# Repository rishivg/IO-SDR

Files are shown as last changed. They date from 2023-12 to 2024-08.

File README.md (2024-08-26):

# IO-SDR_Rev_1.1
 
IO-SDR is an open-source software-defined FPGA radio hardware platform that serves as a successor to the Pluto SDR Learning Module. Support includes and is not limited to:

- dual multichannel transmission and reception
- Gigabit Ethernet connection
- Embedded Linux SoC development
- GNU Radio blocks

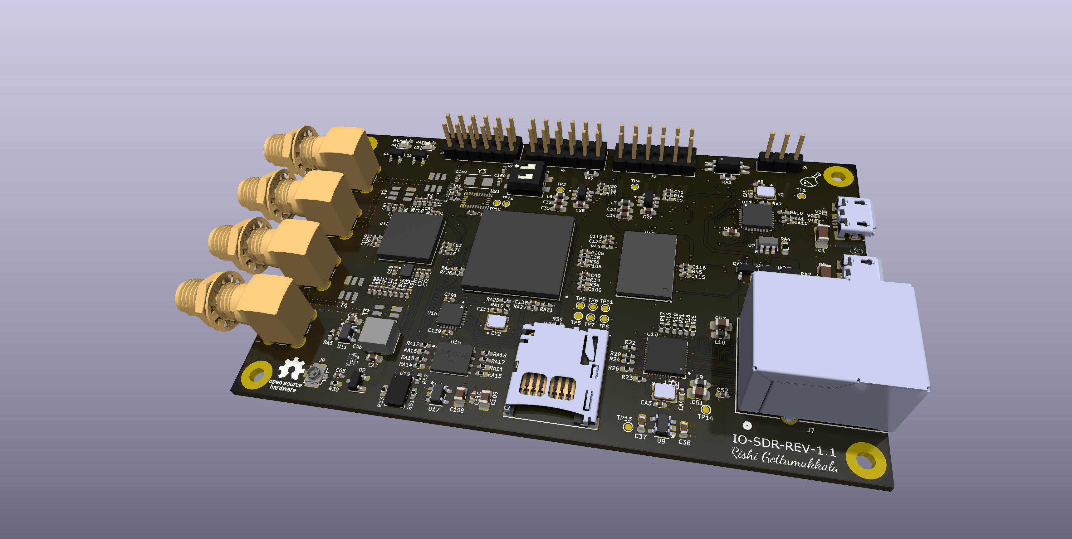
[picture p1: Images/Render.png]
Render


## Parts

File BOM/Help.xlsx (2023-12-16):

Designator | Value | Footprint | JLC PCB Part No | LCSC Part No | Description | Digikey Supplier Part No. | Supplier | Mfr. Part No. | Unit Price (USD) | Quantity | Total Price (USD) | Remarks
C1 | 22uF | Capacitor_SMD:C_1206_3216Metric_Pad1.33x1.80mm_HandSolder | C268012 |  |  |  |  |  |  | 1
C2 | 22uF | Capacitor_SMD:C_1206_3216Metric_Pad1.33x1.80mm_HandSolder | C268012 |  |  |  |  |  |  | 1
C3 | 100uF | Capacitor_SMD:C_0805_2012Metric_Pad1.18x1.45mm_HandSolder |  | C2880375 |  |  |  |  |  | 1
C4 | 22uF | Capacitor_SMD:C_0805_2012Metric_Pad1.18x1.45mm_HandSolder | C4153835 |  |  |  |  |  |  | 1
C5 | 10uF | Capacitor_SMD:C_0805_2012Metric_Pad1.18x1.45mm_HandSolder | C3015161 |  |  |  |  |  |  | 1
C6, C11, C12, C13, C15, C16, C18, C19, C25, C28, C29, C32, C33, C34, C35, CA2 | 10uF | Capacitor_SMD:C_0603_1608Metric_Pad1.08x0.95mm_HandSolder | C3039688 |  |  |  |  |  |  | 16
C7, C8 | 10uF | Capacitor_SMD:C_1206_3216Metric_Pad1.33x1.80mm_HandSolder | C136195 |  |  |  |  |  |  | 2
C9 | 1uF | Capacitor_SMD:C_0805_2012Metric_Pad1.18x1.45mm_HandSolder | C87154 |  |  |  |  |  |  | 1
C10, C14, C30, C31 | 100pF | Capacitor_SMD:C_0402_1005Metric_Pad0.74x0.62mm_HandSolder | C597051 |  |  |  |  |  |  | 4
C17, C20, CA1 | 0.1uF | Capacitor_SMD:C_0402_1005Metric_Pad0.74x0.62mm_HandSolder | C141382 |  |  |  |  |  |  | 3
C21, C23, C26, C27 | 47uF | Capacitor_SMD:C_1206_3216Metric_Pad1.33x1.80mm_HandSolder | C385907 |  |  |  |  |  |  | 4
C22, C24 | 10nF | Capacitor_SMD:C_0402_1005Metric_Pad0.74x0.62mm_HandSolder | C318577 |  |  |  |  |  |  | 2
C36 | 10uF | Capacitor_SMD:C_0603_1608Metric | C3039688 |  |  |  |  |  |  | 1
C37, C50, CA10 | 4.7uF | Capacitor_SMD:C_0603_1608Metric_Pad1.08x0.95mm_HandSolder | C99229 |  |  |  |  |  |  | 3
C38, C40, C41, C42, C43, C44, C45, C46, C47, C48, C49, C92, C93, C97, C98, C101, C102, C103, C104, C107, C138, CA8, CA11 | 0.1uF | Capacitor_SMD:C_0402_1005Metric_Pad0.74x0.62mm_HandSolder | C83056 |  |  |  |  |  |  | 23
C39, C80, C81, C90, C91, C99, C100, C105, C106, C110, C115, C116, C139, C140, C141 | 100nF | Capacitor_SMD:C_0402_1005Metric_Pad0.74x0.62mm_HandSolder | C83056 |  |  |  |  |  |  | 15
C51, C108, C109 | 10uF | Capacitor_SMD:C_0805_2012Metric_Pad1.18x1.45mm_HandSolder | C3015161 |  |  |  |  |  |  | 3
C52, C54, C55, C60, C61, C64, C66, C69, C71, C74, C75, C117, C121, C122, C123, C124, C125, C126, C127, C128, C129, C130, C131, C132, C133, C134, C136, C137 | 10nF | Capacitor_SMD:C_0402_1005Metric_Pad0.74x0.62mm_HandSolder | C318577 |  |  |  |  |  |  | 28
C53 | 0.1uF | Capacitor_SMD:C_0805_2012Metric_Pad1.18x1.45mm_HandSolder | C519980 |  |  |  |  |  |  | 1
C56, C57, C58, C62, C63, C68, C70, C111, C112, C114, C118 | 1uF | Capacitor_SMD:C_0402_1005Metric_Pad0.74x0.62mm_HandSolder | C325464 |  |  |  |  |  |  | 11
C59, CA7, CA9 | 10uF | Capacitor_SMD:C_0603_1608Metric_Pad1.08x0.95mm_HandSolder | C3039688 |  |  |  |  |  |  | 3
C65, C67, C72, C73, C82, C83, C84, C85, C86, C87, C88, C89, CA5, CA6 | 18pF | Capacitor_SMD:C_0402_1005Metric_Pad0.74x0.62mm_HandSolder | C1512022 |  |  |  |  |  |  | 14
C76, C77, C78, C79 | 1nF | Capacitor_SMD:C_0402_1005Metric_Pad0.74x0.62mm_HandSolder | C597052 |  |  |  |  |  |  | 4
C94, C95, C96, C113, C135 | 10uF | Capacitor_SMD:C_0402_1005Metric_Pad0.74x0.62mm_HandSolder | C466623 |  |  |  |  |  |  | 5 |  | Voltage Rating 10V
C119, C120 | 100pF | Capacitor_SMD:C_0402_1005Metric_Pad0.74x0.62mm_HandSolder | C597051 |  |  |  |  |  |  | 2
CA3, CA4 | 12pF | Capacitor_SMD:C_0402_1005Metric_Pad0.74x0.62mm_HandSolder |  |  | CAP CER 12PF 16V C0G/NP0 0402 | 478-KGM05ACG1C120JHTR-ND | Digikey | 478-KGM05ACG1C120JHTR-ND | 0.27 | 2
CY1 | ASDMB-33.333MHZ-LC-T | Libraries:XTAL_ASDMB-33.333MHZ-LC-T |  |  |  |  |  |  |  | 1 |  | Zero stock on Digikey
CY2 | 33.333MHz | Libraries:XTAL_ABM8AIG-25.000MHZ-12-2Z-T3 |  |  |  |  |  |  |  | 1 |  | Zero stock on Digikey
D1 | SUPK24 | Diode_SMD:D_SOD-123 |  |  |  |  |  |  |  | 1 |  | Mfr Not available
D2 | SUP5522F | Package_TO_SOT_SMD:SOT-23-3 |  |  |  |  |  |  |  | 1 |  | Mfr Not available
D3, D4 | LED6 | LED_SMD:LED_0603_1608Metric_Pad1.05x0.95mm_HandSolder | C72043 |  |  |  |  |  |  | 2
H1, H2, H3, H4 | MountingHole_Pad | MountingHole:MountingHole_2.5mm_Pad |  |  |  |  |  |  |  | 4
J1, J2 | 10118193-0001LF | Libraries:AMPHENOL_10118193-0001LF | C132562 |  |  |  |  |  |  | 2
J3 | Conn_01x03_Shielded | Connector_PinHeader_2.54mm:PinHeader_1x03_P2.54mm_Vertical | C5116482 |  |  |  |  |  |  | 1
J4, J5, J6 | CON12-254 | Connector_PinHeader_2.54mm:PinHeader_2x06_P2.54mm_Vertical | C5224012 |  |  |  |  |  |  | 3
J7 | HR911130A1 | Libraries:HR911130A_HAN |  |  |  |  |  |  |  | 1 |  | Mfr Not available
J8 | 73412-0110 | Connector_Coaxial:U.FL_Molex_MCRF_73412-0110_Vertical |  |  | CONN UMC RCPT STR 50 OHM SMD | 734120110 | Digikey | WM5587TR-ND | 0.79 | 1
J9, J10, J11, J12 | RF2-49B-T-00-50-G-HDW | Libraries:ADAMTECH_RF2-49B-T-00-50-G-HDW |  |  | RF SMA CONNECTOR | RF2-49B-T-00-50-G-HDW | Digikey | 2057-RF2-49B-T-00-50-G-HDW-ND | 3.76 | 4
J13 | 502570-0893 | Libraries:MOLEX_502570-0893 |  |  | CONN MICRO SD CARD PUSH-PUSH R/A | 5025700893 | Digikey | WM19093TR-ND | 4.42 | 1
L1, L4, L7, L8, L9 | 2.2uH | Inductor_SMD:L_0603_1608Metric_Pad1.05x0.95mm_HandSolder | C95966 |  |  |  |  |  |  | 5
L2 | R0603 | Inductor_SMD:L_0603_1608Metric_Pad1.05x0.95mm_HandSolder |  |  |  |  |  |  |  | 1 | 0 | Inductance not given
L3, L5 | R0805 | Inductor_SMD:L_0805_2012Metric_Pad1.05x1.20mm_HandSolder |  |  |  |  |  |  |  | 2
L6 | R0402 | Inductor_SMD:L_0402_1005Metric_Pad0.77x0.64mm_HandSolder |  |  |  |  |  |  |  | 1
L10 | BLM18PG181SN1 | Inductor_SMD:L_0603_1608Metric_Pad1.05x0.95mm_HandSolder | C82850 |  |  |  |  |  |  | 1
L11, L13 | 330nH | Inductor_SMD:L_0402_1005Metric_Pad0.77x0.64mm_HandSolder | C524943 |  |  |  |  |  |  | 2
L12, L14 | 330nF | Inductor_SMD:L_0402_1005Metric_Pad0.77x0.64mm_HandSolder | C524943 |  |  |  |  |  |  | 2
Q1, Q2 | S8050 | Package_TO_SOT_SMD:SOT-23 | C909746 |  |  |  |  |  |  | 2
Q3, Q4 | HR8020GS9 | Libraries:SOT23 MOSFET FOOT PRINT |  |  |  |  |  |  |  | 2 |  | Value not Given
QA1, QA3 | HR8031GS6 | Libraries:HR8031GS6 |  |  |  |  |  |  |  | 2
QA2 | HR8031GS6 | Libraries:HR8031GS6 |  |  |  |  |  |  |  | 1
R1, RA19, RA20 | 33R | Resistor_SMD:R_0402_1005Metric_Pad0.72x0.64mm_HandSolder | C100638 |  |  |  |  |  |  | 3
R2, R3, R7, R15, R22, RA6 | 10K | Resistor_SMD:R_0402_1005Metric_Pad0.72x0.64mm_HandSolder | C881063 |  |  |  |  |  |  | 6
R4, R8, R10 | 7.5K | Resistor_SMD:R_0402_1005Metric_Pad0.72x0.64mm_HandSolder | C294643 |  |  |  |  |  |  | 3
R5 | 2K | Resistor_SMD:R_0402_1005Metric_Pad0.72x0.64mm_HandSolder | C304583 |  |  |  |  |  |  | 1
R6, RA11, RA13, RA15, RA16, RA17, RA21, RA22, RA23, RA25, RA27 | 20K | Resistor_SMD:R_0402_1005Metric_Pad0.72x0.64mm_HandSolder | C328310 |  |  |  |  |  |  | 11
R9, R11 | 12K | Resistor_SMD:R_0402_1005Metric_Pad0.72x0.64mm_HandSolder | C317927 |  |  |  |  |  |  | 2
R12 | 3.3K | Resistor_SMD:R_0402_1005Metric_Pad0.72x0.64mm_HandSolder | C310224 |  |  |  |  |  |  | 1
R13, R39, R40, R41, R42, R43, R46, RA28, RA29 | 4.7K | Resistor_SMD:R_0402_1005Metric_Pad0.72x0.64mm_HandSolder | C103059 |  |  |  |  |  |  | 9
R14 | 15K | Resistor_SMD:R_0402_1005Metric_Pad0.72x0.64mm_HandSolder | C144795 |  |  |  |  |  |  | 1
R16, R17, R18, R19, R20, R24, R25, R26 | 4K7 | Resistor_SMD:R_0402_1005Metric_Pad0.72x0.64mm_HandSolder | C140158 |  |  |  |  |  |  | 8
R21 | 1K5 | Resistor_SMD:R_0402_1005Metric_Pad0.72x0.64mm_HandSolder | C102811 |  |  |  |  |  |  | 1
R23 | 2.49K%1 | Resistor_SMD:R_0402_1005Metric_Pad0.72x0.64mm_HandSolder | C409686 |  |  |  |  |  |  | 1
R27, R28 | 510R R0402 5% | Resistor_SMD:R_0402_1005Metric_Pad0.72x0.64mm_HandSolder | C881122 |  |  |  |  |  |  | 2
R29 | 50K | Potentiometer_SMD:Potentiometer_Bourns_3214W_Vertical |  |  |  |  |  |  |  | 1 |  | Mfr not given
R30 | ESD | Resistor_SMD:R_0402_1005Metric_Pad0.72x0.64mm_HandSolder |  |  |  |  |  |  |  | 1 |  | Value not given
R31, R32 | 1R | Resistor_SMD:R_0402_1005Metric_Pad0.72x0.64mm_HandSolder | C227331 |  |  |  |  |  |  | 2
R33, R34, R35, R36, R44, R45, RA1, RA2 | 2.4K | Resistor_SMD:R_0402_1005Metric_Pad0.72x0.64mm_HandSolder | C409053 |  |  |  |  |  |  | 8
R37, R38, R48 | 80.5R | Resistor_SMD:R_0402_1005Metric_Pad0.72x0.64mm_HandSolder | C170360 |  |  |  |  |  |  | 3
R47 | 240R | Resistor_SMD:R_0402_1005Metric_Pad0.72x0.64mm_HandSolder | C407743 |  |  |  |  |  |  | 1
RA3 | 4.7K | Resistor_SMD:R_0603_1608Metric_Pad0.98x0.95mm_HandSolder | C116697 |  |  |  |  |  |  | 1
RA4 | 5.1K | Resistor_SMD:R_0603_1608Metric_Pad0.98x0.95mm_HandSolder | C103696 |  |  |  |  |  |  | 1
RA5 | 0R | Resistor_SMD:R_0603_1608Metric_Pad0.98x0.95mm_HandSolder | C510292 |  |  |  |  |  |  | 1
RA7 | 1M | Resistor_SMD:R_0402_1005Metric_Pad0.72x0.64mm_HandSolder | C279988 |  |  |  |  |  |  | 1
RA8 | 14.3K | Resistor_SMD:R_0402_1005Metric_Pad0.72x0.64mm_HandSolder | C162939 |  |  |  |  |  |  | 1
RA9 | 20K | Resistor_SMD:R_0402_1005Metric_Pad0.72x0.64mm_HandSolder | C328310 |  |  |  |  |  |  | 1
RA10 | 8.06K | Resistor_SMD:R_0402_1005Metric_Pad0.72x0.64mm_HandSolder | C162792 |  |  |  |  |  |  | 1
RA12, RA14, RA18 | 1K | Resistor_SMD:R_0402_1005Metric_Pad0.72x0.64mm_HandSolder | C138287 |  |  |  |  |  |  | 3
RA24, RA26 | 100K | Resistor_SMD:R_0402_1005Metric_Pad0.72x0.64mm_HandSolder | C176119 |  |  |  |  |  |  | 2
SW1 | SW_DIP_x02 | Button_Switch_SMD:SW_DIP_SPSTx02_Slide_6.7x6.64mm_W6.73mm_P2.54mm_LowProfile_JPin |  |  |  |  |  |  |  | 1 |  | Mfr not given
T1, T2, T3, T4 | B0310J50100AHF | USB3320C-EZK-TR:B0310J50100AHF |  |  | BALUN 300MHZ-1GHZ 50/100 0805 | 1173-1050-2-ND | Digikey | B0310J50100AHF | 1.36 | 4
TP1, TP2, TP3, TP4, TP5, TP6, TP7, TP8, TP9, TP10, TP11, TP12, TP13, TP14 | TestPoint | TestPoint:TestPoint_Pad_D1.0mm |  |  |  |  |  |  |  | 14
U1 | TCMT1107 | Package_SO:SOP-4_4.4x2.6mm_P1.27mm | C81148 |  |  |  |  |  |  | 1
U2 | SY6280AAC | Libraries:SY6280AAC | C207620 |  |  |  |  |  |  | 1
U3 | TCS4615 | Libraries:TCS4615 |  |  |  |  |  |  |  | 1 |  | Not Available on Digikey
U4 | TCS4615 | Libraries:TCS4615 |  |  |  |  |  |  |  | 1 |  | Not Available on Digikey
U5 | TPS7A8101DRBT | Libraries:TPS7A8101DRBT | C139650 |  |  |  |  |  |  | 1
U6 | TPS7A8101DRBT | Libraries:TPS7A8101DRBT | C139650 |  |  |  |  |  |  | 1
U7 | TCS4615 | Libraries:TCS4615 |  |  |  |  |  |  |  | 1 |  | Not Available on Digikey
U8 | TCS4615 | Libraries:TCS4615 |  |  |  |  |  |  |  | 1 |  | Not Available on Digikey
U9, U11, U17 | RT9193-33B | Libraries:RT9193-33B |  |  |  |  |  |  |  | 3 |  | Not Available on Digikey
U10 | RTL8211E-VB-CG | Libraries:RTL8211E-VB-CG | C90735 |  |  |  |  |  |  | 1
U12 | AD9361BBCZ | Libraries:AD9361BBCZ | C515884 |  |  |  |  |  |  | 1
U13 | USB3320C-EZK-TR | Libraries:USB3320C-EZK-TR | C132156 |  |  |  |  |  |  | 1
U14 | XC7Z010-1CLG400I | Libraries:XC7Z010-1CLG400I | C2840994 |  |  |  |  |  |  | 1
U15 | MX25U1635EZNI-10G | Libraries:MX25U1635EZNI-10G |  |  | IC FLASH 16MBIT SPI/QUAD 8WSON | 1092-1076-ND | Digikey | MX25U1635EZNI-10G | 1.08 | 1
U16 | TXS02612RTWR | Libraries:TXS02612RTWR | C140276 |  |  |  |  |  |  | 1
U18 | H5TQ4G63AFR | Libraries:H5TQ4G63AFR |  |  |  |  |  |  |  | 1
V1, V2, V3 | HR02X5V | Libraries:HR02X5V |  |  |  |  |  |  |  | 3
Y1 | 25MHz | Libraries:XTAL_TSX-3225_25.0000MF10P-C0 |  |  | CRYSTAL 25.0000MHZ 18PF SMD | TSX-322525.0000MF10P-C-ND | Digikey | TSX-3225 25.0000MF10P-C | 0.84 | 1
Y2 | 25MHz | Libraries:XTAL_TSX-3225_25.0000MF10P-C0 |  |  | CRYSTAL 25.0000MHZ 18PF SMD | TSX-322525.0000MF10P-C-ND | Digikey | TSX-3225 25.0000MF10P-C | 0.84 | 1

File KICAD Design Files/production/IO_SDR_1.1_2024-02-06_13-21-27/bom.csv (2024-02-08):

Designator | Footprint | Quantity | Value | LCSC Part #
C1, C2 | 1206 | 2 | 22uF
C10, C119, C120, C14, C30, C31 | 0402 | 6 | 100pF
C100, C105, C106, C110, C115, C116, C139, C140, C141, C146, C147, C39, C80, C81, C90, C91, C99 | 0402 | 17 | 100nF
C101, C102, C103, C104, C107, C138, C17, C20, C38, C40, C41, C42, C43, C44, C45, C46, C47, C48, C49, C92, C93, C97, C98, CA1, CA11, CA8 | 0402 | 26 | 0.1uF
C108, C109, C5, C51 | 0805 | 4 | 10uF
C11, C12, C13, C15, C16, C18, C19, C25, C28, C29, C32, C33, C34, C35, C36, C59, C6, CA2, CA7, CA9 | 0603 | 20 | 10uF
C111, C112, C114, C118, C148, C56, C57, C58, C62, C63, C68, C70 | 0402 | 12 | 1uF
C113, C135, C94, C95, C96 | 0402 | 5 | 10uF
C117, C121, C122, C123, C124, C125, C126, C127, C128, C129, C130, C131, C132, C133, C134, C136, C137, C22, C24, C52, C54, C55, C60, C61, C64, C66, C69, C71, C74, C75 | 0402 | 30 | 10nF
C149, C150 | 0402 | 2 | 22pf
C21, C23, C26, C27 | 1206 | 4 | 47uF
C3 | 0805 | 1 | 100uF
C37, C50, CA10 | 0603 | 3 | 4.7uF
C4 | 0805 | 1 | 22uF
C53 | 0805 | 1 | 0.1uF
C65, C67, C72, C73, C82, C83, C84, C85, C86, C87, C88, C89, CA5, CA6 | 0402 | 14 | 18pF
C7, C8 | 1206 | 2 | 10uF
C76, C77, C78, C79 | 0402 | 4 | 1nF
C9 | 0805 | 1 | 1uF
CA3, CA4 | 0402 | 2 | 12pF
CY1 | ASDMB-33.333MHZ-XY-T | 1 | ASDMB-33.333MHZ-XY-T
CY2 | ABM8AIG-33.000MHZ-12-D2Z-T | 1 | ABM8AIG-33.000MHZ-12-D2Z-T
D1 | D_SOD-123 | 1 | DSK24
D2 | SOT-23-3 | 1 | WSB5522F-3/TR
D3, D4 | 0603 | 2 | LED6
J13 | 5025700893 | 1 | 5025700893
L1, L4, L7, L8, L9 | 0603 | 5 | 2.2uH
L10 | 0603 | 1 | BLM18PG181SN1 | AD93
L11, L13 | 0402 | 2 | 330nH
L12, L14 | 0402 | 2 | 330nF
L2 | BLM18AG601SN1D | 1 | BLM18AG601SN1D
L3, L5 | 7427920415 | 2 | 7427920415
L6 | BLM15AG601SN1D | 1 | BLM15AG601SN1D
Q1, Q2 | SOT-23 | 2 | S8050
Q3, Q4 | SOT23 MOSFET FOOT PRINT | 2 | ~
QA1, QA2, QA3 | HR8031GS6 | 3 | HR8031GS6
R1, RA19, RA20 | 0402 | 3 | 33R
R10, R4, R8 | 0402 | 3 | 7.5K
R11, R9 | 0402 | 2 | 12K
R12 | 0402 | 1 | 3.3K
R13, R39, R40, R41, R42, R43, R46, R51, R52, R53, RA28, RA29 | 0402 | 12 | 4.7K
R14 | 0402 | 1 | 15K
R15, R2, R22, R3, R56, R7, RA6 | 0402 | 7 | 10K
R16, R17, R18, R19, R20, R24, R25, R26 | 0402 | 8 | 4K7
R21 | 0402 | 1 | 1K5
R23 | 0402 | 1 | 2.49K%1
R27, R28 | 0402 | 2 | 510R
R29 | Potentiometer_Bourns_3214W_Vertical | 1 | 50K
R30 | 0402 | 1 | ESD
R31, R32 | 0402 | 2 | 1R
R33, R34, R35, R36, R44, R45, RA1, RA2 | 0402 | 8 | 2.4K
R37, R38, R48 | 0402 | 3 | 80.6R
R47 | 0402 | 1 | 240R
R5 | 0402 | 1 | 2K
R6, RA11, RA13, RA15, RA16, RA17, RA21, RA22, RA23, RA25, RA27, RA9 | 0402 | 12 | 20K
RA10 | 0402 | 1 | 8.06K
RA12, RA14, RA18 | 0402 | 3 | 1K
RA24, RA26 | 0402 | 2 | 100K
RA3 | 0603 | 1 | 4.7K
RA4 | 0603 | 1 | 5.1K
RA5 | 0603 | 1 | 0R
RA7 | 0402 | 1 | 1M
RA8 | 0402 | 1 | 14.3K
T1, T2, T3, T4 | XFMR_TCM1-63AX+ | 4 | TCM1-63AX+
U1 | SOP-4_4.4x2.6mm_P1.27mm | 1 | TCMT1107
U10 | RTL8211E-VB-CG | 1 | RTL8211E-VB-CG
U11, U17, U9 | RT9193-33GB | 3 | RT9193-33GB
U12 | AD9363BBCZ | 1 | AD9363BBCZ
U13 | USB3320C-EZK-TR | 1 | USB3320C-EZK-TR
U14 | XC7Z010-1CLG400I | 1 | XC7Z010-1CLG400I
U15 | MX25U1635EZNI-10G | 1 | MX25U1635EZNI-10G
U16 | TXS02612RTWR | 1 | TXS02612RTWR
U18 | H5TQ4G63EFR-RDC | 1 | H5TQ4G63EFR-RDC
U19 | LGA-8_3x5mm_P1.25mm | 1 | MS5611-01BA03
U2 | SY6280AAC | 1 | SY6280AAC
U21 | IC_BNO080 | 1 | BNO085
U3, U7, U8 | TCS4615 | 3 | TCS4615
U4 | TCS4615 | 1 | TCS4615
U5, U6 | TPS7A8101DRBT | 2 | TPS7A8101DRBT
V1, V2, V3 | HR02X5V | 3 | HR02X5V
Y1 | TSX-3225 25.0000MF10P-C0 | 1 | 25MHz | TSX-3225 25.0000MF10P-C0
Y2 | TSX-3225 25.0000MF10P-C0 | 1 | 25MHz
Y3 | Crystal_SMD_Qantek_QC5CB-2Pin_5x3.2mm | 1 | 32.768kHz

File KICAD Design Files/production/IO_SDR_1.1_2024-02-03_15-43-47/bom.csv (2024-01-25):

Designator | Footprint | Quantity | Value | LCSC Part #
C1, C2 | 1206 | 2 | 22uF
C10, C119, C120, C14, C30, C31 | 0402 | 6 | 100pF
C100, C105, C106, C110, C115, C116, C139, C140, C141, C146, C147, C39, C80, C81, C90, C91, C99 | 0402 | 17 | 100nF
C101, C102, C103, C104, C107, C138, C17, C20, C38, C40, C41, C42, C43, C44, C45, C46, C47, C48, C49, C92, C93, C97, C98, CA1, CA11, CA8 | 0402 | 26 | 0.1uF
C108, C109, C5, C51 | 0805 | 4 | 10uF
C11, C12, C13, C15, C16, C18, C19, C25, C28, C29, C32, C33, C34, C35, C36, C59, C6, CA2, CA7, CA9 | 0603 | 20 | 10uF
C111, C112, C114, C118, C148, C56, C57, C58, C62, C63, C68, C70 | 0402 | 12 | 1uF
C113, C135, C94, C95, C96 | 0402 | 5 | 10uF
C117, C121, C122, C123, C124, C125, C126, C127, C128, C129, C130, C131, C132, C133, C134, C136, C137, C22, C24, C52, C54, C55, C60, C61, C64, C66, C69, C71, C74, C75 | 0402 | 30 | 10nF
C149, C150 | 0402 | 2 | 22pf
C21, C23, C26, C27 | 1206 | 4 | 47uF
C3 | 0805 | 1 | 100uF
C37, C50, CA10 | 0603 | 3 | 4.7uF
C4 | 0805 | 1 | 22uF
C53 | 0805 | 1 | 0.1uF
C65, C67, C72, C73, C82, C83, C84, C85, C86, C87, C88, C89, CA5, CA6 | 0402 | 14 | 18pF
C7, C8 | 1206 | 2 | 10uF
C76, C77, C78, C79 | 0402 | 4 | 1nF
C9 | 0805 | 1 | 1uF
CA3, CA4 | 0402 | 2 | 12pF
CY1 | XTAL_ASDMB-33.333MHZ-LC-T | 1 | ASDMB-33.333MHZ-LC-T
CY2 | XTAL_ABM8AIG-25.000MHZ-12-2Z-T3 | 1 | 33.333MHz
D1 | D_SOD-123 | 1 | SUPK24
D2 | SOT-23-3 | 1 | SUP5522F
D3, D4 | 0603 | 2 | LED6
H1, H2, H3, H4 | MountingHole_2.5mm_Pad | 4 | MountingHole_Pad
J1, J2 | AMPHENOL_10118193-0001LF | 2 | 10118193-0001LF
J10, J11, J12, J9 | ADAMTECH_RF2-49B-T-00-50-G-HDW | 4 | RF2-49B-T-00-50-G-HDW
J13 | MOLEX_502570-0893 | 1 | 502570-0893
J3 | PinHeader_1x03_P2.54mm_Vertical | 1 | Conn_01x03_Shielded
J4, J5, J6 | PinHeader_2x06_P2.54mm_Vertical | 3 | CON12-254
J7 | HR911130A_HAN | 1 | HR911130A1
J8 | U.FL_Molex_MCRF_73412-0110_Vertical | 1 | 73412-0110
L1, L4, L7, L8, L9 | 0603 | 5 | 2.2uH
L10 | 0603 | 1 | BLM18PG181SN1
L11, L13 | 0402 | 2 | 330nH
L12, L14 | 0402 | 2 | 330nF
L2 | 0603 | 1 | R0603
L3, L5 | 0805 | 2 | R0805
L6 | 0402 | 1 | R0402
Q1, Q2 | SOT-23 | 2 | S8050
Q3, Q4 | SOT23 MOSFET FOOT PRINT | 2 | ~
QA1, QA2, QA3 | HR8031GS6 | 3 | HR8031GS6
R1, RA19, RA20 | 0402 | 3 | 33R
R10, R4, R8 | 0402 | 3 | 7.5K
R11, R9 | 0402 | 2 | 12K
R12 | 0402 | 1 | 3.3K
R13, R39, R40, R41, R42, R43, R46, R51, R52, R53, RA28, RA29 | 0402 | 12 | 4.7K
R14 | 0402 | 1 | 15K
R15, R2, R22, R3, R56, R7, RA6 | 0402 | 7 | 10K
R16, R17, R18, R19, R20, R24, R25, R26 | 0402 | 8 | 4K7
R21 | 0402 | 1 | 1K5
R23 | 0402 | 1 | 2.49K%1
R27, R28 | 0402 | 2 | 510R R0402 5%
R29 | Potentiometer_Bourns_3214W_Vertical | 1 | 50K
R30 | 0402 | 1 | ESD
R31, R32 | 0402 | 2 | 1R
R33, R34, R35, R36, R44, R45, RA1, RA2 | 0402 | 8 | 2.4K
R37, R38, R48 | 0402 | 3 | 80.5R
R47 | 0402 | 1 | 240R
R5 | 0402 | 1 | 2K
R6, RA11, RA13, RA15, RA16, RA17, RA21, RA22, RA23, RA25, RA27, RA9 | 0402 | 12 | 20K
RA10 | 0402 | 1 | 8.06K
RA12, RA14, RA18 | 0402 | 3 | 1K
RA24, RA26 | 0402 | 2 | 100K
RA3 | 0603 | 1 | 4.7K
RA4 | 0603 | 1 | 5.1K
RA5 | 0603 | 1 | 0R
RA7 | 0402 | 1 | 1M
RA8 | 0402 | 1 | 14.3K
SW1 | SW_DIP_SPSTx02_Slide_6.7x6.64mm_W6.73mm_P2.54mm_LowProfile_JPin | 1 | SW_DIP_x02
T1, T2, T3, T4 | XFMR_TCM1-63AX_ | 4 | TCM1-63AX_
TP1, TP10, TP11, TP12, TP13, TP14, TP2, TP3, TP4, TP5, TP6, TP7, TP8, TP9 | TestPoint_Pad_D1.0mm | 14 | TestPoint
U1 | SOP-4_4.4x2.6mm_P1.27mm | 1 | TCMT1107
U10 | RTL8211E-VB-CG | 1 | RTL8211E-VB-CG
U11, U17, U9 | RT9193-33B | 3 | RT9193-33B
U12 | AD9361BBCZ | 1 | AD9361BBCZ
U13 | USB3320C-EZK-TR | 1 | USB3320C-EZK-TR
U14 | XC7Z010-1CLG400I | 1 | XC7Z010-1CLG400I
U15 | MX25U1635EZNI-10G | 1 | MX25U1635EZNI-10G
U16 | TXS02612RTWR | 1 | TXS02612RTWR
U18 | H5TQ4G63AFR | 1 | H5TQ4G63AFR
U19 | LGA-8_3x5mm_P1.25mm | 1 | MS5611-01BA
U2 | SY6280AAC | 1 | SY6280AAC
U21 | IC_BNO080 | 1 | BNO085
U3, U7, U8 | TCS4615 | 3 | TCS4615
U4 | TCS4615 | 1 | TCS4615
U5, U6 | TPS7A8101DRBT | 2 | TPS7A8101DRBT
V1, V2, V3 | HR02X5V | 3 | HR02X5V
Y1 | XTAL_TSX-3225_25.0000MF10P-C0 | 1 | 25MHz | TSX-3225_25.0000MF10P-C0
Y2 | XTAL_TSX-3225_25.0000MF10P-C0 | 1 | 25MHz
Y3 | Crystal_SMD_Qantek_QC5CB-2Pin_5x3.2mm | 1 | 32.768kHz

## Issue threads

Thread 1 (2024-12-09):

IO-SDR board license

goran-mahovlic, 2024-12-09:
HI @rishivg, thank you for sharing this board it looks super nice!
I was searching for ETH PHY for my extension boards so I found your SDR board.
Just checked design and it looks fantastic!

If possible I would like to reuse your ETH PHY on experimental Extension boards for Olimex https://github.com/intergalaktik/Extension_Boards_for_Olimex_GateMate

But before I reuse part of your design I just wanted to ask you if this is OK with you, and if it is what is your board license.

by the way there is now PCB2BLENDER plugin for KiCad - try to use it as blender render looks really amazing!

https://github.com/30350n/pcb2blender

Thanks again!
Goran

rishivg, 2024-12-11:
Hi, my board license is currently set to GPL-3.0. Yes, It is totally ok if you use the ETH PHY, and thanks for the blender recommendation!

goran-mahovlic, 2024-12-11:
> Hi, my board license is currently set to GPL-3.0. Yes, It is totally ok if you use the ETH PHY, and thanks for the blender recommendation!

Thank you!

I have already created repository ethIO - I just added schematic links of your repository so that users can trace development.

https://github.com/intergalaktik/Extension_Boards_for_Olimex_GateMate/blob/main/ethIO/ethIO.pdf

I do not know if GPL-3.0 is valid for HW projects - but I will ask NLnet what would complement that license, until lthen I have change license to GPLv3

I use CERN-OHL-S v2 or CERN-OHL-P v2 on all boards...

I think CERN-OHL-P would be almost like GPLv3 for SW

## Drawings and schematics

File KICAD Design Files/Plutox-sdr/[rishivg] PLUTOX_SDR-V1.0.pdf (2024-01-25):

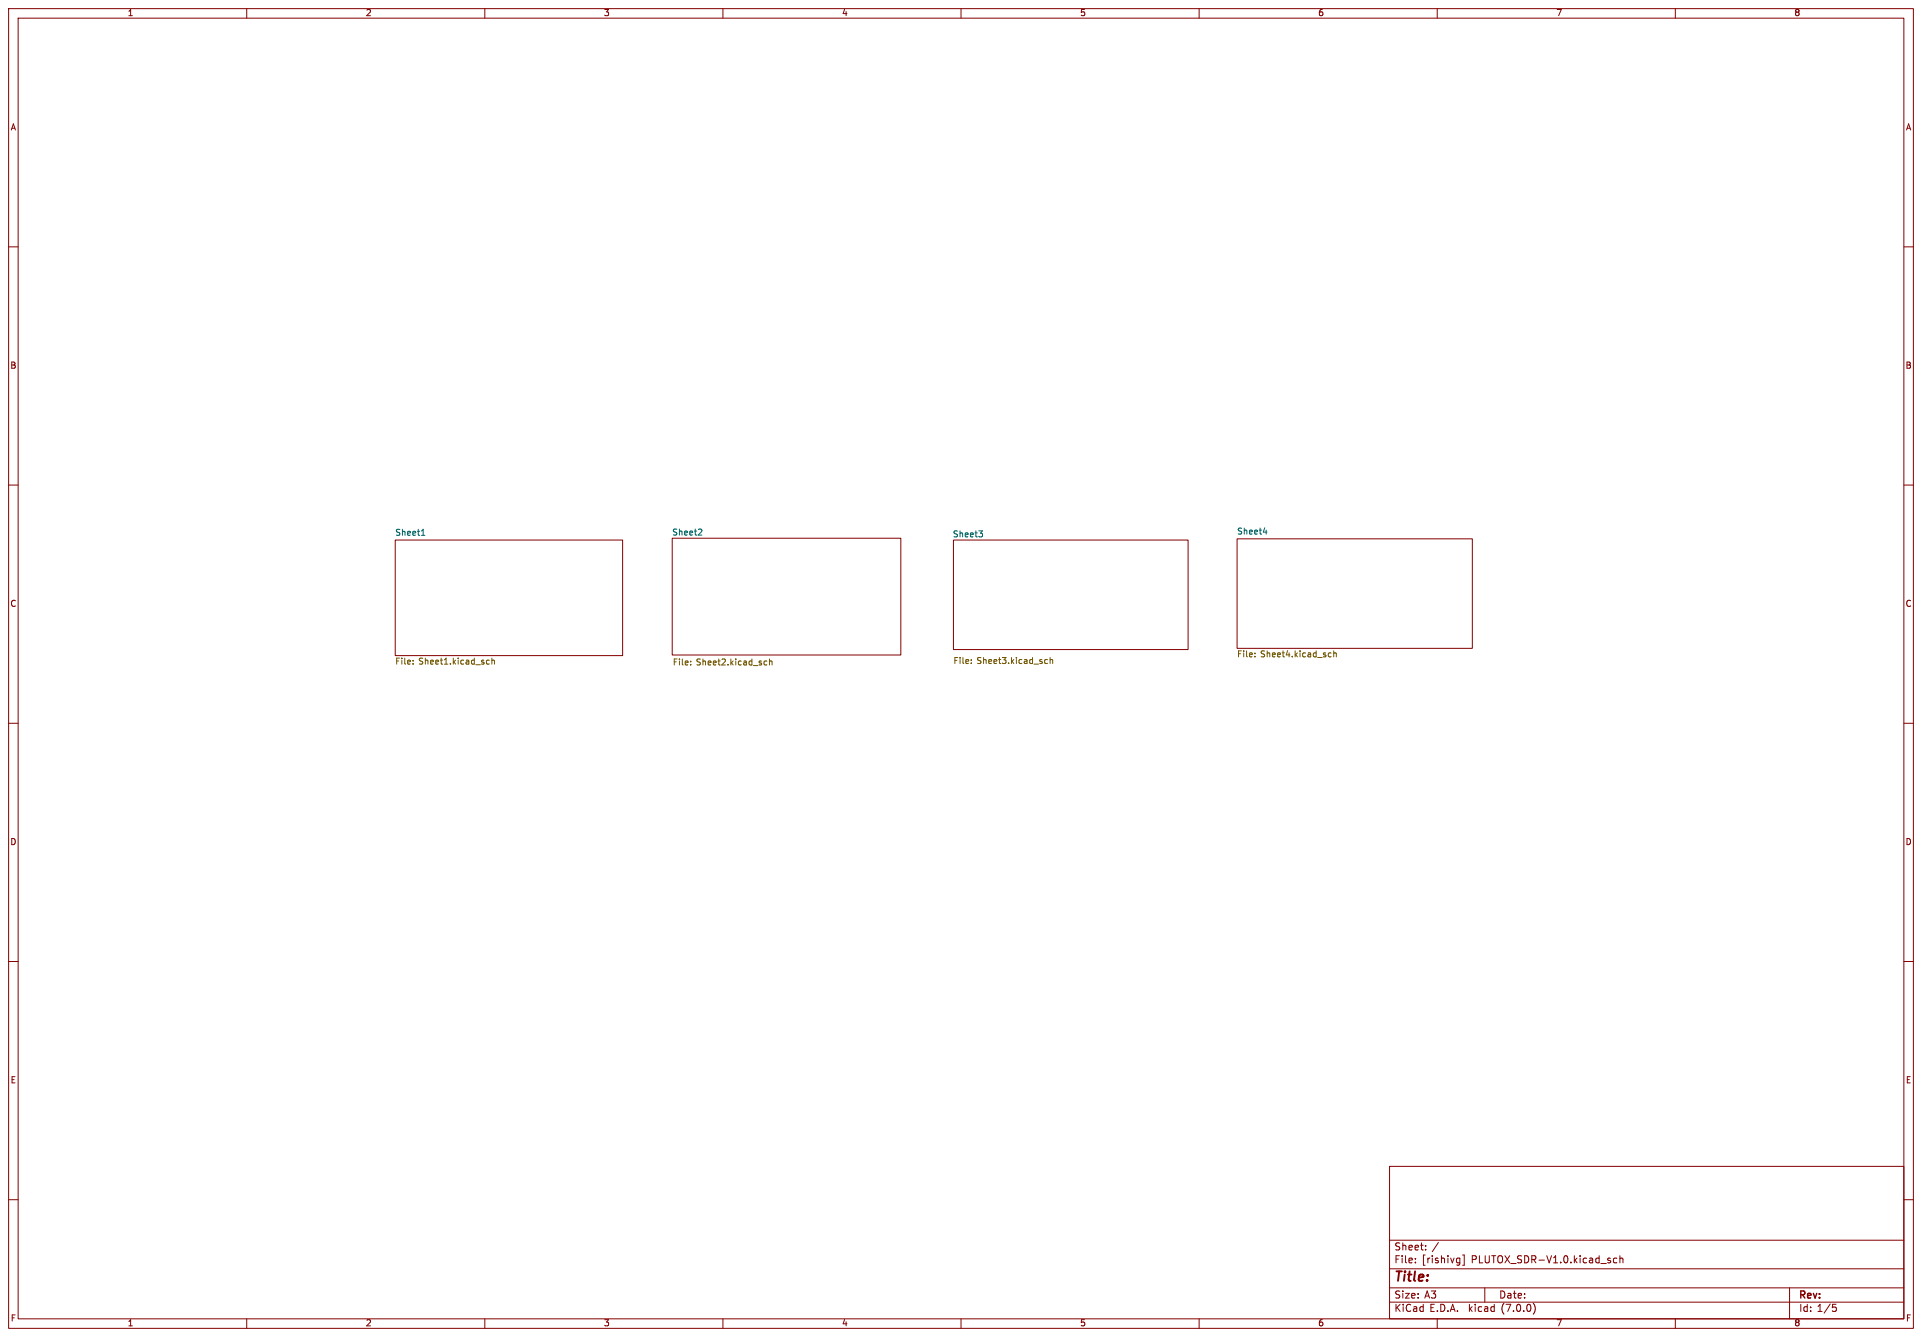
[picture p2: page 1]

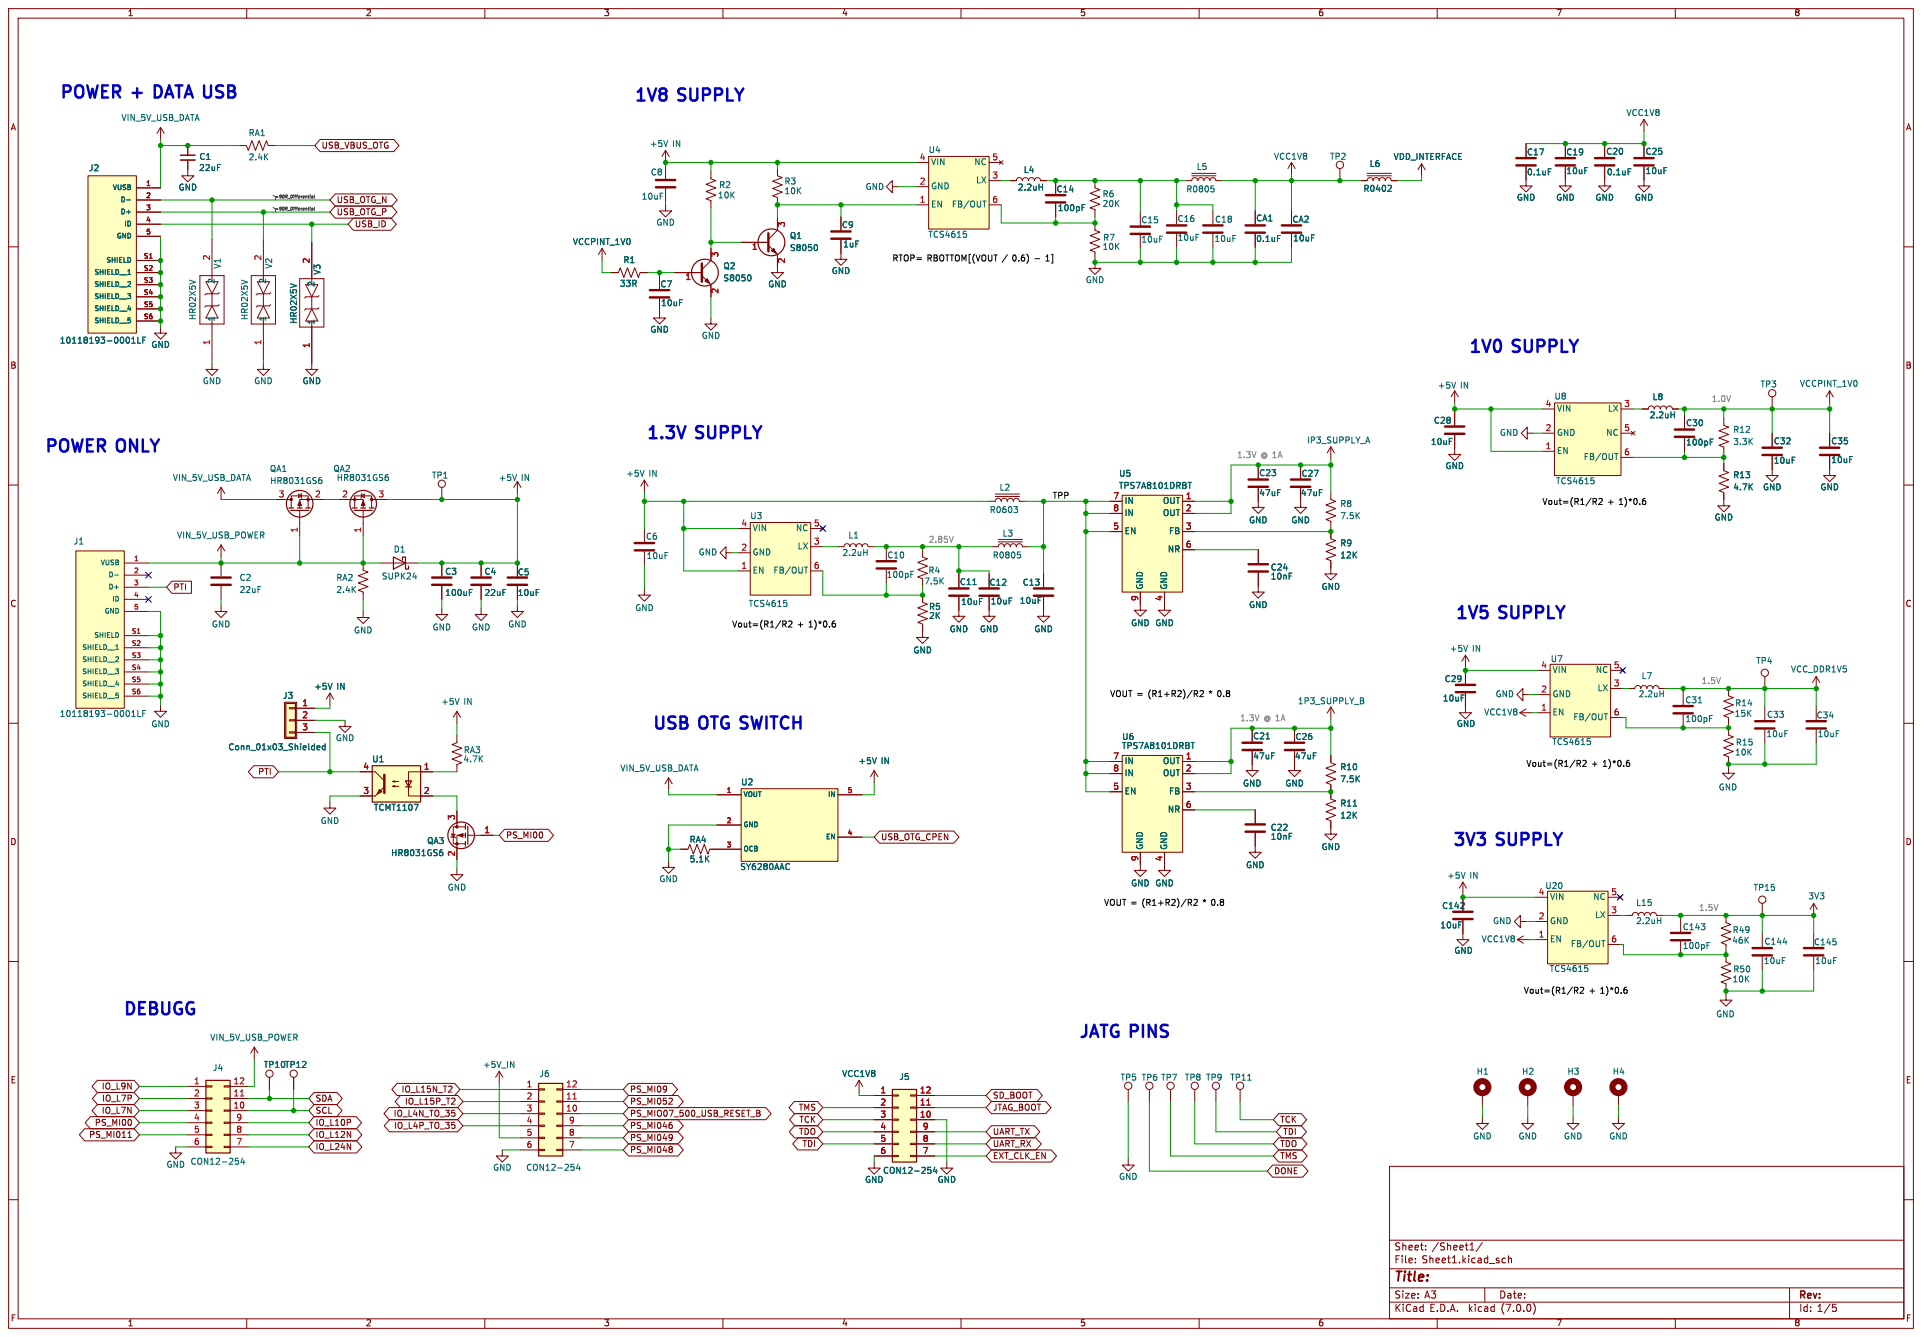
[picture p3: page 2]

47uF U6 TPS7A8101DRBT OUT 1 OUT 2 FB 3 GND

47uF OUT 1 OUT 2 FB 3 GND

Id: 1/5 Title: File: Sheet1.kicad_sch Sheet: /Sheet1/

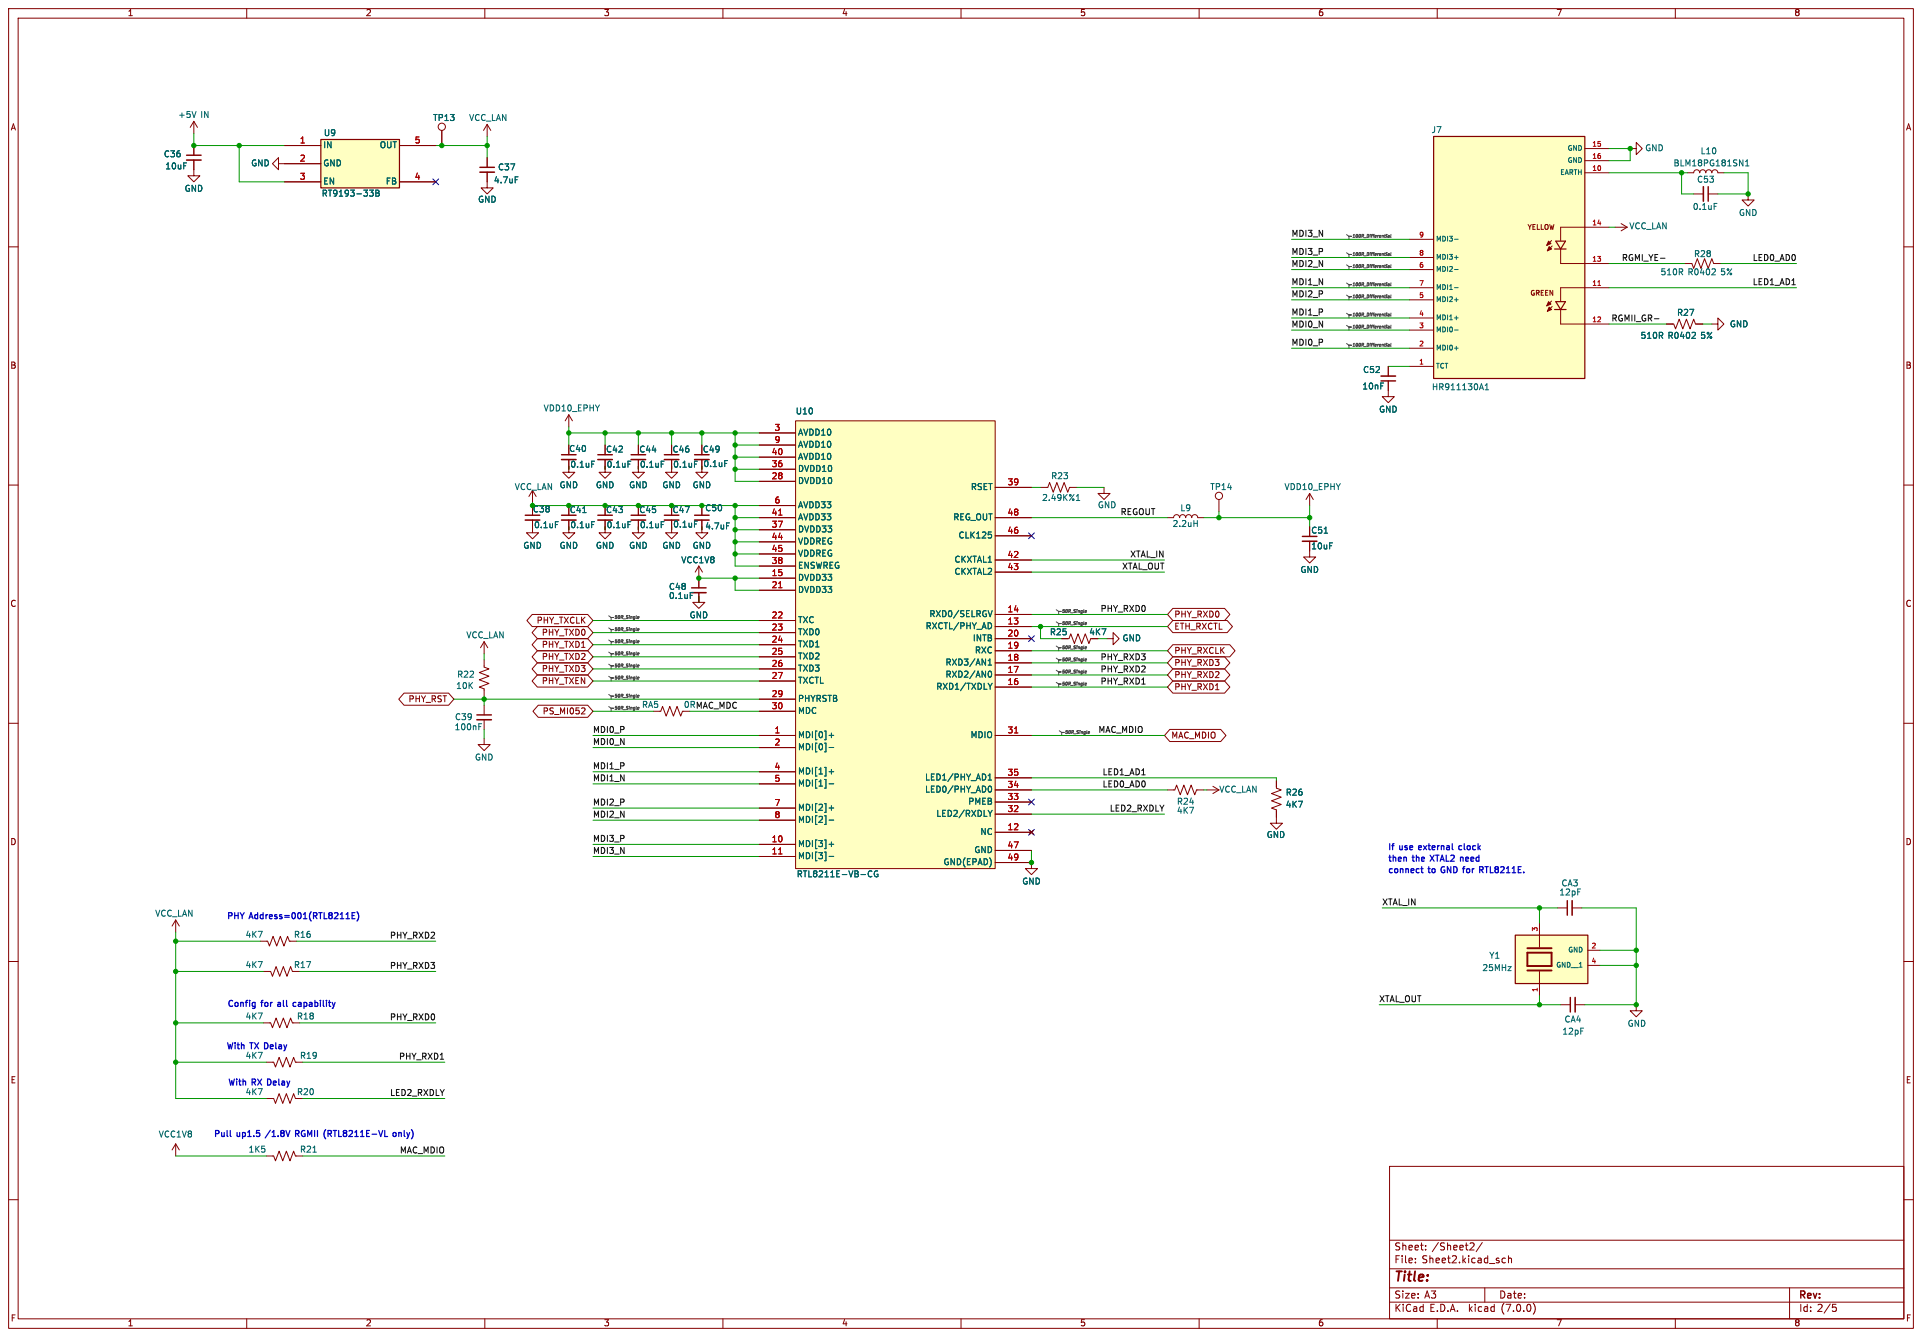
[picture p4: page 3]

connect to GND for RTL8211E.

Config for all capability With TX Delay With RX Delay

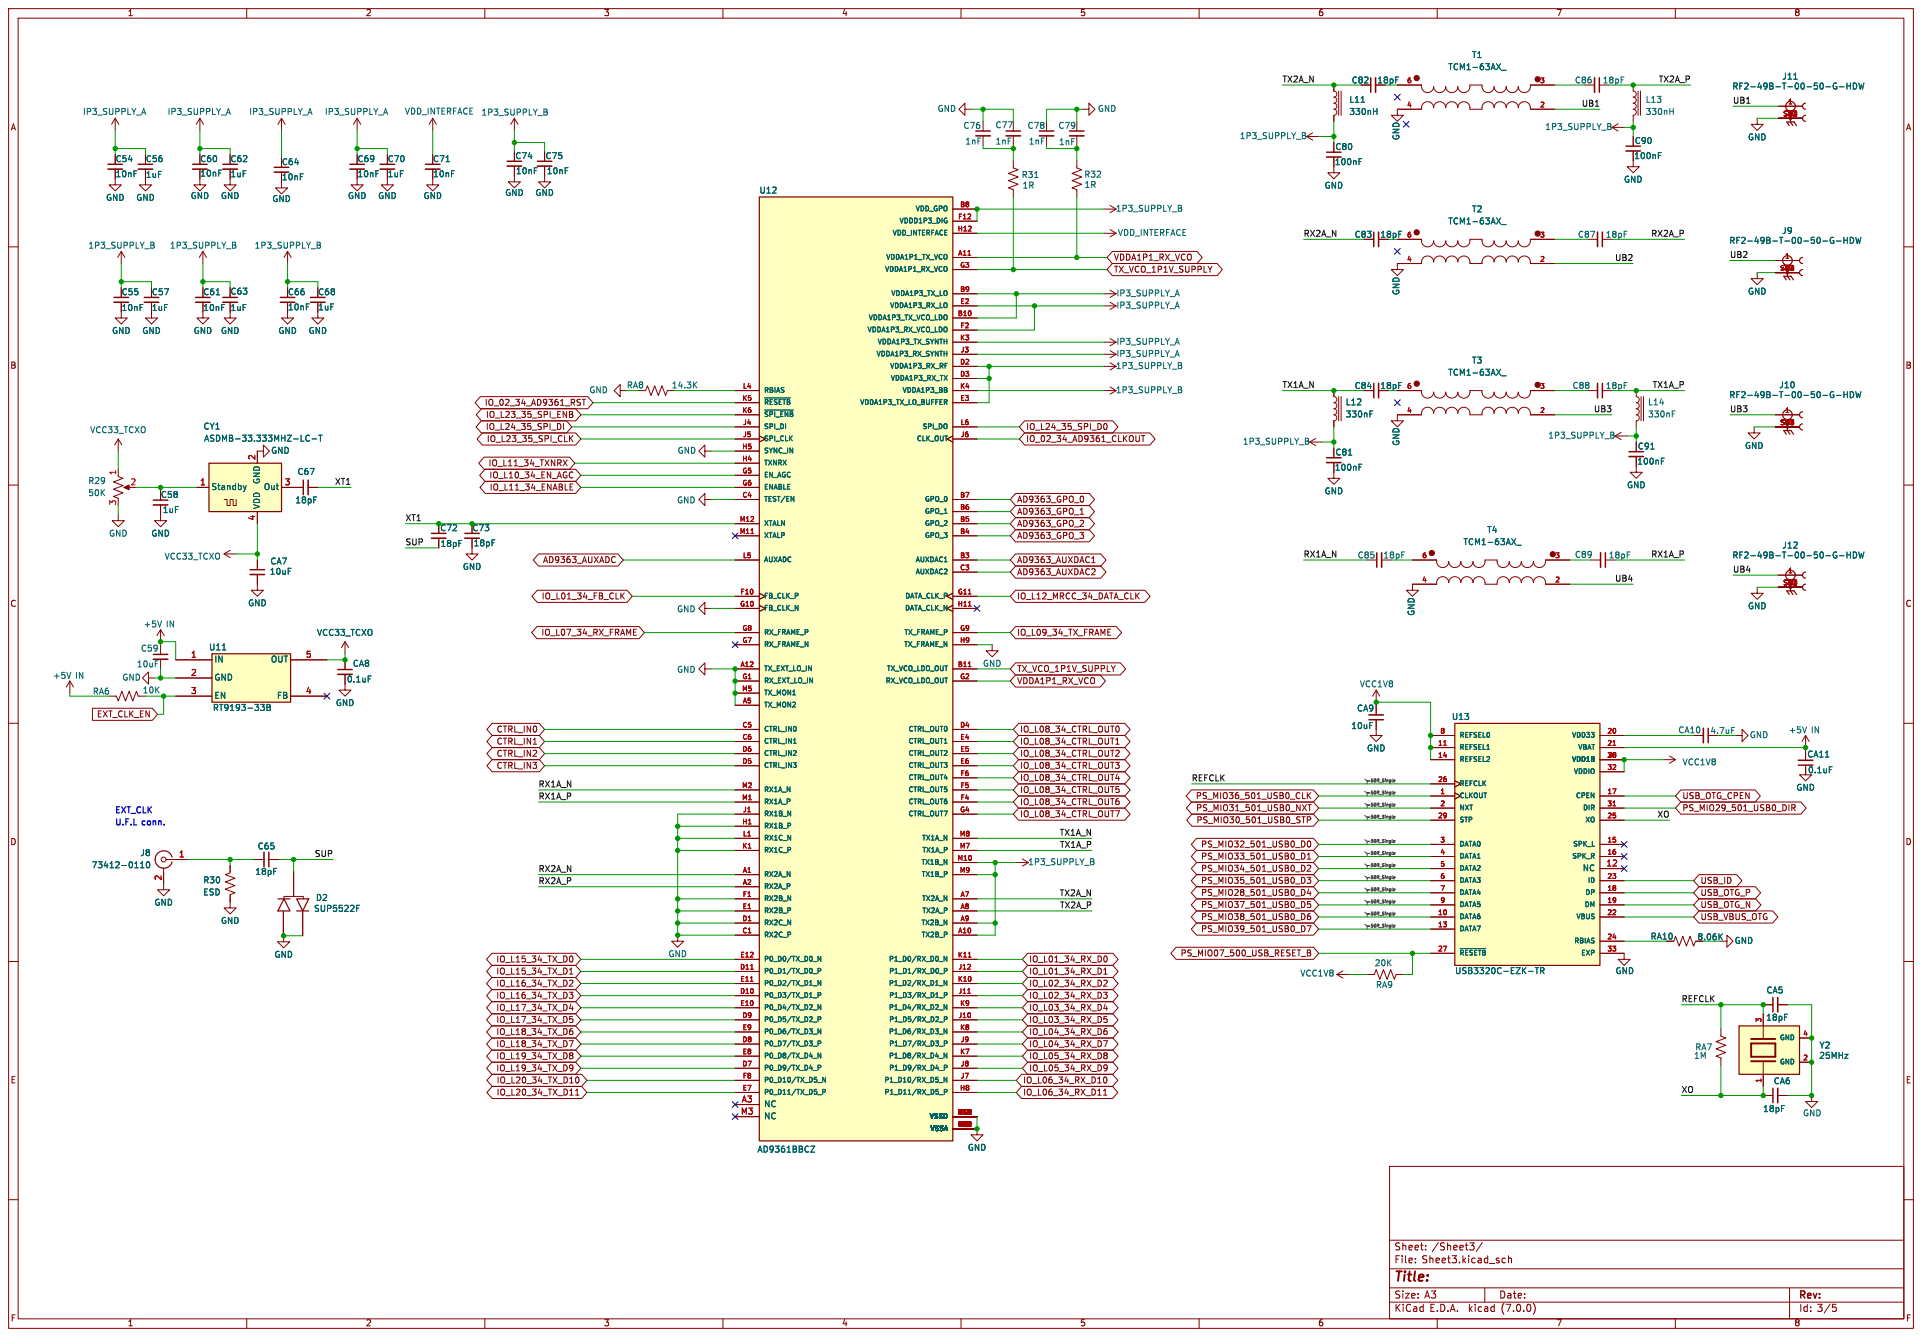
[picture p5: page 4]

Id: 3/5 Title: File: Sheet3.kicad_sch Sheet: /Sheet3/

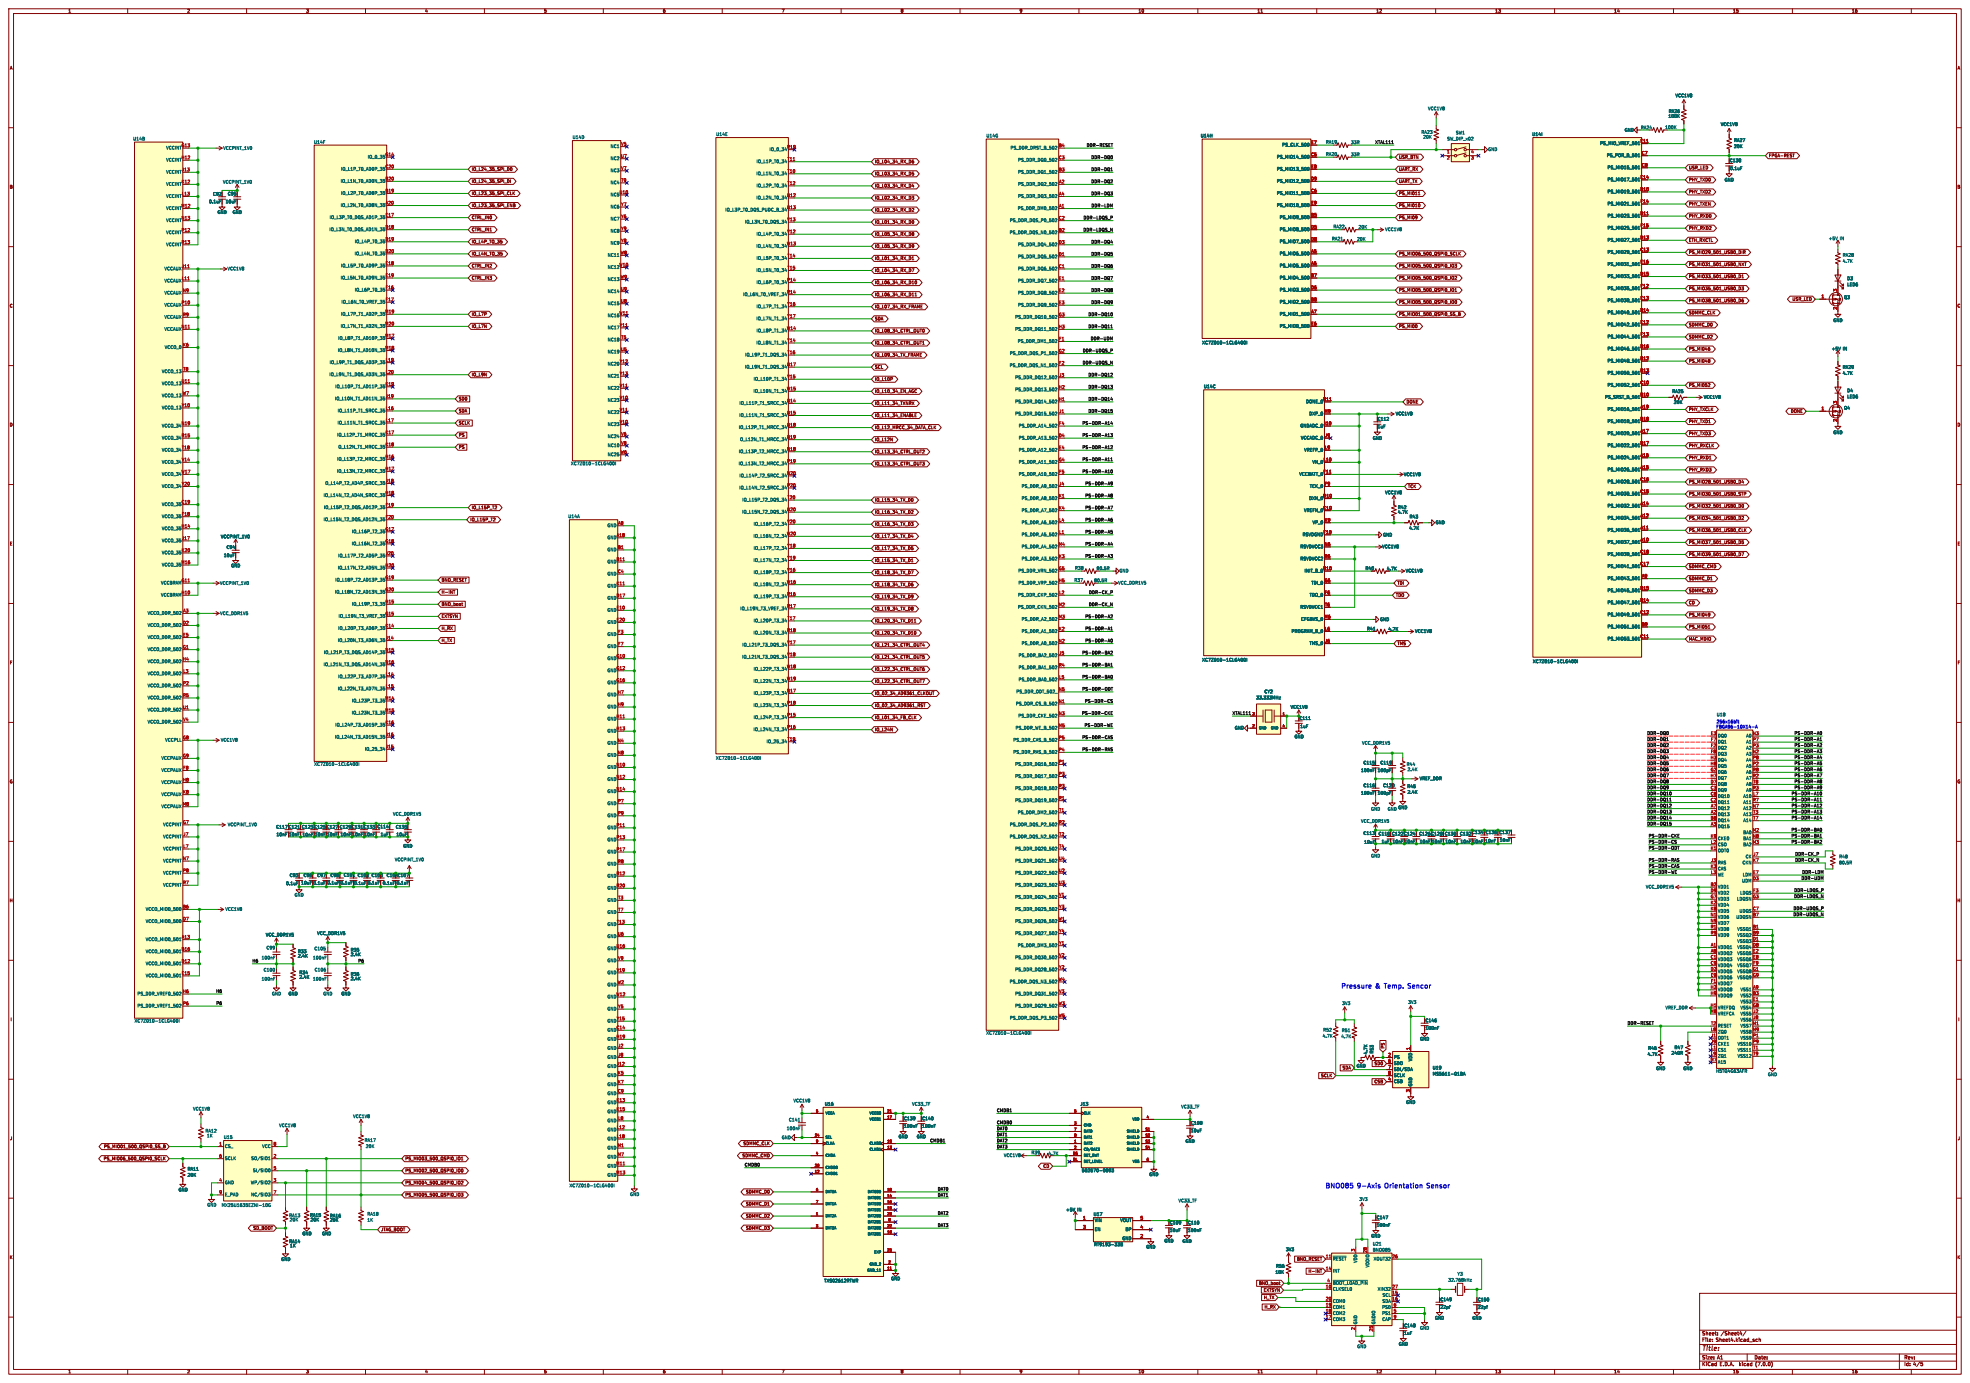
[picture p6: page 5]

PS_DDR_DM0_502 A1 PS_DDR_DQ2_502 A2 PS_DDR_DQ3_502 A4 PS_DDR_DQS_N0_502 B2 PS_DDR_DQ1_502 B3 PS_DDR_DRST_B_502 B4 PS_DDR_DQ6_502 C1 PS_DDR_DQS_P0_502 C2 PS_DDR_DQ0_502 C3 PS_DDR_DQ5_502 D1 PS_DDR_DQ4_502 D3 PS_DDR_A13_502 D4 PS_DDR_DQ7_502 E1 PS_DDR_DQ8_502 E2 PS_DDR_DQ9_502 E3 PS_DDR_A12_502 E4 PS_DDR_DM1_502 F1 PS_DDR_DQS_N1_502 F2 PS_DDR_A14_502 F4 PS_DDR_A10_502 F5 PS_DDR_DQS_P1_502 G2 PS_DDR_DQ10_502 G3 PS_DDR_A11_502 G4 PS_DDR_VRN_502 G5 PS_DDR_DQ14_502 H1 PS_DDR_DQ13_502 H2 PS_DDR_DQ11_502 H3 PS_DDR_VRP_502 H5 PS_DDR_DQ15_502
DDR-DQ0 DDR-DQ1 DDR-DQ2 DDR-UDQS_P DDR-UDQS_N
DDR-LDQS_P DDR-DQ3 DDR-DQ11 DDR-DQ8 DDR-DQ9 DDR-DQ10

DDR-DQ5 DDR-DQ7 DDR-DQ6 DDR-RESET DDR-LDM

DDR-DQ13
DDR-DQ14 PS-DDR-A12 PS-DDR-A14 PS-DDR-A10 PS-DDR-A7
PS-DDR-A13 DDR-DQ15 DDR-CK_N

PS-DDR-A4 PS-DDR-A3 DDR-CK_P

PS-DDR-ODT PS-DDR-RAS

XTAL111 PS-DDR-BA0 PS-DDR-CKE

GNDN10 GNDN12 GNDN14 GND N4 GND N8 GNDP11 GNDP13 GNDP17 GND P7 GND P9 GNDR12 GNDR20 GND R8 GNDT13 GND T3 GND T7 GNDU16 GND U6 GNDV19 GND V9 GNDW12 GND W2 GNDY15 GND Y5

PS-DDR-A3 PS-DDR-A2 PS-DDR-A1

PS-DDR-A4 BNO085 9-Axis Orientation Sensor

PS-DDR-A6
PS-DDR-A9 PS-DDR-A7 PS-DDR-A8
A13 T3 A14 T7 A8 T8 VSS12 T9
PS-DDR-BA0 PS-DDR-BA1 DDR-UDQS_N

GNDJ12 GND J2 GND J8
GNDK13 GNDK15 GND K5 GND K7 GNDL12 GNDL18 GND L8 GND M1 GNDM11 GNDM13 GND M7

Id: 4/5 Title: File: Sheet4.kicad_sch Sheet: /Sheet4/

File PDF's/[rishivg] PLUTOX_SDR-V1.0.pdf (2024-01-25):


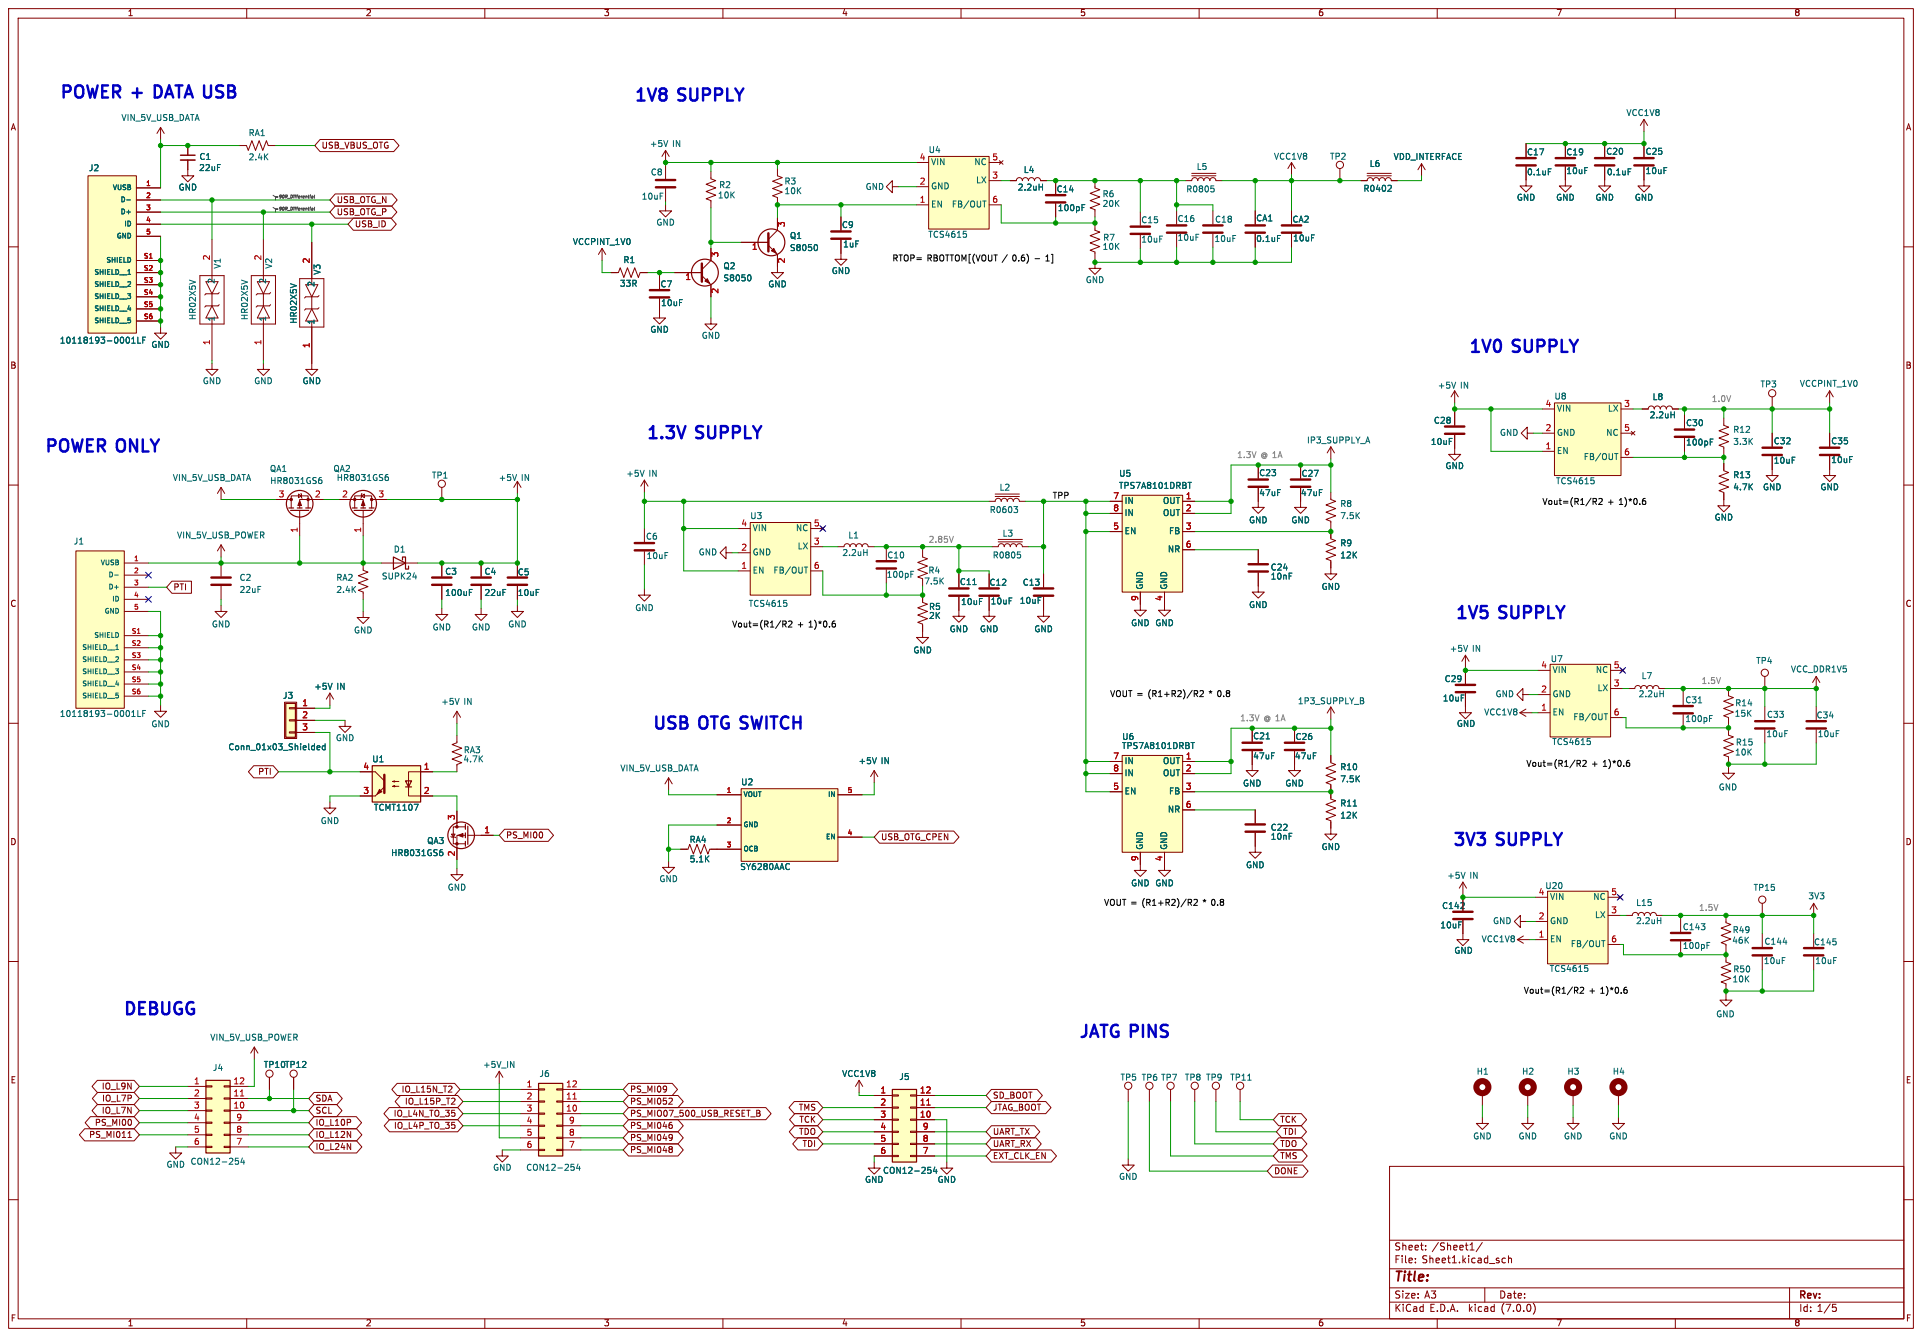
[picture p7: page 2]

U6 TPS7A8101DRBT OUT 1 OUT 2 FB 3 GND

47uF GNDOUT 1 OUT 2 FB 3 GND
47uF GND

Id: 1/5 Title: File: Sheet1.kicad_sch Sheet: /Sheet1/


connect to GND for RTL8211E.

Config for all capability With TX Delay With RX Delay

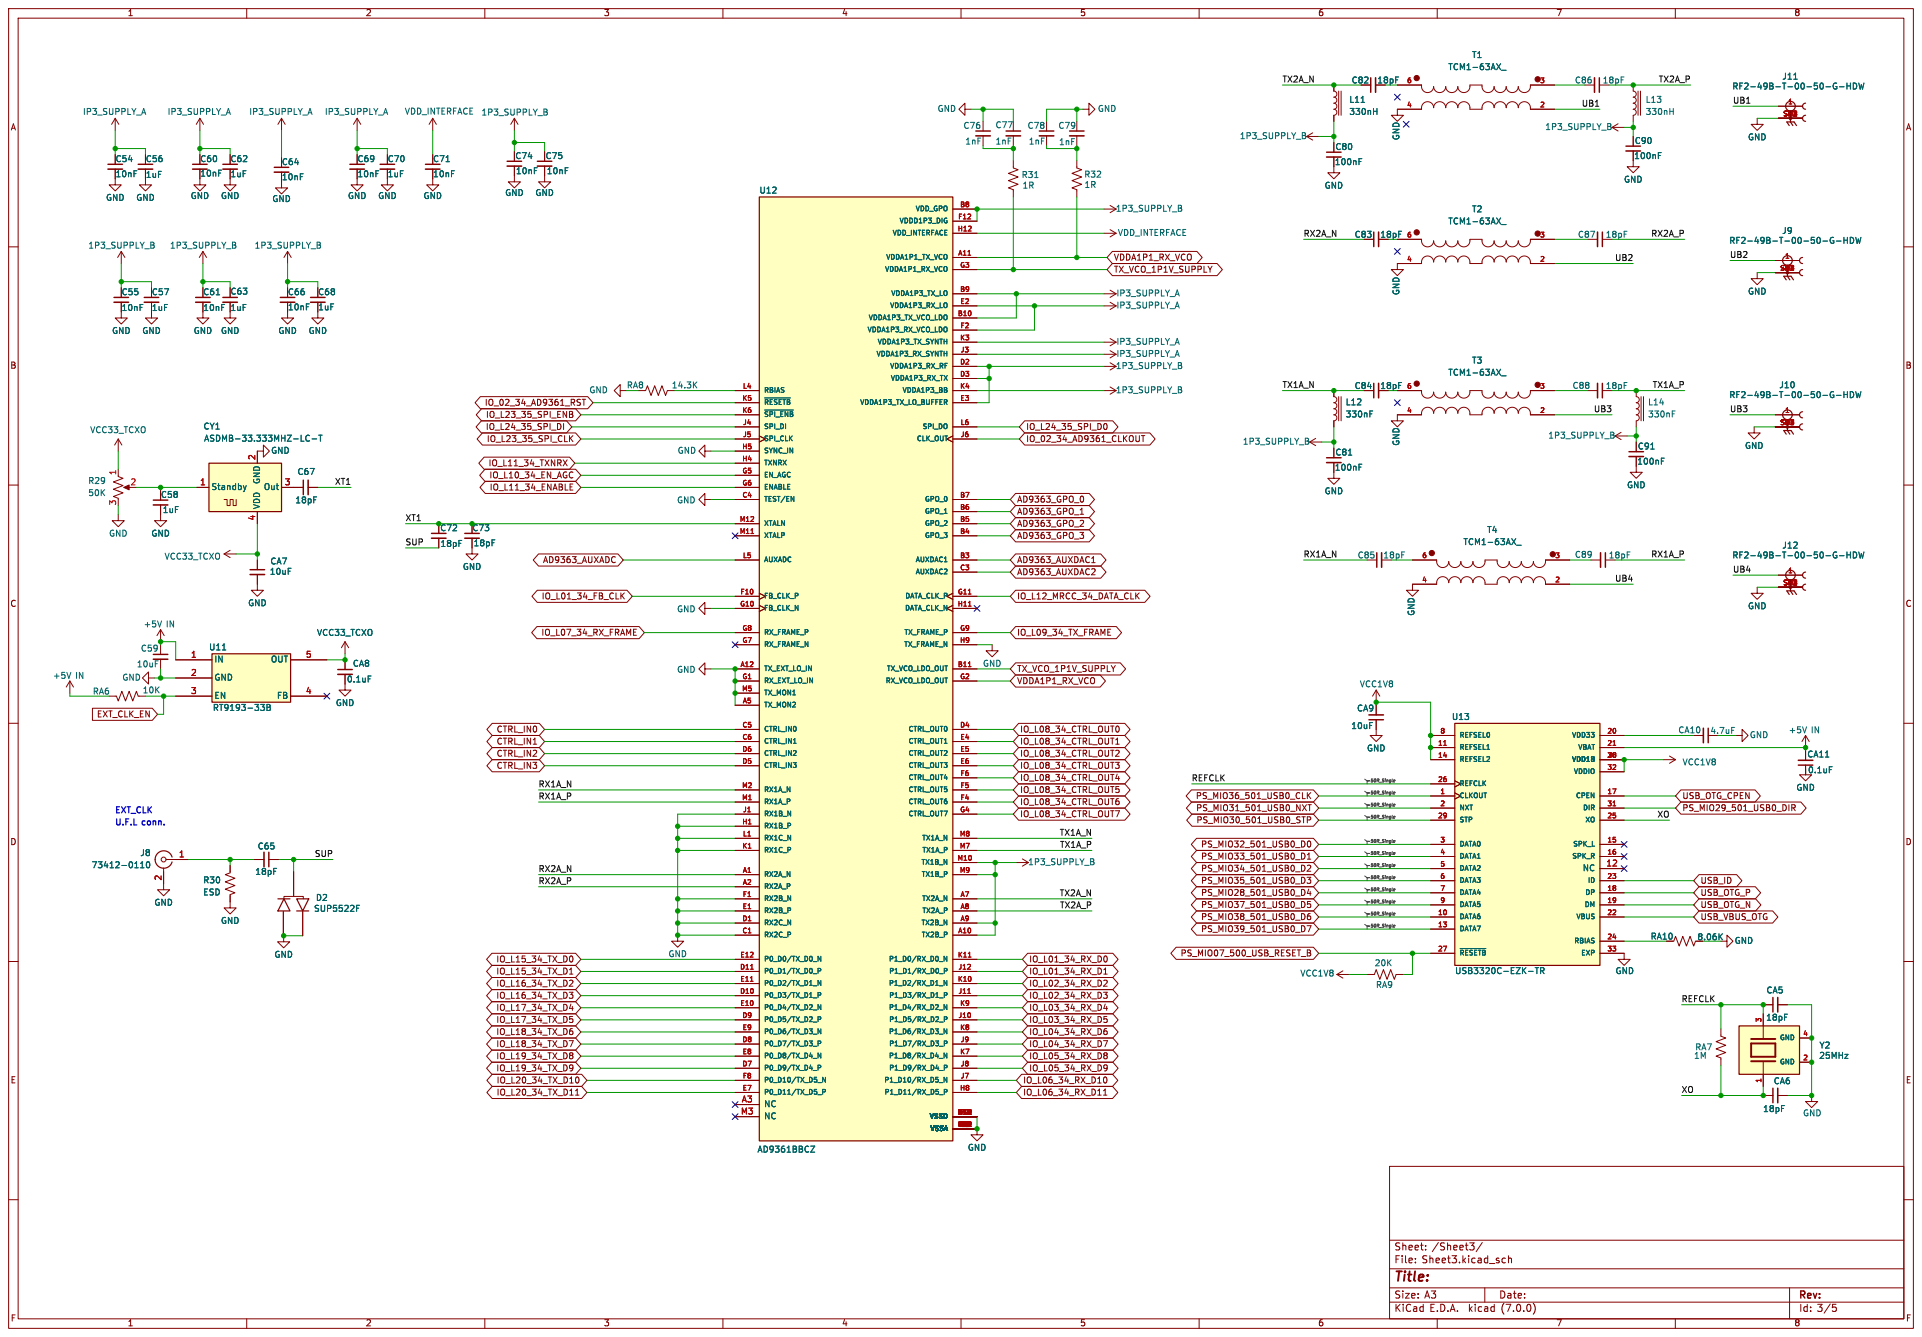
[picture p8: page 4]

Id: 3/5 Title: File: Sheet3.kicad_sch Sheet: /Sheet3/

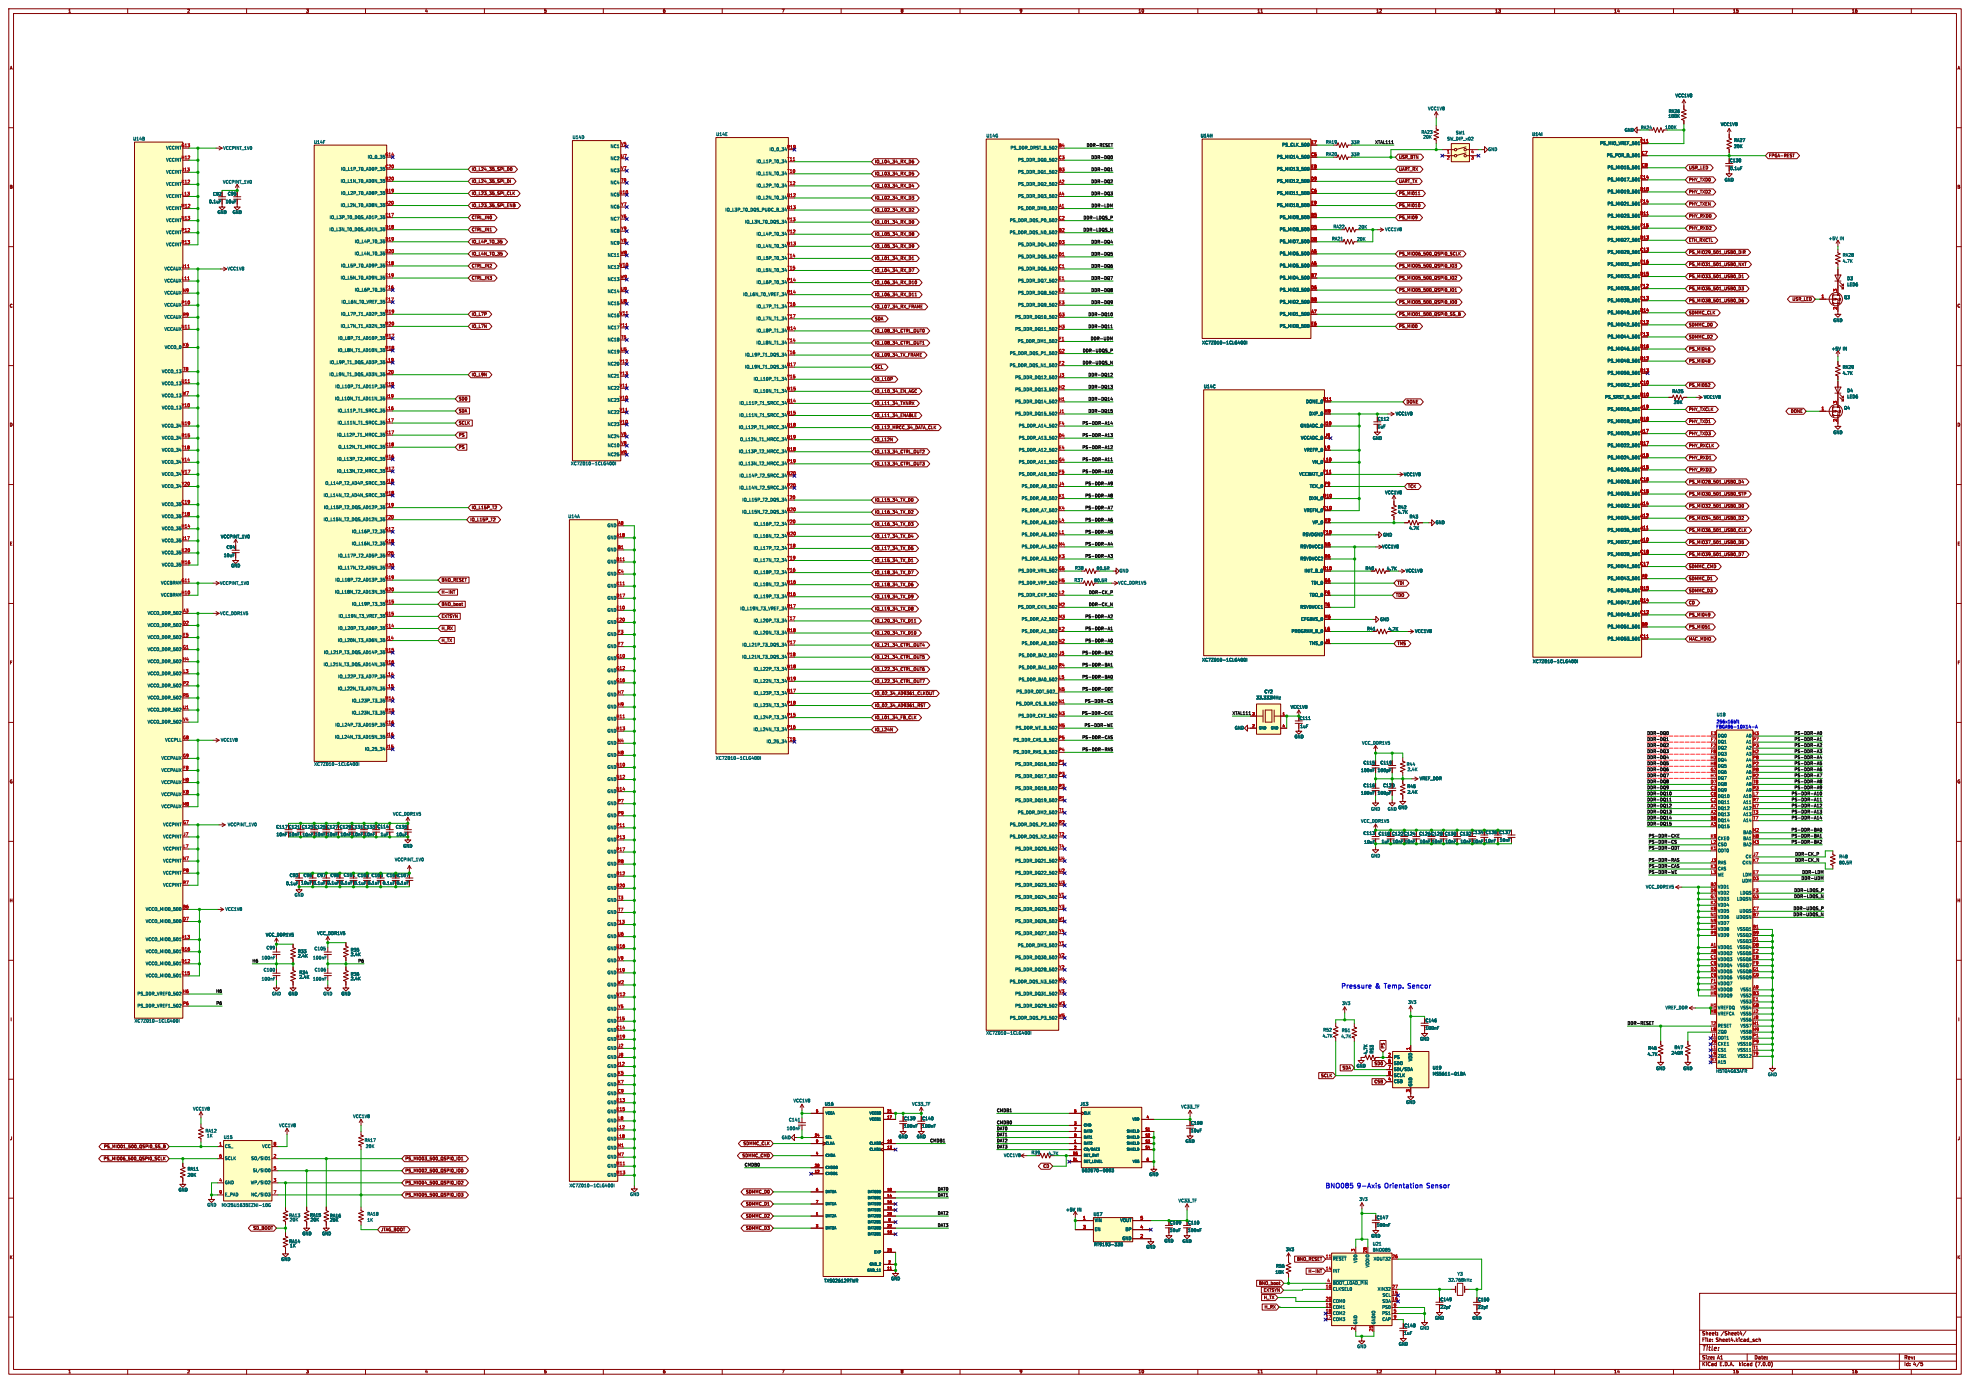
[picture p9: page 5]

DDR-DQ5 DDR-DQ7 DDR-DQ6 DDR-RESET DDR-LDM
DDR-LDQS_P DDR-DQ3 DDR-DQ11 DDR-DQ8 DDR-DQ9 DDR-DQ10

DDR-DQ13
DDR-DQ14 PS-DDR-A12 PS-DDR-A14 PS-DDR-A10 PS-DDR-A7
PS-DDR-A13 DDR-DQ15 DDR-CK_N

PS-DDR-A4 PS-DDR-A3 DDR-CK_P

PS-DDR-ODT PS-DDR-RAS

XTAL111 PS-DDR-BA0 PS-DDR-CKE

GNDN10 GNDN12 GNDN14 GND N4 GND N8 GNDP11 GNDP13 GNDP17 GND P7 GND P9 GNDR12 GNDR20 GND R8 GNDT13 GND T3 GND T7 GNDU16 GND U6 GNDV19 GND V9 GNDW12 GND W2 GNDY15 GND Y5

PS-DDR-A3 PS-DDR-A2 PS-DDR-A1

PS-DDR-A6
PS-DDR-A9 PS-DDR-A7 PS-DDR-A8
A13 T3 A14 T7 A8 T8 VSS12 T9
PS-DDR-BA0 PS-DDR-BA1 DDR-UDQS_N

GNDJ12 GND J2 GND J8
GNDK13 GNDK15 GND K5 GND K7 GNDL12 GNDL18 GND L8 GND M1 GNDM11 GNDM13 GND M7

Id: 4/5 Title: File: Sheet4.kicad_sch Sheet: /Sheet4/

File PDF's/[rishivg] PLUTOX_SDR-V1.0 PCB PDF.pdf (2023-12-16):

1 | 2 | 3 | 4 | 5 | 6

A

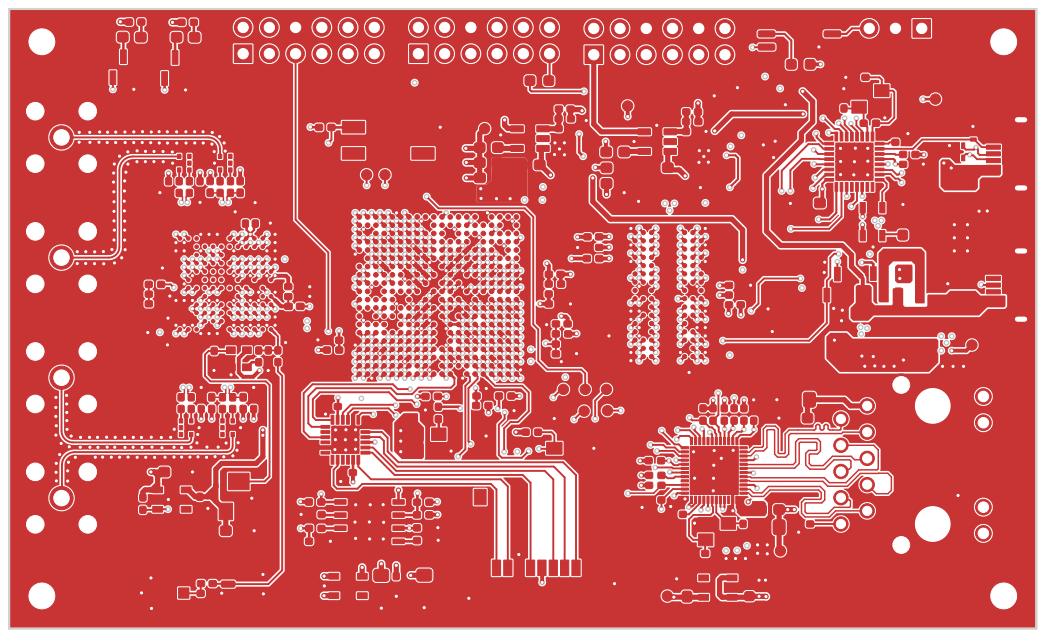
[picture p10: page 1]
D Date: KiCad; kicad; 7.0.7 Size: A4; Rev:; Id: 1/1 Title: File: [rishivg]; PLUTOX_SDR-V1.0.kicad_pcb Sheet:

A

A

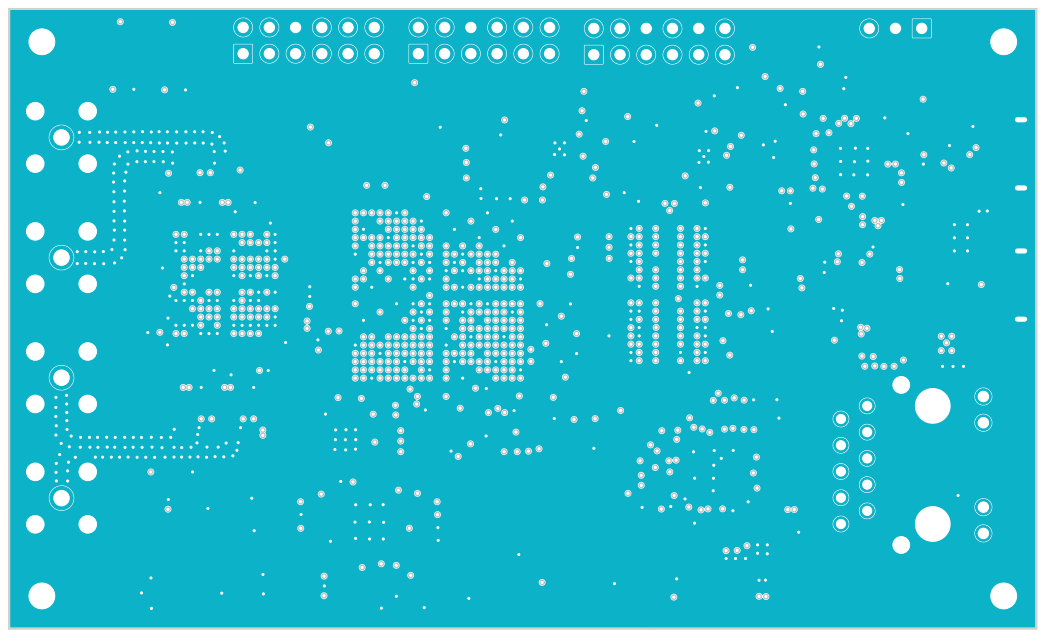
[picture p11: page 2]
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

A

A

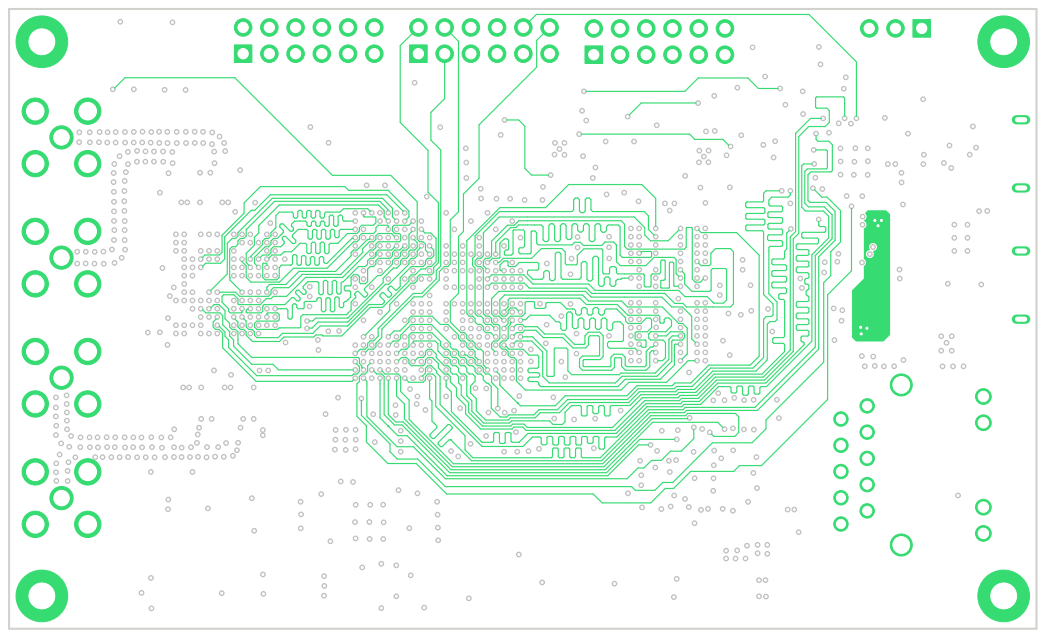
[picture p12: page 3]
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

A

A

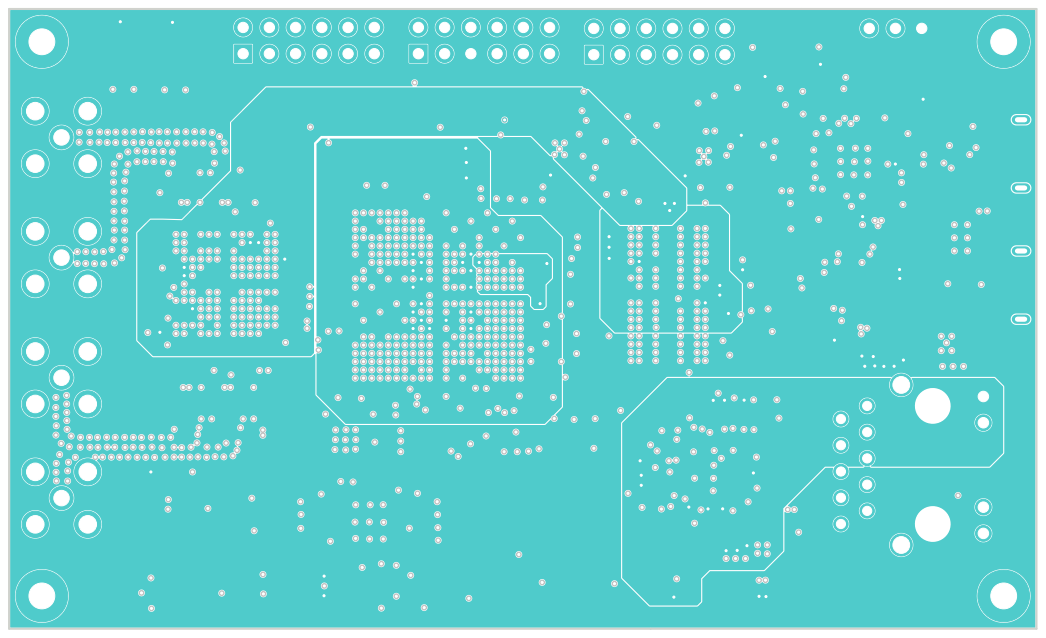
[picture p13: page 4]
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

A

A

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

A

A

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

A

A

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

A

A

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

A

A


A

A


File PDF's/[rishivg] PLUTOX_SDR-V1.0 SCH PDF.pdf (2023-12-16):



TPP POWER + DATA USB

U5 TPS7A8101DRBT OUT 1 OUT 2 FB 3 GND

47uF GND GND GND
7.5K GND GNDOUT 1 OUT 2 FB 3 GND
1P3_SUPPLY_B R9

9 GND GND GND GND

10K U6 TPS7A8101DRBT OUT 1 OUT 2 FB 3 GND

Id: 1/5 Title: File: Sheet1.kicad_sch Sheet: /Sheet1/


Config for all capability


Id: 3/5 Title: File: Sheet3.kicad_sch Sheet: /Sheet3/


DDR-RESET
DDR-DQ0 DDR-DQ1 DDR-DQ5 DDR-DQ8 DDR-DQ7 DDR-DQ9 DDR-DQ10 DDR-DQ6 DDR-DQ4 DDR-LDM

PS-DDR-A9 PS-DDR-A8 PS-DDR-A11 PS-DDR-A10 DDR-DQ11 PS-DDR-A13 PS-DDR-A12 PS-DDR-A14 PS-DDR-A4 PS-DDR-A7 DDR-DQ13 DDR-DQ15 DDR-DQ14 DDR-UDQS_P DDR-UDQS_N
J3 PS_DDR_A9_502
J1 PS_DDR_DQ12_502

PS-DDR-BA0 PS-DDR-BA1 PS-DDR-CS

GNDN10 GNDN12 GNDN14 GND N4 GND N8 GNDP11 GNDP13 GNDP17 GND P7 GND P9 GNDR12 GNDR20 GND R8 GNDT13 GND T3 GND T7 GNDU16 GND U6 GNDV19 GND V9 GNDW12 GND W2 GNDY15 GND Y5

Id: 4/5 Title: File: Sheet4.kicad_sch Sheet: /Sheet4/

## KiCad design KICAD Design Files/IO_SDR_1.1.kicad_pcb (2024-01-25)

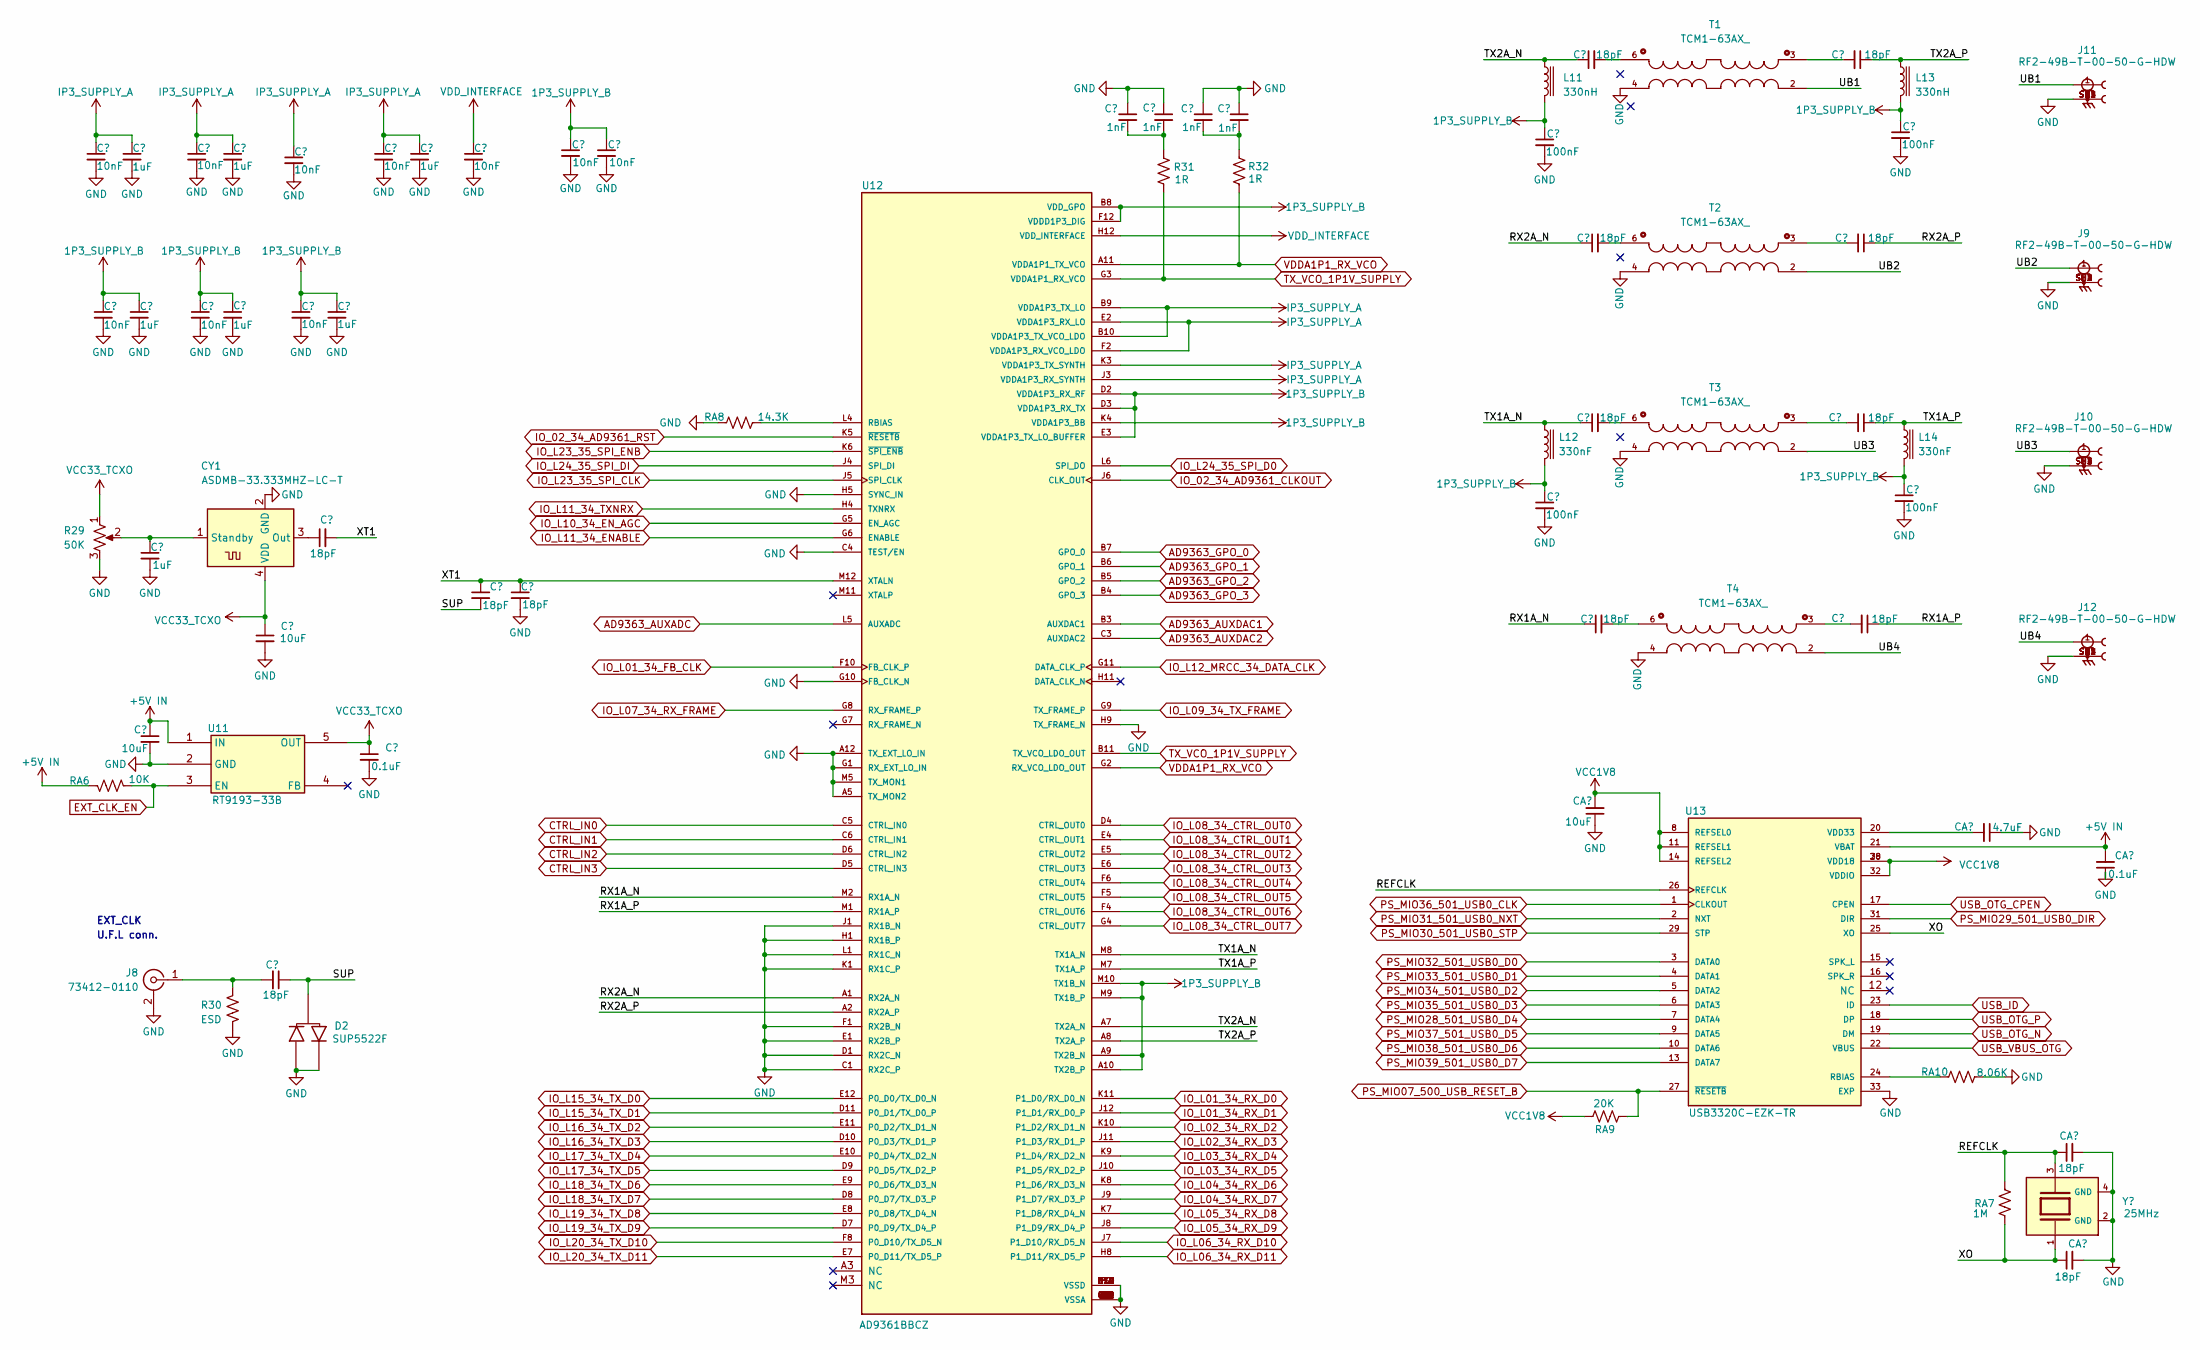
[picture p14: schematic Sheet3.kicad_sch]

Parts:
C54, C55, C60, C61, C64, C66, C69, C71, C74, C75: 10nF; C_0402_1005Metric_Pad0.74x0.62mm_HandSolder
C56, C57, C58, C62, C63, C68, C70: 1uF; C_0402_1005Metric_Pad0.74x0.62mm_HandSolder
C59: 10uF; C_0603_1608Metric_Pad1.08x0.95mm_HandSolder
C65, C67, C72, C73, C82, C83, C84, C85, C86, C87, C88, C89: 18pF; C_0402_1005Metric_Pad0.74x0.62mm_HandSolder
C76, C77, C78, C79: 1nF; C_0402_1005Metric_Pad0.74x0.62mm_HandSolder
C80, C81, C90, C91: 100nF; C_0402_1005Metric_Pad0.74x0.62mm_HandSolder
CA5, CA6: 18pF; C_0402_1005Metric_Pad0.74x0.62mm_HandSolder
CA7, CA9: 10uF; C_0603_1608Metric_Pad1.08x0.95mm_HandSolder
CA8, CA11: 0.1uF; C_0402_1005Metric_Pad0.74x0.62mm_HandSolder
CA10: 4.7uF; C_0603_1608Metric_Pad1.08x0.95mm_HandSolder
CY1: ASDMB-33.333MHZ-LC-T; XTAL_ASDMB-33.333MHZ-LC-T
D2: SUP5522F; SOT-23-3
J8: 73412-0110; U.FL_Molex_MCRF_73412-0110_Vertical
J9, J10, J11, J12: RF2-49B-T-00-50-G-HDW; ADAMTECH_RF2-49B-T-00-50-G-HDW; PARTREV 7/20/16
L11, L13: 330nH; L_0402_1005Metric_Pad0.77x0.64mm_HandSolder
L12, L14: 330nF; L_0402_1005Metric_Pad0.77x0.64mm_HandSolder
R29: 50K; Potentiometer_Bourns_3214W_Vertical
R30: ESD; R_0402_1005Metric_Pad0.72x0.64mm_HandSolder
R31, R32: 1R; R_0402_1005Metric_Pad0.72x0.64mm_HandSolder
RA6: 10K; R_0402_1005Metric_Pad0.72x0.64mm_HandSolder
RA7: 1M; R_0402_1005Metric_Pad0.72x0.64mm_HandSolder
RA8: 14.3K; R_0402_1005Metric_Pad0.72x0.64mm_HandSolder
RA9: 20K; R_0402_1005Metric_Pad0.72x0.64mm_HandSolder
RA10: 8.06K; R_0402_1005Metric_Pad0.72x0.64mm_HandSolder
T1, T2, T3, T4: TCM1-63AX_; XFMR_TCM1-63AX_
U11: RT9193-33B
U12: AD9361BBCZ
U13: USB3320C-EZK-TR
Y2: 25MHz; XTAL_TSX-3225_25.0000MF10P-C0; PARTREV N/A

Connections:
+1V2: C55.1, C57.1, C61.1, C63.1, C66.1, C68.1, C74.1, C75.1, C80.1, C81.1, C90.1, C91.1, L11.2, L12.2, L13.2, L14.2, U12.A9 (TX2B_N), U12.A10 (TX2B_P), U12.B8 (VDD_GPO), U12.D2 (VDDA1P3_RX_RF), U12.D3 (VDDA1P3_RX_TX), U12.E3 (VDDA1P3_TX_LO_BUFFER), U12.F12 (VDDD1P3_DIG), U12.K4 (VDDA1P3_BB), U12.M9 (TX1B_P), U12.M10 (TX1B_N); also elsewhere on the board
+1V8: CA9.2, RA9.2, U13.8 (REFSEL0), U13.11 (REFSEL1), U13.14 (REFSEL2), U13.28 (VDD18), U13.30 (VDD18), U13.32 (VDDIO); also elsewhere on the board
+3.3V: CA7.1, CA8.1, CY1.4 (VDD), R29.1, U11.5 (OUT)
+12L: C54.1, C56.1, C60.1, C62.1, C64.1, C69.1, C70.1, U12.B9 (VDDA1P3_TX_LO), U12.B10 (VDDA1P3_TX_VCO_LDO), U12.E2 (VDDA1P3_RX_LO), U12.F2 (VDDA1P3_RX_VCO_LDO), U12.J3 (VDDA1P3_RX_SYNTH), U12.K3 (VDDA1P3_TX_SYNTH); also elsewhere on the board
+VSW: C71.1, U12.H12 (VDD_INTERFACE); also elsewhere on the board
/Sheet3/REFCLK: CA5.1, RA7.1, U13.26 (REFCLK), Y2.3
/Sheet3/RX1A_N: C85.1, U12.M2 (RX1A_N)
/Sheet3/RX1A_P: C89.1, U12.M1 (RX1A_P)
/Sheet3/RX2A_N: C83.1, U12.A1 (RX2A_N)
/Sheet3/RX2A_P: C87.1, U12.A2 (RX2A_P)
/Sheet3/SUP: C65.1, C72.2, D2.3 (D)
/Sheet3/TX1A_N: C84.1, L12.1, U12.M8 (TX1A_N)
/Sheet3/TX1A_P: C88.1, L14.1, U12.M7 (TX1A_P)
/Sheet3/TX2A_N: C82.1, L11.1, U12.A7 (TX2A_N)
/Sheet3/TX2A_P: C86.1, L13.1, U12.A8 (TX2A_P)
/Sheet3/UB1: J11.1, T1.2
/Sheet3/UB2: J9.1, T2.2
/Sheet3/UB3: J10.1, T3.2
/Sheet3/UB4: J12.1, T4.2
/Sheet3/XO: CA6.1, RA7.2, U13.25 (XO), Y2.1
/Sheet3/XT1: C67.2, C72.1, C73.1, U12.M12 (XTALN)
AD9363_AUXADC: U12.L5 (AUXADC)
AD9363_AUXDAC1: U12.B3 (AUXDAC1)
AD9363_AUXDAC2: U12.C3 (AUXDAC2)
AD9363_GPO_0: U12.B7 (GPO_0)
AD9363_GPO_1: U12.B6 (GPO_1)
AD9363_GPO_2: U12.B5 (GPO_2)
AD9363_GPO_3: U12.B4 (GPO_3)
CTRL_IN0: U12.C5 (CTRL_IN0); also elsewhere on the board
CTRL_IN1: U12.C6 (CTRL_IN1); also elsewhere on the board
CTRL_IN2: U12.D6 (CTRL_IN2); also elsewhere on the board
CTRL_IN3: U12.D5 (CTRL_IN3); also elsewhere on the board
EXT_CLK_EN: RA6.2, U11.3 (EN); also elsewhere on the board
GND: C54.2, C55.2, C56.2, C57.2, C58.2, C59.2, C60.2, C61.2, C62.2, C63.2, C64.2, C66.2, C68.2, C69.2, C70.2, C71.2, C73.2, C74.2, C75.2, C76.1, C77.1, C78.1, C79.1, C80.2, C81.2, C90.2, C91.2, CA5.2, CA6.2, CA7.2, CA8.2, CA9.1, CA10.1, CA11.1, CY1.2 (GND), D2.1 (G), D2.2 (S), J8.2 (Ext), J9.SH1, J9.SH2, J9.SH3, J9.SH4, J10.SH1, J10.SH2, J10.SH3, J10.SH4, J11.SH1, J11.SH2, J11.SH3, J11.SH4, J12.SH1, J12.SH2, J12.SH3, J12.SH4, R29.3, R30.2, RA8.2, RA10.2, T1.4, T2.4, T3.4, T4.4, U11.2 (GND), U12.A4 (VSSA), U12.A5 (TX_MON2), U12.A6 (VSSA), U12.A12 (TX_EXT_LO_IN), U12.B1 (VSSA), U12.B2 (VSSA), U12.B12 (VSSA), U12.C1 (RX2C_P), U12.C2 (VSSA), U12.C4 (TEST/EN), U12.C7 (VSSA), U12.C8 (VSSA), U12.C9 (VSSA), U12.C10 (VSSA), U12.C11 (VSSA), U12.C12 (VSSA), U12.D1 (RX2C_N), U12.D12 (VSSD), U12.E1 (RX2B_P), U12.F1 (RX2B_N), U12.F3 (VSSA), U12.F7 (VSSD), U12.F9 (VSSD), U12.F11 (VSSD), U12.G1 (RX_EXT_LO_IN), U12.G10 (FB_CLK_N), U12.G12 (VSSD), U12.H1 (RX1B_P), U12.H2 (VSSA), U12.H3 (VSSA), U12.H5 (SYNC_IN), U12.H6 (VSSA), U12.H7 (VSSD), U12.H9 (TX_FRAME_N), U12.H10 (VSSD), U12.J1 (RX1B_N), U12.J2 (VSSA), U12.K1 (RX1C_P), U12.K2 (VSSA), U12.K12 (VSSD), U12.L1 (RX1C_N), U12.L2 (VSSA), U12.L3 (VSSA), U12.L7 (VSSA), U12.L8 (VSSA), U12.L9 (VSSA), U12.L10 (VSSA), U12.L11 (VSSA), U12.L12 (VSSA), U12.M4 (VSSA), U12.M5 (TX_MON1), U12.M6 (VSSA), U13.33 (EXP), Y2.2 (GND), Y2.4 (GND); also elsewhere on the board
IO_02_34_AD9361_CLKOUT: U12.J6 (CLK_OUT); also elsewhere on the board
IO_02_34_AD9361_RST: U12.K5 (~RESETB); also elsewhere on the board
IO_L01_34_FB_CLK: U12.F10 (FB_CLK_P); also elsewhere on the board
IO_L01_34_RX_D0: U12.K11 (P1_D0/RX_D0_N); also elsewhere on the board
IO_L01_34_RX_D1: U12.J12 (P1_D1/RX_D0_P); also elsewhere on the board
IO_L02_34_RX_D2: U12.K10 (P1_D2/RX_D1_N); also elsewhere on the board
IO_L02_34_RX_D3: U12.J11 (P1_D3/RX_D1_P); also elsewhere on the board
IO_L03_34_RX_D4: U12.K9 (P1_D4/RX_D2_N); also elsewhere on the board
IO_L03_34_RX_D5: U12.J10 (P1_D5/RX_D2_P); also elsewhere on the board
IO_L04_34_RX_D6: U12.K8 (P1_D6/RX_D3_N); also elsewhere on the board
IO_L04_34_RX_D7: U12.J9 (P1_D7/RX_D3_P); also elsewhere on the board
IO_L05_34_RX_D8: U12.K7 (P1_D8/RX_D4_N); also elsewhere on the board
IO_L05_34_RX_D9: U12.J8 (P1_D9/RX_D4_P); also elsewhere on the board
IO_L06_34_RX_D10: U12.J7 (P1_D10/RX_D5_N); also elsewhere on the board
IO_L06_34_RX_D11: U12.H8 (P1_D11/RX_D5_P); also elsewhere on the board
IO_L07_34_RX_FRAME: U12.G8 (RX_FRAME_P); also elsewhere on the board
IO_L08_34_CTRL_OUT0: U12.D4 (CTRL_OUT0); also elsewhere on the board
IO_L08_34_CTRL_OUT1: U12.E4 (CTRL_OUT1); also elsewhere on the board
IO_L08_34_CTRL_OUT2: U12.E5 (CTRL_OUT2)
IO_L08_34_CTRL_OUT3: U12.E6 (CTRL_OUT3)
IO_L08_34_CTRL_OUT4: U12.F6 (CTRL_OUT4)
IO_L08_34_CTRL_OUT5: U12.F5 (CTRL_OUT5)
IO_L08_34_CTRL_OUT6: U12.F4 (CTRL_OUT6)
IO_L08_34_CTRL_OUT7: U12.G4 (CTRL_OUT7)
IO_L09_34_TX_FRAME: U12.G9 (TX_FRAME_P); also elsewhere on the board
IO_L10_34_EN_AGC: U12.G5 (EN_AGC); also elsewhere on the board
IO_L11_34_ENABLE: U12.G6 (ENABLE); also elsewhere on the board
IO_L11_34_TXNRX: U12.H4 (TXNRX); also elsewhere on the board
IO_L12_MRCC_34_DATA_CLK: U12.G11 (DATA_CLK_P); also elsewhere on the board
IO_L15_34_TX_D0: U12.E12 (P0_D0/TX_D0_N); also elsewhere on the board
IO_L15_34_TX_D1: U12.D11 (P0_D1/TX_D0_P); also elsewhere on the board
IO_L16_34_TX_D2: U12.E11 (P0_D2/TX_D1_N); also elsewhere on the board
IO_L16_34_TX_D3: U12.D10 (P0_D3/TX_D1_P); also elsewhere on the board
IO_L17_34_TX_D4: U12.E10 (P0_D4/TX_D2_N); also elsewhere on the board
IO_L17_34_TX_D5: U12.D9 (P0_D5/TX_D2_P); also elsewhere on the board
IO_L18_34_TX_D6: U12.E9 (P0_D6/TX_D3_N); also elsewhere on the board
IO_L18_34_TX_D7: U12.D8 (P0_D7/TX_D3_P); also elsewhere on the board
IO_L19_34_TX_D8: U12.E8 (P0_D8/TX_D4_N); also elsewhere on the board
IO_L19_34_TX_D9: U12.D7 (P0_D9/TX_D4_P); also elsewhere on the board
IO_L20_34_TX_D10: U12.F8 (P0_D10/TX_D5_N); also elsewhere on the board
IO_L20_34_TX_D11: U12.E7 (P0_D11/TX_D5_P); also elsewhere on the board
IO_L23_35_SPI_CLK: U12.J5 (SPI_CLK); also elsewhere on the board
IO_L23_35_SPI_ENB: U12.K6 (~SPI_ENB); also elsewhere on the board
IO_L24_35_SPI_D0: U12.L6 (SPI_DO); also elsewhere on the board
IO_L24_35_SPI_DI: U12.J4 (SPI_DI); also elsewhere on the board
unnamed: C76.2, C77.2, R31.1
unnamed: C78.2, C79.2, R32.1
unnamed: C82.2, T1.6
unnamed: C83.2, T2.6
unnamed: C84.2, T3.6
unnamed: C85.2, T4.6
unnamed: C86.2, T1.3
unnamed: C87.2, T2.3
unnamed: C88.2, T3.3
unnamed: C89.2, T4.3
unnamed: C67.1, CY1.3 (Out)
unnamed: C58.1, CY1.1 (Standby), R29.2
unnamed: C65.2, J8.1 (In), R30.1
unnamed: RA8.1, U12.L4 (RBIAS)
unnamed: RA10.1, U13.24 (RBIAS)
unnamed: CA10.2, U13.20 (VDD33)
PS_MIO07_500_USB_RESET_B: RA9.1, U13.27 (~RESETB); also elsewhere on the board
PS_MIO28_501_USB0_D4: U13.7 (DATA4); also elsewhere on the board
PS_MIO29_501_USB0_DIR: U13.31 (DIR); also elsewhere on the board
PS_MIO30_501_USB0_STP: U13.29 (STP); also elsewhere on the board
PS_MIO31_501_USB0_NXT: U13.2 (NXT); also elsewhere on the board
PS_MIO32_501_USB0_D0: U13.3 (DATA0); also elsewhere on the board
PS_MIO33_501_USB0_D1: U13.4 (DATA1); also elsewhere on the board
PS_MIO34_501_USB0_D2: U13.5 (DATA2); also elsewhere on the board
PS_MIO35_501_USB0_D3: U13.6 (DATA3); also elsewhere on the board
PS_MIO36_501_USB0_CLK: U13.1 (CLKOUT); also elsewhere on the board
PS_MIO37_501_USB0_D5: U13.9 (DATA5); also elsewhere on the board
PS_MIO38_501_USB0_D6: U13.10 (DATA6); also elsewhere on the board
PS_MIO39_501_USB0_D7: U13.13 (DATA7); also elsewhere on the board
TX_VCO_1P1V_SUPPLY: R31.2, U12.B11 (TX_VCO_LDO_OUT), U12.G3 (VDDA1P1_RX_VCO)
USB_ID: U13.23 (ID); also elsewhere on the board
USB_OTG_CPEN: U13.17 (CPEN); also elsewhere on the board
USB_OTG_N: U13.19 (DM); also elsewhere on the board
USB_OTG_P: U13.18 (DP); also elsewhere on the board
USB_VBUS_OTG: U13.22 (VBUS); also elsewhere on the board
VDDA1P1_RX_VCO: R32.2, U12.A11 (VDDA1P1_TX_VCO), U12.G2 (RX_VCO_LDO_OUT)

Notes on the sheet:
EXT_CLK
U.F.L conn.

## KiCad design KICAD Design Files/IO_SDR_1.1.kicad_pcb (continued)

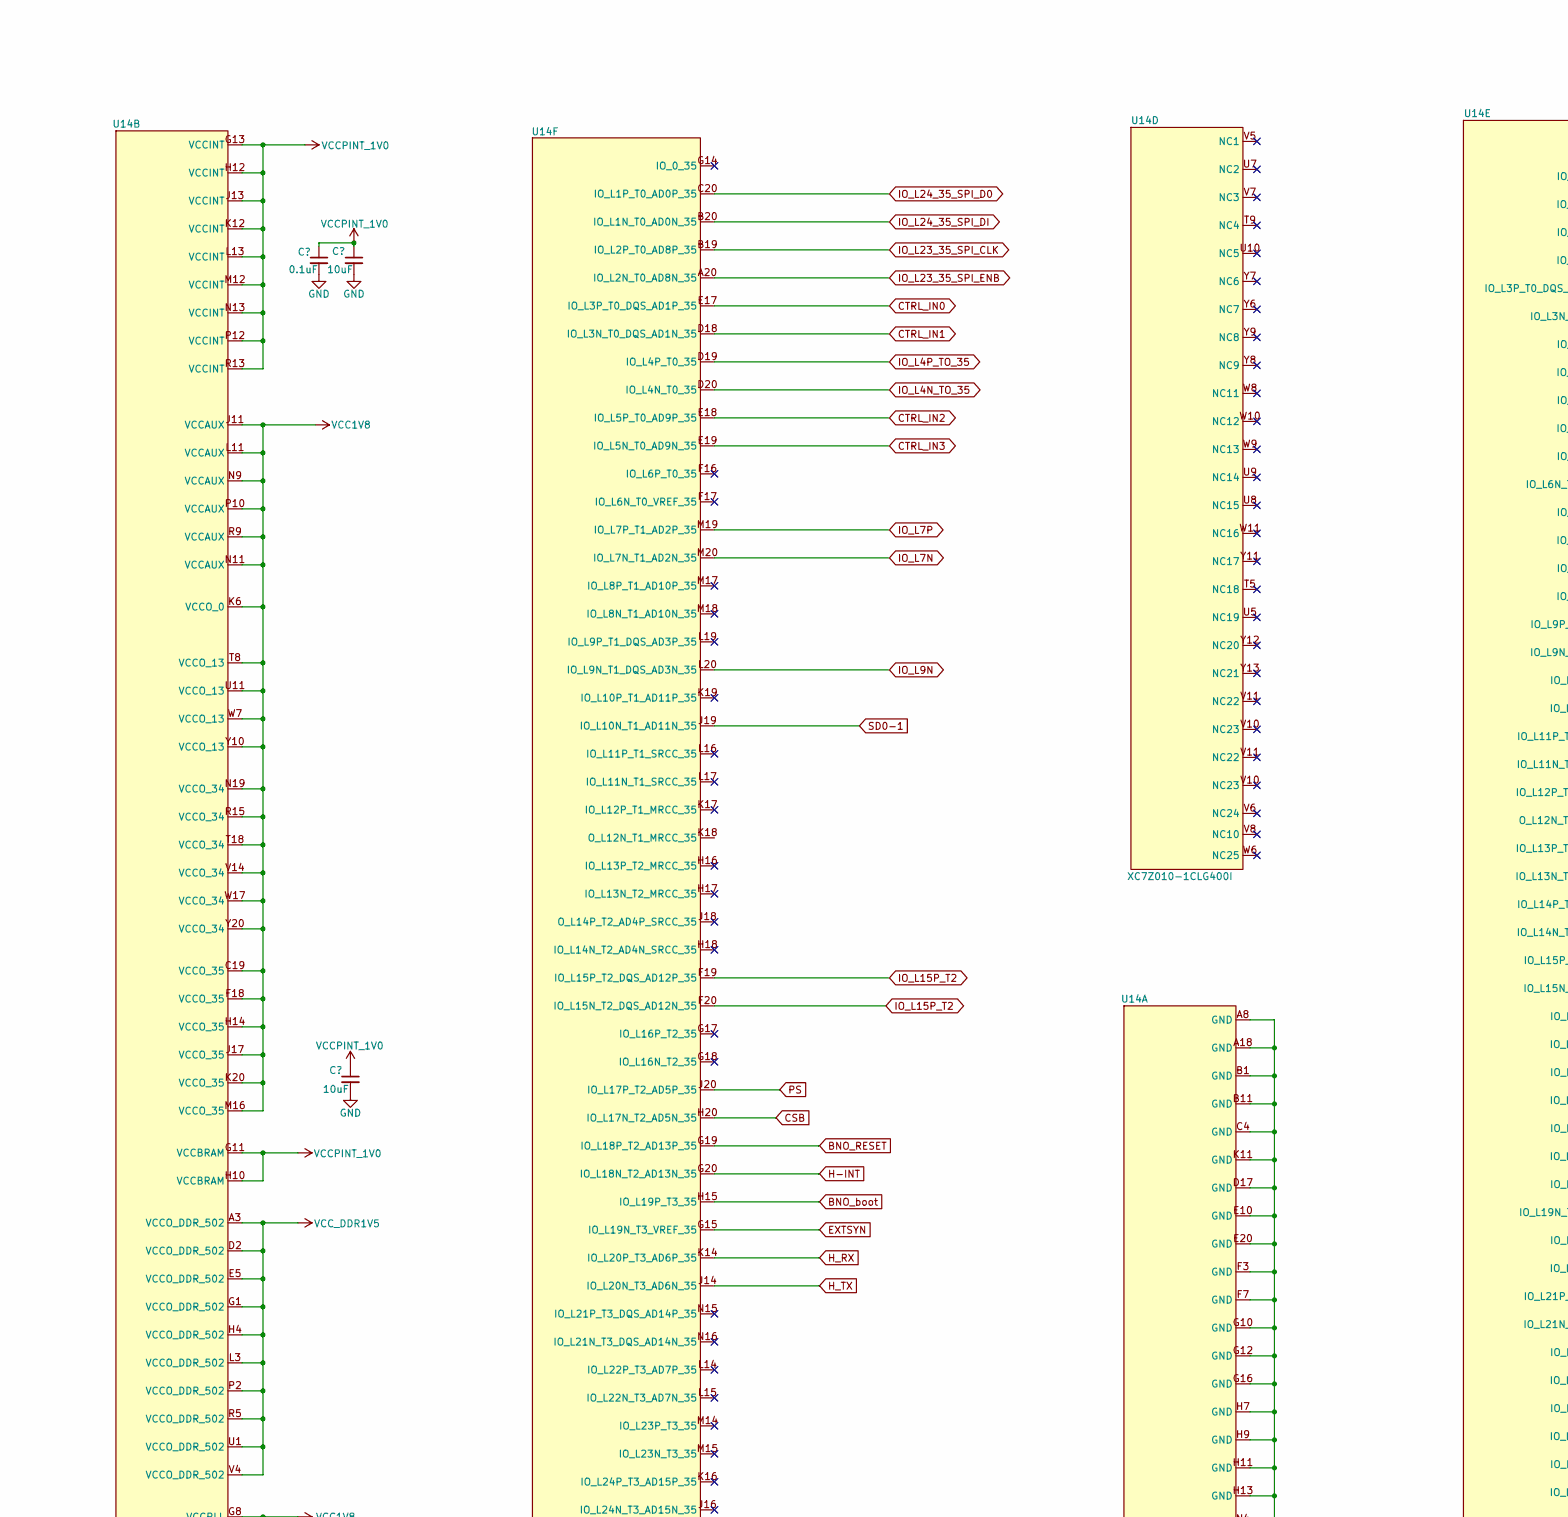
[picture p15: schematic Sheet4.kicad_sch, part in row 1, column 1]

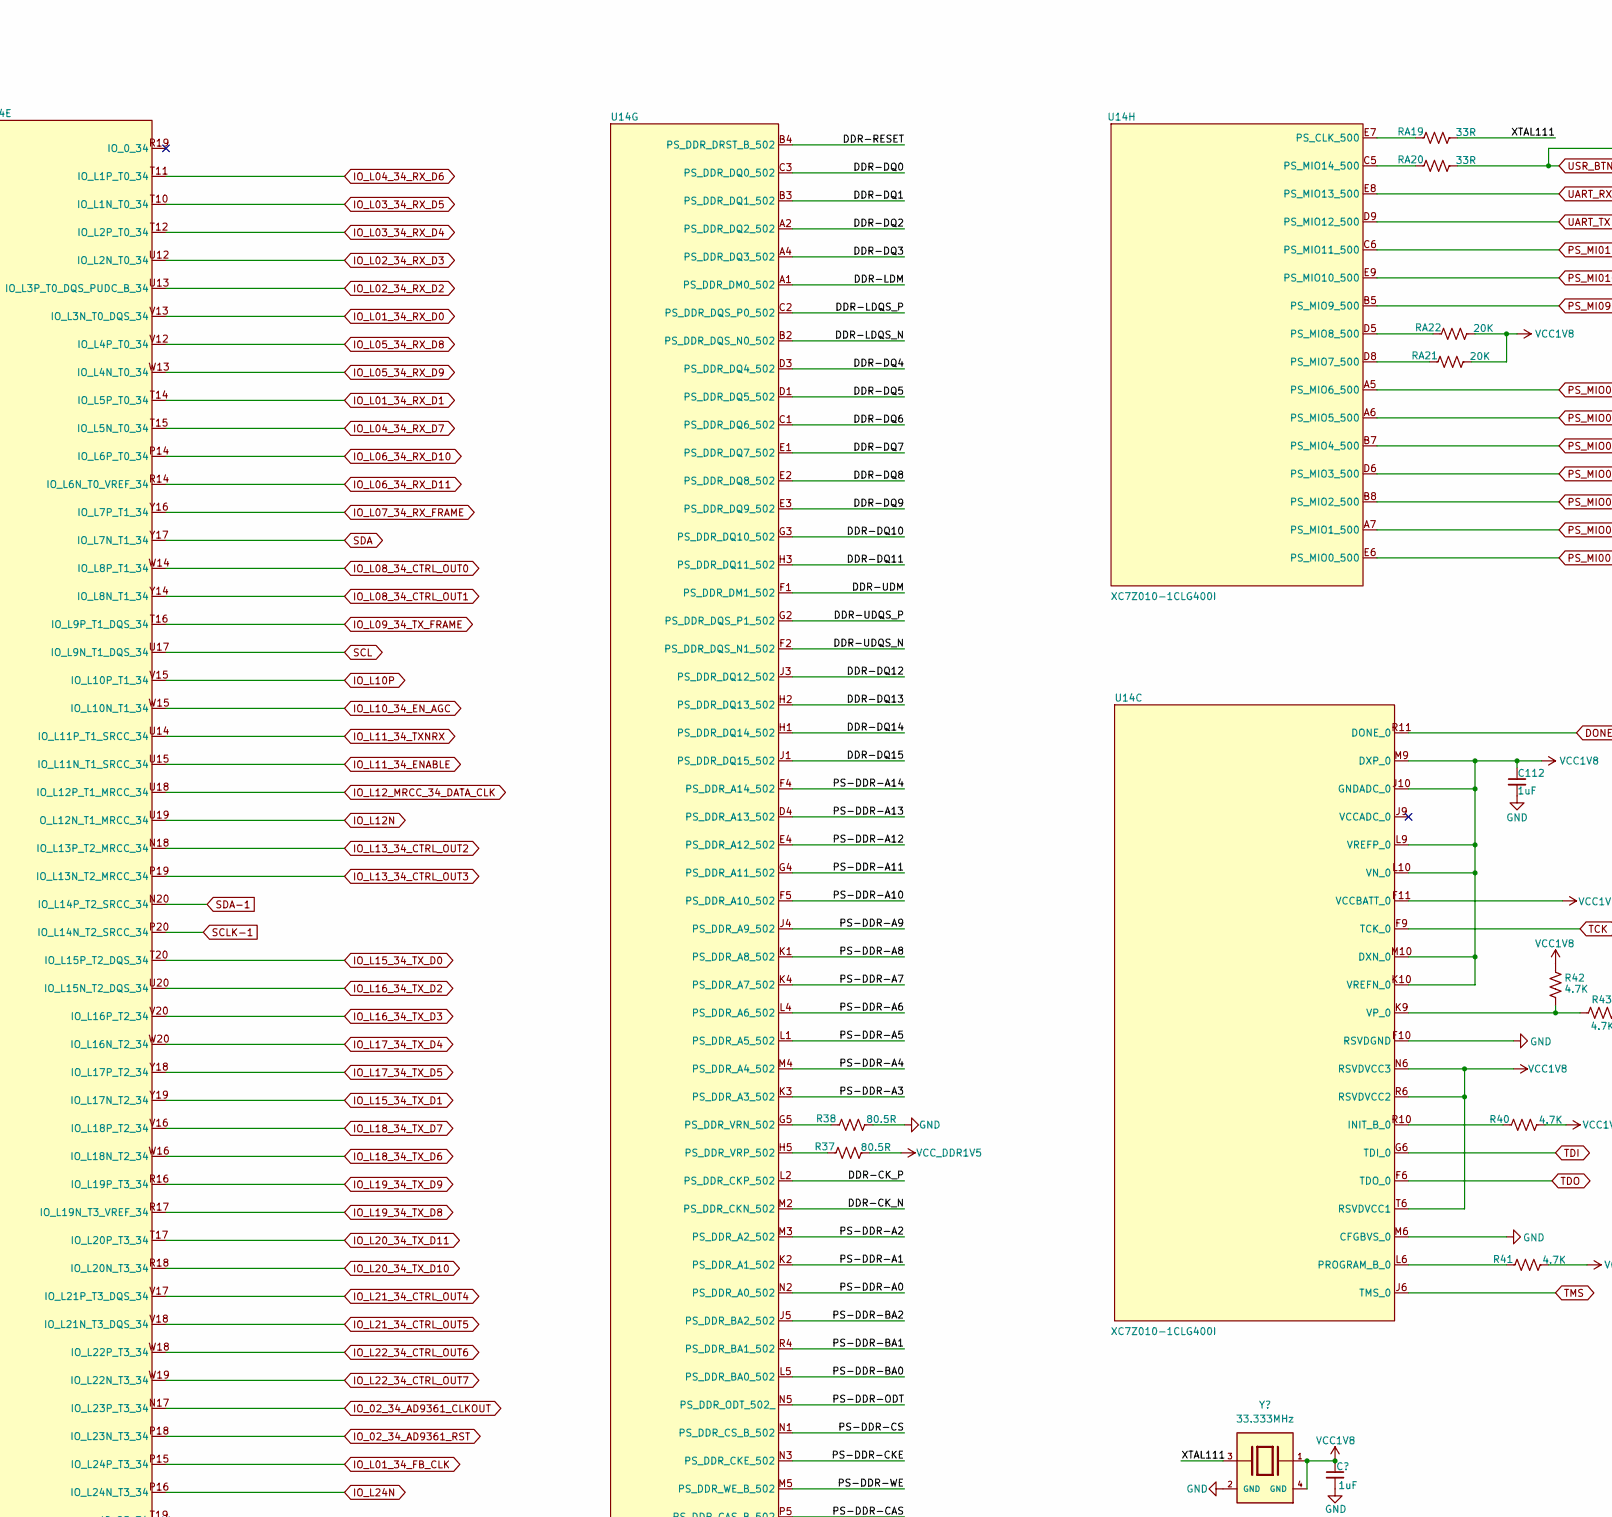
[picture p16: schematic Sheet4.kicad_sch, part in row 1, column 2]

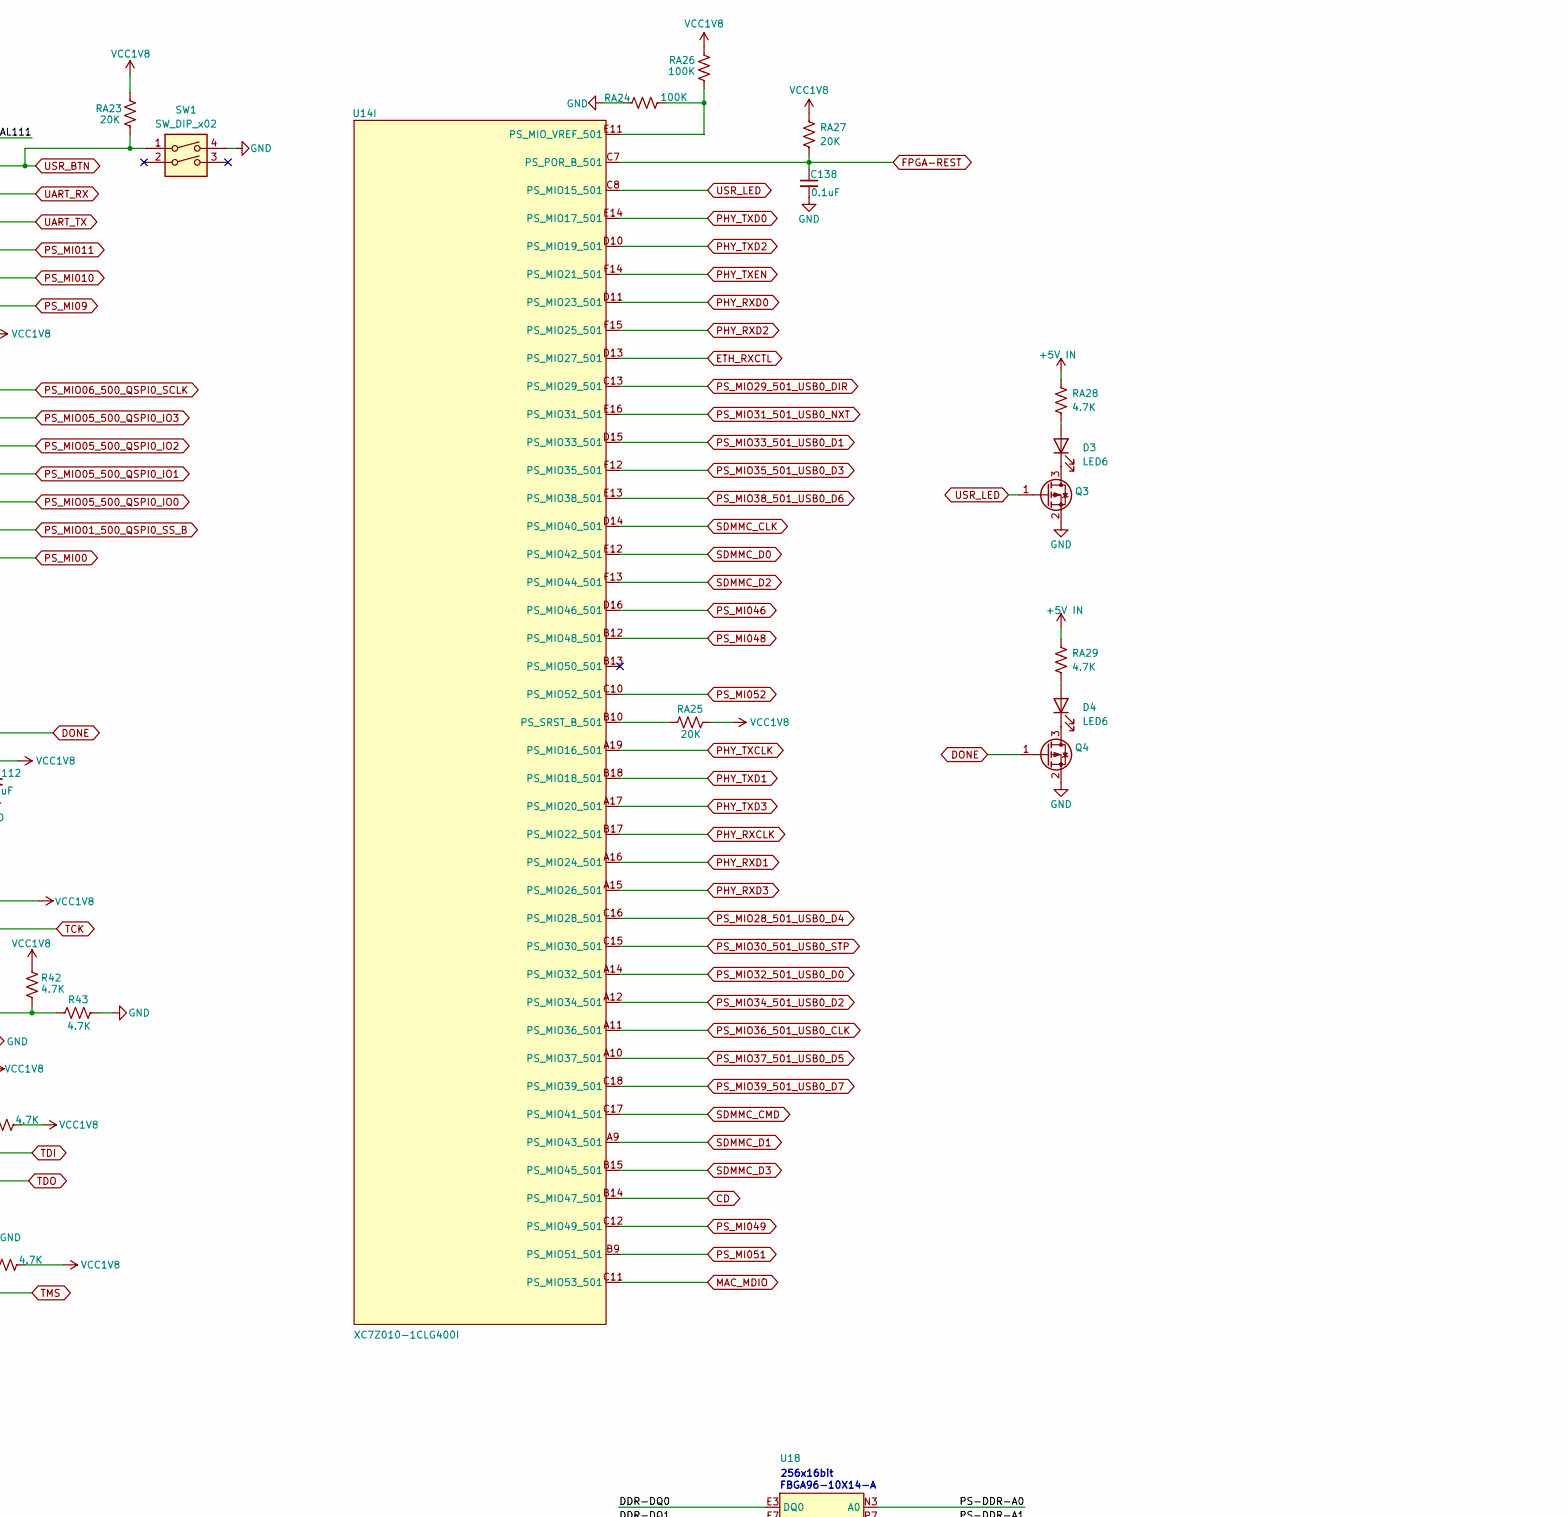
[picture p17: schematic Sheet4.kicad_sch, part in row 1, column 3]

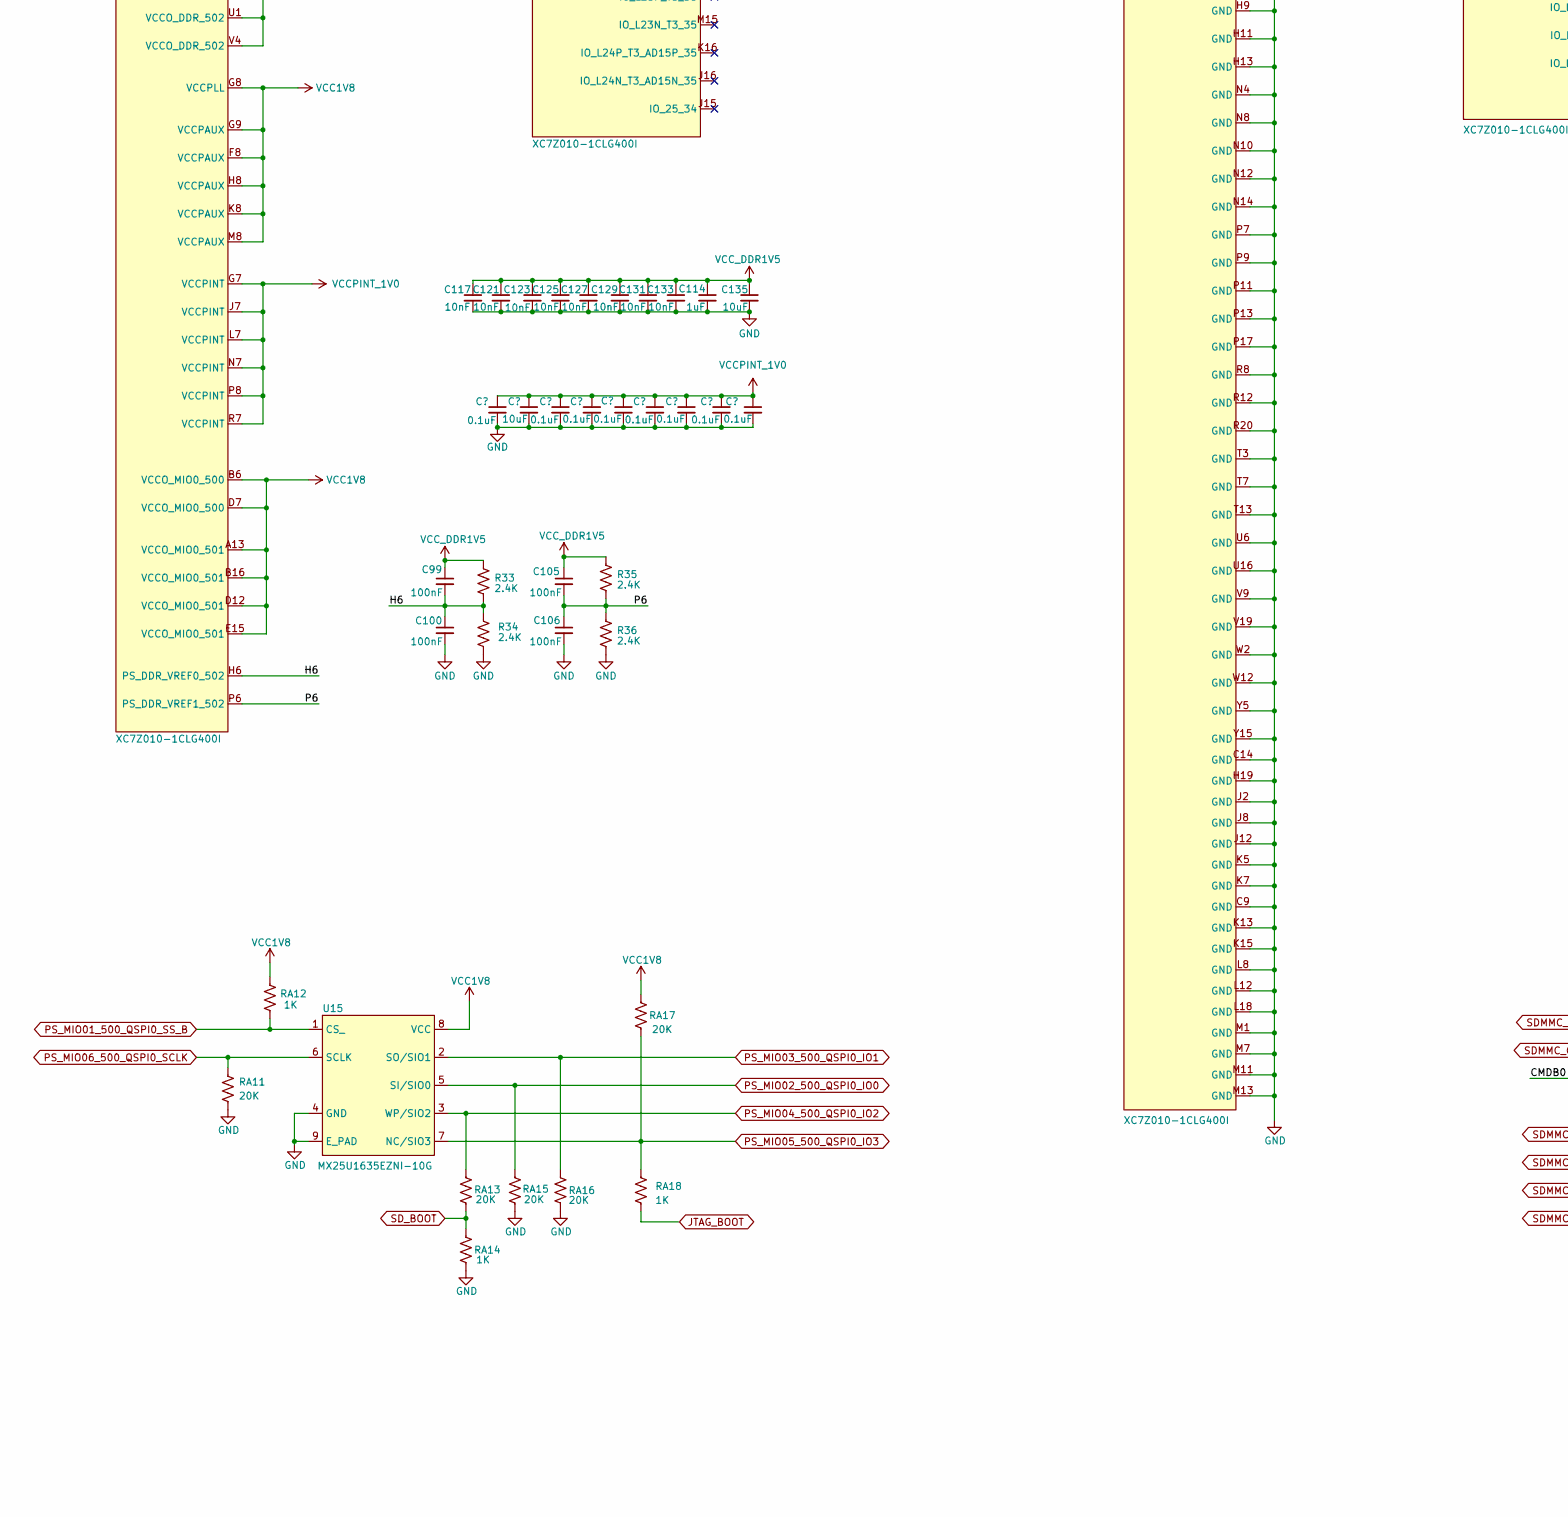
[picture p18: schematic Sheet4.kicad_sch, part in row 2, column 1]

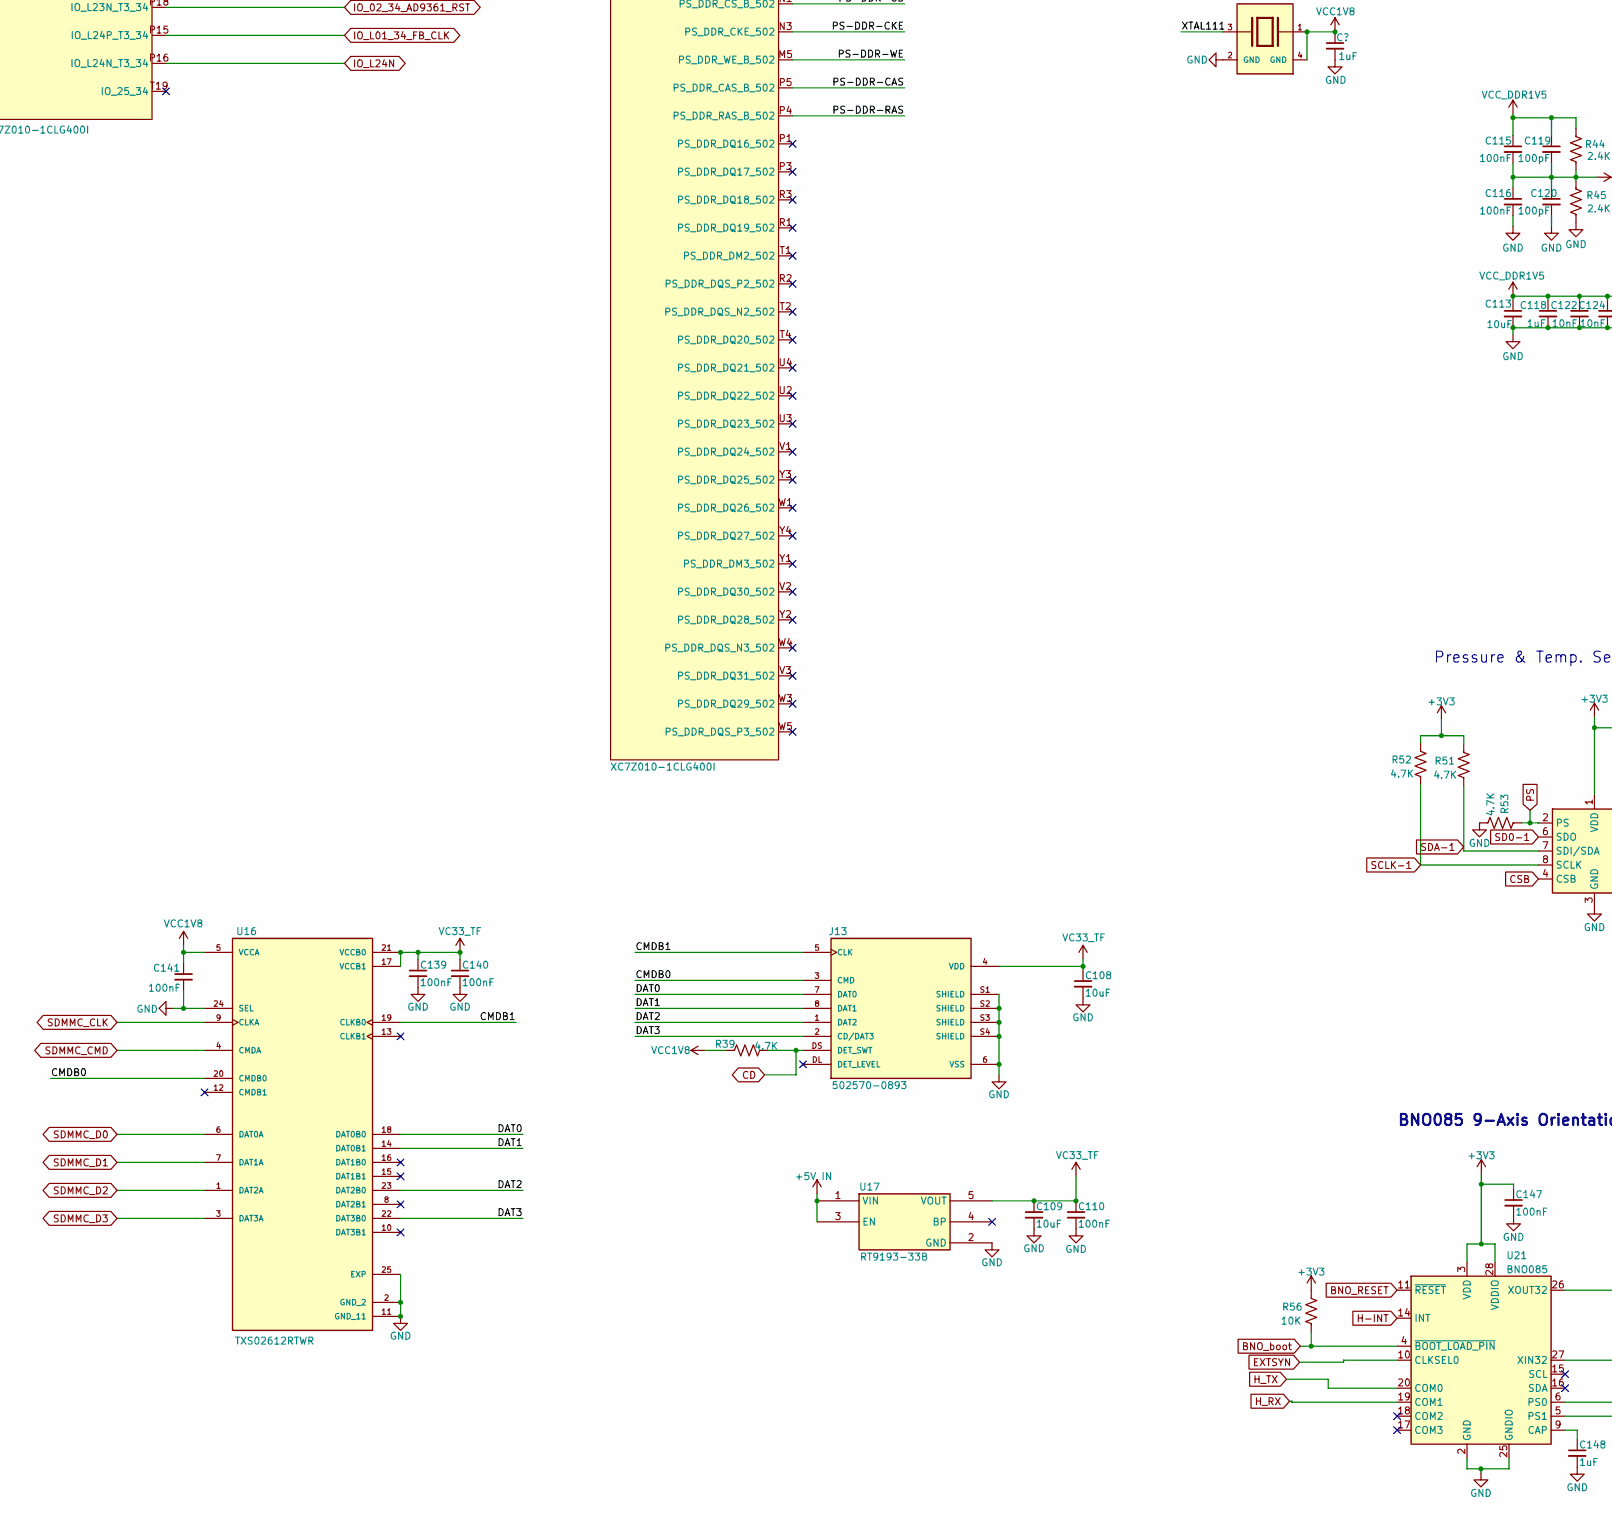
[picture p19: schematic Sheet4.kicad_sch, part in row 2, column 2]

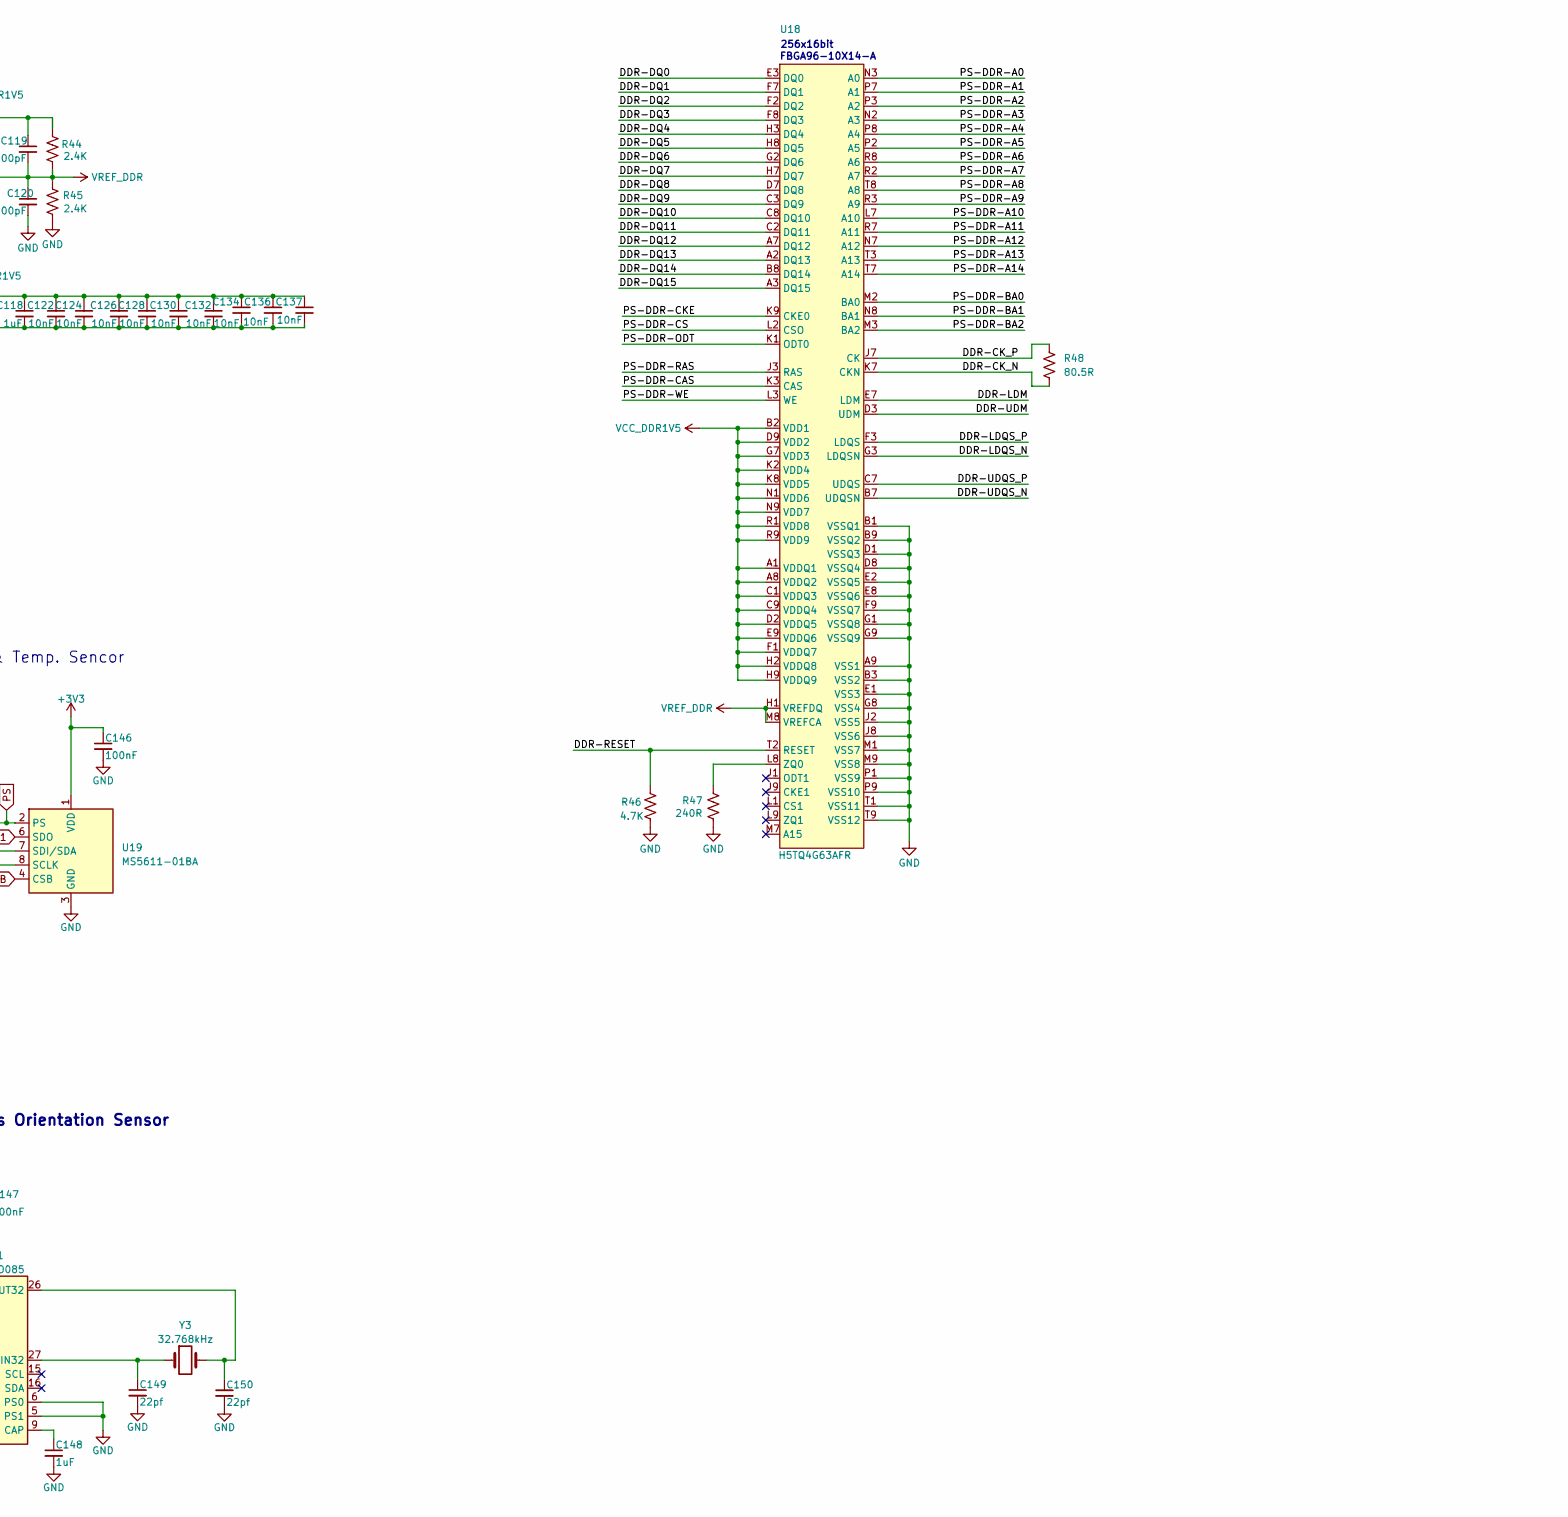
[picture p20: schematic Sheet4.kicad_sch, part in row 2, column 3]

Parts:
C92, C93, C97, C98, C101, C102, C103, C104, C107, C138: 0.1uF; C_0402_1005Metric_Pad0.74x0.62mm_HandSolder
C94, C95, C96, C113, C135: 10uF; C_0402_1005Metric_Pad0.74x0.62mm_HandSolder
C99, C100, C105, C106, C110, C115, C116, C139, C140, C141, C146, C147: 100nF; C_0402_1005Metric_Pad0.74x0.62mm_HandSolder
C108, C109: 10uF; C_0805_2012Metric_Pad1.18x1.45mm_HandSolder
C111, C112, C114, C118, C148: 1uF; C_0402_1005Metric_Pad0.74x0.62mm_HandSolder
C117, C121, C122, C123, C124, C125, C126, C127, C128, C129, C130, C131, C132, C133, C134, C136, C137: 10nF; C_0402_1005Metric_Pad0.74x0.62mm_HandSolder
C119, C120: 100pF; C_0402_1005Metric_Pad0.74x0.62mm_HandSolder
C149, C150: 22pf; C_0402_1005Metric_Pad0.74x0.62mm_HandSolder
CY2: 33.333MHz; XTAL_ABM8AIG-25.000MHZ-12-2Z-T3; PARTREV 43629
D3, D4: LED6; LED_0603_1608Metric_Pad1.05x0.95mm_HandSolder
J13: 502570-0893; MOLEX_502570-0893
Q3, Q4: SOT23 MOSFET FOOT PRINT
R33, R34, R35, R36, R44, R45: 2.4K; R_0402_1005Metric_Pad0.72x0.64mm_HandSolder
R37, R38, R48: 80.5R; R_0402_1005Metric_Pad0.72x0.64mm_HandSolder
R39, R40, R41, R42, R43, R46, R51, R52, R53: 4.7K; R_0402_1005Metric_Pad0.72x0.64mm_HandSolder
R47: 240R; R_0402_1005Metric_Pad0.72x0.64mm_HandSolder
R56: 10K; R_0402_1005Metric_Pad0.72x0.64mm_HandSolder
RA11, RA13, RA15, RA16, RA17, RA21, RA22, RA23, RA25, RA27: 20K; R_0402_1005Metric_Pad0.72x0.64mm_HandSolder
RA12, RA14, RA18: 1K; R_0402_1005Metric_Pad0.72x0.64mm_HandSolder
RA19, RA20: 33R; R_0402_1005Metric_Pad0.72x0.64mm_HandSolder
RA24, RA26: 100K; R_0402_1005Metric_Pad0.72x0.64mm_HandSolder
RA28, RA29: 4.7K; R_0402_1005Metric_Pad0.72x0.64mm_HandSolder
SW1: SW_DIP_x02; SW_DIP_SPSTx02_Slide_6.7x6.64mm_W6.73mm_P2.54mm_LowProfile_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
U14: XC7Z010-1CLG400I
U15: MX25U1635EZNI-10G
U16: TXS02612RTWR; PARTREV 4219135/B 11/2016
U17: RT9193-33B
U18: H5TQ4G63AFR
U19: MS5611-01BA; LGA-8_3x5mm_P1.25mm
U21: BNO085; IC_BNO080
Y3: 32.768kHz; Crystal_SMD_Qantek_QC5CB-2Pin_5x3.2mm

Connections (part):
+1V0: C92.1, C93.1, C94.1, C95.1, C96.1, C97.1, C98.1, C101.1, C102.1, C103.1, C104.1, C107.1, U14.G7 (VCCPINT), U14.G11 (VCCBRAM), U14.G13 (VCCINT), U14.H10 (VCCBRAM), U14.H12 (VCCINT), U14.J7 (VCCPINT), U14.J13 (VCCINT), U14.K12 (VCCINT), U14.L7 (VCCPINT), U14.L13 (VCCINT), U14.M12 (VCCINT), U14.N7 (VCCPINT), U14.N13 (VCCINT), U14.P8 (VCCPINT), U14.P12 (VCCINT), U14.R7 (VCCPINT), U14.R13 (VCCINT); also elsewhere on the board
+1V5: C99.1, C105.1, C113.1, C114.1, C115.1, C117.1, C118.1, C119.1, C121.1, C122.1, C123.1, C124.1, C125.1, C126.1, C127.1, C128.1, C129.1, C130.1, C131.1, C132.1, C133.1, C134.1, C135.1, C136.1, C137.1, R33.1, R35.1, R37.2, R44.1, U14.A3 (VCCO_DDR_502), U14.D2 (VCCO_DDR_502), U14.E5 (VCCO_DDR_502), U14.G1 (VCCO_DDR_502), U14.H4 (VCCO_DDR_502), U14.L3 (VCCO_DDR_502), U14.P2 (VCCO_DDR_502), U14.R5 (VCCO_DDR_502), U14.U1 (VCCO_DDR_502), U14.V4 (VCCO_DDR_502), U18.A1 (VDDQ1), U18.A8 (VDDQ2), U18.B2 (VDD1), U18.C1 (VDDQ3), U18.C9 (VDDQ4), U18.D2 (VDDQ5), U18.D9 (VDD2), U18.E9 (VDDQ6), U18.F1 (VDDQ7), U18.G7 (VDD3), U18.H2 (VDDQ8), U18.H9 (VDDQ9), U18.K2 (VDD4), U18.K8 (VDD5), U18.N1 (VDD6), U18.N9 (VDD7), U18.R1 (VDD8), U18.R9 (VDD9); also elsewhere on the board
+1V8: C111.1, C112.1, C141.1, CY2.1, CY2.4 (GND), R39.1, R40.2, R41.2, R42.1, RA12.1, RA17.1, RA21.2, RA22.2, RA23.1, RA25.2, RA26.1, RA27.1, U14.A13 (VCCO_MIO0_501), U14.B6 (VCCO_MIO0_500), U14.B16 (VCCO_MIO0_501), U14.C19 (VCCO_35), U14.D7 (VCCO_MIO0_500), U14.D12 (VCCO_MIO0_501), U14.E15 (VCCO_MIO0_501), U14.F8 (VCCPAUX), U14.F11 (VCCBATT_0), U14.F18 (VCCO_35), U14.G8 (VCCPLL), U14.G9 (VCCPAUX), U14.H8 (VCCPAUX), U14.H14 (VCCO_35), U14.J10 (GNDADC_0), U14.J11 (VCCAUX), U14.J17 (VCCO_35), U14.K6 (VCCO_0), U14.K8 (VCCPAUX), U14.K10 (VREFN_0), U14.K20 (VCCO_35), U14.L9 (VREFP_0), U14.L10 (VN_0), U14.L11 (VCCAUX), U14.M8 (VCCPAUX), U14.M9 (DXP_0), U14.M10 (DXN_0), U14.M16 (VCCO_35), U14.N6 (RSVDVCC3), U14.N9 (VCCAUX), U14.N11 (VCCAUX), U14.N19 (VCCO_34), U14.P10 (VCCAUX), U14.R6 (RSVDVCC2), U14.R9 (VCCAUX), U14.R15 (VCCO_34), U14.T6 (RSVDVCC1), U14.T8 (VCCO_13), U14.T18 (VCCO_34), U14.U11 (VCCO_13), U14.V14 (VCCO_34), U14.W7 (VCCO_13), U14.W17 (VCCO_34), U14.Y10 (VCCO_13), U14.Y20 (VCCO_34), U15.8 (VCC), U16.5 (VCCA); also elsewhere on the board
+15V: C115.2, C116.1, C119.2, C120.1, R44.2, R45.1, U18.H1 (VREFDQ), U18.M8 (VREFCA)
/Sheet4/CMDB0: J13.3 (CMD), U16.20 (CMDB0)
/Sheet4/CMDB1: J13.5 (CLK), U16.19 (CLKB0)
/Sheet4/DAT0: J13.7 (DAT0), U16.18 (DAT0B0)
/Sheet4/DAT1: J13.8 (DAT1), U16.14 (DAT0B1)
/Sheet4/DAT2: J13.1 (DAT2), U16.23 (DAT2B0)
/Sheet4/DAT3: J13.2 (CD/DAT3), U16.22 (DAT3B0)
/Sheet4/DDR-CK_N: R48.2, U14.M2 (PS_DDR_CKN_502), U18.K7 (CKN)
/Sheet4/DDR-CK_P: R48.1, U14.L2 (PS_DDR_CKP_502), U18.J7 (CK)
/Sheet4/DDR-DQ0: U14.C3 (PS_DDR_DQ0_502), U18.E3 (DQ0)
/Sheet4/DDR-DQ1: U14.B3 (PS_DDR_DQ1_502), U18.F7 (DQ1)
/Sheet4/DDR-DQ2: U14.A2 (PS_DDR_DQ2_502), U18.F2 (DQ2)
/Sheet4/DDR-DQ3: U14.A4 (PS_DDR_DQ3_502), U18.F8 (DQ3)
/Sheet4/DDR-DQ4: U14.D3 (PS_DDR_DQ4_502), U18.H3 (DQ4)
/Sheet4/DDR-DQ5: U14.D1 (PS_DDR_DQ5_502), U18.H8 (DQ5)
/Sheet4/DDR-DQ6: U14.C1 (PS_DDR_DQ6_502), U18.G2 (DQ6)
/Sheet4/DDR-DQ7: U14.E1 (PS_DDR_DQ7_502), U18.H7 (DQ7)
/Sheet4/DDR-DQ8: U14.E2 (PS_DDR_DQ8_502), U18.D7 (DQ8)
/Sheet4/DDR-DQ9: U14.E3 (PS_DDR_DQ9_502), U18.C3 (DQ9)
/Sheet4/DDR-DQ10: U14.G3 (PS_DDR_DQ10_502), U18.C8 (DQ10)
/Sheet4/DDR-DQ11: U14.H3 (PS_DDR_DQ11_502), U18.C2 (DQ11)
/Sheet4/DDR-DQ12: U14.J3 (PS_DDR_DQ12_502), U18.A7 (DQ12)
/Sheet4/DDR-DQ13: U14.H2 (PS_DDR_DQ13_502), U18.A2 (DQ13)
/Sheet4/DDR-DQ14: U14.H1 (PS_DDR_DQ14_502), U18.B8 (DQ14)
/Sheet4/DDR-DQ15: U14.J1 (PS_DDR_DQ15_502), U18.A3 (DQ15)
/Sheet4/DDR-LDM: U14.A1 (PS_DDR_DM0_502), U18.E7 (LDM)
/Sheet4/DDR-LDQS_N: U14.B2 (PS_DDR_DQS_N0_502), U18.G3 (LDQSN)
/Sheet4/DDR-LDQS_P: U14.C2 (PS_DDR_DQS_P0_502), U18.F3 (LDQS)
/Sheet4/DDR-RESET: R46.1, U14.B4 (PS_DDR_DRST_B_502), U18.T2 (RESET)
/Sheet4/DDR-UDM: U14.F1 (PS_DDR_DM1_502), U18.D3 (UDM)
/Sheet4/DDR-UDQS_N: U14.F2 (PS_DDR_DQS_N1_502), U18.B7 (UDQSN)
/Sheet4/DDR-UDQS_P: U14.G2 (PS_DDR_DQS_P1_502), U18.C7 (UDQS)
/Sheet4/H6: C99.2, C100.1, R33.2, R34.1, U14.H6 (PS_DDR_VREF0_502)
/Sheet4/P6: C105.2, C106.1, R35.2, R36.1, U14.P6 (PS_DDR_VREF1_502)
/Sheet4/PS-DDR-A0: U14.N2 (PS_DDR_A0_502), U18.N3 (A0)
/Sheet4/PS-DDR-A1: U14.K2 (PS_DDR_A1_502), U18.P7 (A1)
/Sheet4/PS-DDR-A2: U14.M3 (PS_DDR_A2_502), U18.P3 (A2)
/Sheet4/PS-DDR-A3: U14.K3 (PS_DDR_A3_502), U18.N2 (A3)
/Sheet4/PS-DDR-A4: U14.M4 (PS_DDR_A4_502), U18.P8 (A4)
/Sheet4/PS-DDR-A5: U14.L1 (PS_DDR_A5_502), U18.P2 (A5)
/Sheet4/PS-DDR-A6: U14.L4 (PS_DDR_A6_502), U18.R8 (A6)
/Sheet4/PS-DDR-A7: U14.K4 (PS_DDR_A7_502), U18.R2 (A7)
/Sheet4/PS-DDR-A8: U14.K1 (PS_DDR_A8_502), U18.T8 (A8)
/Sheet4/PS-DDR-A9: U14.J4 (PS_DDR_A9_502), U18.R3 (A9)
/Sheet4/PS-DDR-A10: U14.F5 (PS_DDR_A10_502), U18.L7 (A10)
/Sheet4/PS-DDR-A11: U14.G4 (PS_DDR_A11_502), U18.R7 (A11)
/Sheet4/PS-DDR-A12: U14.E4 (PS_DDR_A12_502), U18.N7 (A12)
/Sheet4/PS-DDR-A13: U14.D4 (PS_DDR_A13_502), U18.T3 (A13)
/Sheet4/PS-DDR-A14: U14.F4 (PS_DDR_A14_502), U18.T7 (A14)
/Sheet4/PS-DDR-BA0: U14.L5 (PS_DDR_BA0_502), U18.M2 (BA0)
/Sheet4/PS-DDR-BA1: U14.R4 (PS_DDR_BA1_502), U18.N8 (BA1)
/Sheet4/PS-DDR-BA2: U14.J5 (PS_DDR_BA2_502), U18.M3 (BA2)
/Sheet4/PS-DDR-CAS: U14.P5 (PS_DDR_CAS_B_502), U18.K3 (CAS)
/Sheet4/PS-DDR-CKE: U14.N3 (PS_DDR_CKE_502), U18.K9 (CKE0)
/Sheet4/PS-DDR-CS: U14.N1 (PS_DDR_CS_B_502), U18.L2 (CSO)
/Sheet4/PS-DDR-ODT: U14.N5 (PS_DDR_ODT_502_), U18.K1 (ODT0)
/Sheet4/PS-DDR-RAS: U14.P4 (PS_DDR_RAS_B_502), U18.J3 (RAS)
/Sheet4/PS-DDR-WE: U14.M5 (PS_DDR_WE_B_502), U18.L3 (WE)
/Sheet4/XTAL111: CY2.3, RA19.2
BNO_RESET: U14.G19 (IO_L18P_T2_AD13P_35), U21.11 (~RESET)
BNO_boot: R56.2, U14.H15 (IO_L19P_T3_35), U21.4 (~BOOT_LOAD_PIN)
CD: J13.DS (DET_SWT), R39.2, U14.B14 (PS_MIO47_501)
CSB: U14.H20 (IO_L17N_T2_AD5N_35), U19.4 (CSB), U19.5 (CSB)
CTRL_IN0: U14.E17 (IO_L3P_T0_DQS_AD1P_35); also elsewhere on the board
CTRL_IN1: U14.D18 (IO_L3N_T0_DQS_AD1N_35); also elsewhere on the board
CTRL_IN2: U14.E18 (IO_L5P_T0_AD9P_35); also elsewhere on the board
CTRL_IN3: U14.E19 (IO_L5N_T0_AD9N_35); also elsewhere on the board
DONE: Q4.1 (G), U14.R11 (DONE_0); also elsewhere on the board
ETH_RXCTL: U14.D13 (PS_MIO27_501); also elsewhere on the board
EXTSYN: U14.G15 (IO_L19N_T3_VREF_35), U21.10 (CLKSEL0)
FPGA-REST: C138.1, RA27.2, U14.C7 (PS_POR_B_501)
GND: C92.2, C93.2, C94.2, C95.2, C96.2, C97.2, C98.2, C100.2, C101.2, C102.2, C103.2, C104.2, C106.2, C107.2, C108.2, C109.2, C110.2, C111.2, C112.2, C113.2, C114.2, C116.2, C117.2, C118.2, C120.2, C121.2, C122.2, C123.2, C124.2, C125.2, C126.2, C127.2, C128.2, C129.2, C130.2, C131.2, C132.2, C133.2, C134.2, C135.2, C136.2, C137.2, C138.2, C139.2, C140.2, C141.2, C146.2, C147.2, C148.2, C149.2, C150.2, CY2.2 (GND), J13.6 (VSS), J13.S1 (SHIELD), J13.S2 (SHIELD), J13.S3 (SHIELD), J13.S4 (SHIELD), Q3.2 (S), Q4.2 (S), R34.2, R36.2, R38.2, R43.2, R45.2, R46.2, R47.2, R53.2, RA11.2, RA14.2, RA15.2, RA16.2, RA24.1, SW1.4, U14.A8 (GND), U14.A18 (GND), U14.B1 (GND), U14.B11 (GND), U14.C4 (GND), U14.C9 (GND), U14.C14 (GND), U14.D17 (GND), U14.E10 (GND), U14.E20 (GND)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; also elsewhere on the board
H-INT: U14.G20 (IO_L18N_T2_AD13N_35), U21.14 (INT)
H_RX: U14.K14 (IO_L20P_T3_AD6P_35), U21.19 (COM1)
H_TX: U14.J14 (IO_L20N_T3_AD6N_35), U21.20 (COM0)
IO_02_34_AD9361_CLKOUT: U14.N17 (IO_L23P_T3_34); also elsewhere on the board
IO_02_34_AD9361_RST: U14.P18 (IO_L23N_T3_34); also elsewhere on the board
IO_L01_34_FB_CLK: U14.P15 (IO_L24P_T3_34); also elsewhere on the board
IO_L01_34_RX_D0: U14.V13 (IO_L3N_T0_DQS_34); also elsewhere on the board
IO_L01_34_RX_D1: U14.T14 (IO_L5P_T0_34); also elsewhere on the board
IO_L02_34_RX_D2: U14.U13 (IO_L3P_T0_DQS_PUDC_B_34); also elsewhere on the board
IO_L02_34_RX_D3: U14.U12 (IO_L2N_T0_34); also elsewhere on the board
IO_L03_34_RX_D4: U14.T12 (IO_L2P_T0_34); also elsewhere on the board
IO_L03_34_RX_D5: U14.T10 (IO_L1N_T0_34); also elsewhere on the board
IO_L4N_TO_35: U14.D20 (IO_L4N_T0_35); also elsewhere on the board
IO_L4P_TO_35: U14.D19 (IO_L4P_T0_35); also elsewhere on the board
IO_L04_34_RX_D6: U14.T11 (IO_L1P_T0_34); also elsewhere on the board
IO_L04_34_RX_D7: U14.T15 (IO_L5N_T0_34); also elsewhere on the board
IO_L05_34_RX_D8: U14.V12 (IO_L4P_T0_34); also elsewhere on the board
IO_L05_34_RX_D9: U14.W13 (IO_L4N_T0_34); also elsewhere on the board
IO_L06_34_RX_D10: U14.P14 (IO_L6P_T0_34); also elsewhere on the board
IO_L06_34_RX_D11: U14.R14 (IO_L6N_T0_VREF_34); also elsewhere on the board
IO_L7N: U14.M20 (IO_L7N_T1_AD2N_35); also elsewhere on the board
IO_L7P: U14.M19 (IO_L7P_T1_AD2P_35); also elsewhere on the board
IO_L07_34_RX_FRAME: U14.Y16 (IO_L7P_T1_34); also elsewhere on the board
IO_L08_34_CTRL_OUT0: U14.W14 (IO_L8P_T1_34); also elsewhere on the board
IO_L08_34_CTRL_OUT1: U14.Y14 (IO_L8N_T1_34); also elsewhere on the board
IO_L9N: U14.L20 (IO_L9N_T1_DQS_AD3N_35); also elsewhere on the board
IO_L09_34_TX_FRAME: U14.T16 (IO_L9P_T1_DQS_34); also elsewhere on the board
IO_L10P: U14.V15 (IO_L10P_T1_34); also elsewhere on the board
IO_L10_34_EN_AGC: U14.W15 (IO_L10N_T1_34); also elsewhere on the board
IO_L11_34_ENABLE: U14.U15 (IO_L11N_T1_SRCC_34); also elsewhere on the board
IO_L11_34_TXNRX: U14.U14 (IO_L11P_T1_SRCC_34); also elsewhere on the board
IO_L12N: U14.U19 (O_L12N_T1_MRCC_34); also elsewhere on the board
IO_L12_MRCC_34_DATA_CLK: U14.U18 (IO_L12P_T1_MRCC_34); also elsewhere on the board
IO_L13_34_CTRL_OUT2: U14.N18 (IO_L13P_T2_MRCC_34)
IO_L13_34_CTRL_OUT3: U14.P19 (IO_L13N_T2_MRCC_34)
IO_L15P_T2: U14.F19 (IO_L15P_T2_DQS_AD12P_35), U14.F20 (IO_L15N_T2_DQS_AD12N_35); also elsewhere on the board
IO_L15_34_TX_D0: U14.T20 (IO_L15P_T2_DQS_34); also elsewhere on the board
IO_L15_34_TX_D1: U14.Y19 (IO_L17N_T2_34); also elsewhere on the board
IO_L16_34_TX_D2: U14.U20 (IO_L15N_T2_DQS_34); also elsewhere on the board
IO_L16_34_TX_D3: U14.V20 (IO_L16P_T2_34); also elsewhere on the board
IO_L17_34_TX_D4: U14.W20 (IO_L16N_T2_34); also elsewhere on the board
IO_L17_34_TX_D5: U14.Y18 (IO_L17P_T2_34); also elsewhere on the board
IO_L18_34_TX_D6: U14.W16 (IO_L18N_T2_34); also elsewhere on the board
IO_L18_34_TX_D7: U14.V16 (IO_L18P_T2_34); also elsewhere on the board
IO_L19_34_TX_D8: U14.R17 (IO_L19N_T3_VREF_34); also elsewhere on the board
IO_L19_34_TX_D9: U14.R16 (IO_L19P_T3_34); also elsewhere on the board
IO_L20_34_TX_D10: U14.R18 (IO_L20N_T3_34); also elsewhere on the board
IO_L20_34_TX_D11: U14.T17 (IO_L20P_T3_34); also elsewhere on the board
IO_L21_34_CTRL_OUT4: U14.V17 (IO_L21P_T3_DQS_34)
IO_L21_34_CTRL_OUT5: U14.V18 (IO_L21N_T3_DQS_34)
IO_L22_34_CTRL_OUT6: U14.W18 (IO_L22P_T3_34)
IO_L22_34_CTRL_OUT7: U14.W19 (IO_L22N_T3_34)
IO_L23_35_SPI_CLK: U14.B19 (IO_L2P_T0_AD8P_35); also elsewhere on the board
IO_L23_35_SPI_ENB: U14.A20 (IO_L2N_T0_AD8N_35); also elsewhere on the board
IO_L24N: U14.P16 (IO_L24N_T3_34); also elsewhere on the board
IO_L24_35_SPI_D0: U14.C20 (IO_L1P_T0_AD0P_35); also elsewhere on the board
IO_L24_35_SPI_DI: U14.B20 (IO_L1N_T0_AD0N_35); also elsewhere on the board
JTAG_BOOT: RA18.2; also elsewhere on the board
MAC_MDIO: U14.C11 (PS_MIO53_501); also elsewhere on the board
unnamed: D3.2 (A), RA28.2
unnamed: D3.1 (K), Q3.3 (D)
unnamed: D4.2 (A), RA29.2
unnamed: D4.1 (K), Q4.3 (D)
unnamed: R40.1, U14.R10 (INIT_B_0)
unnamed: R41.1, U14.L6 (PROGRAM_B_0)
unnamed: R42.2, R43.1, U14.K9 (VP_0)
unnamed: R38.1, U14.G5 (PS_DDR_VRN_502)
unnamed: R37.1, U14.H5 (PS_DDR_VRP_502)
unnamed: RA19.1, U14.E7 (PS_CLK_500)
unnamed: RA21.1, U14.D8 (PS_MIO7_500)
unnamed: RA22.1, U14.D5 (PS_MIO8_500)
unnamed: RA20.1, U14.C5 (PS_MIO14_500)
unnamed: RA24.2, RA26.2, U14.E11 (PS_MIO_VREF_501)
unnamed: RA25.1, U14.B10 (PS_SRST_B_501)
unnamed: R47.1, U18.L8 (ZQ0)
unnamed: C148.1, U21.9 (CAP)
unnamed: C149.1, U21.27 (XIN32), Y3.1
unnamed: C150.1, U21.26 (XOUT32), Y3.2
PHY_RXCLK: U14.B17 (PS_MIO22_501); also elsewhere on the board
PHY_RXD0: U14.D11 (PS_MIO23_501); also elsewhere on the board
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

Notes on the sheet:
256x16bit
Pressure & Temp. Sencor
FBGA96-10X14-A
BNO085 9-Axis Orientation Sensor

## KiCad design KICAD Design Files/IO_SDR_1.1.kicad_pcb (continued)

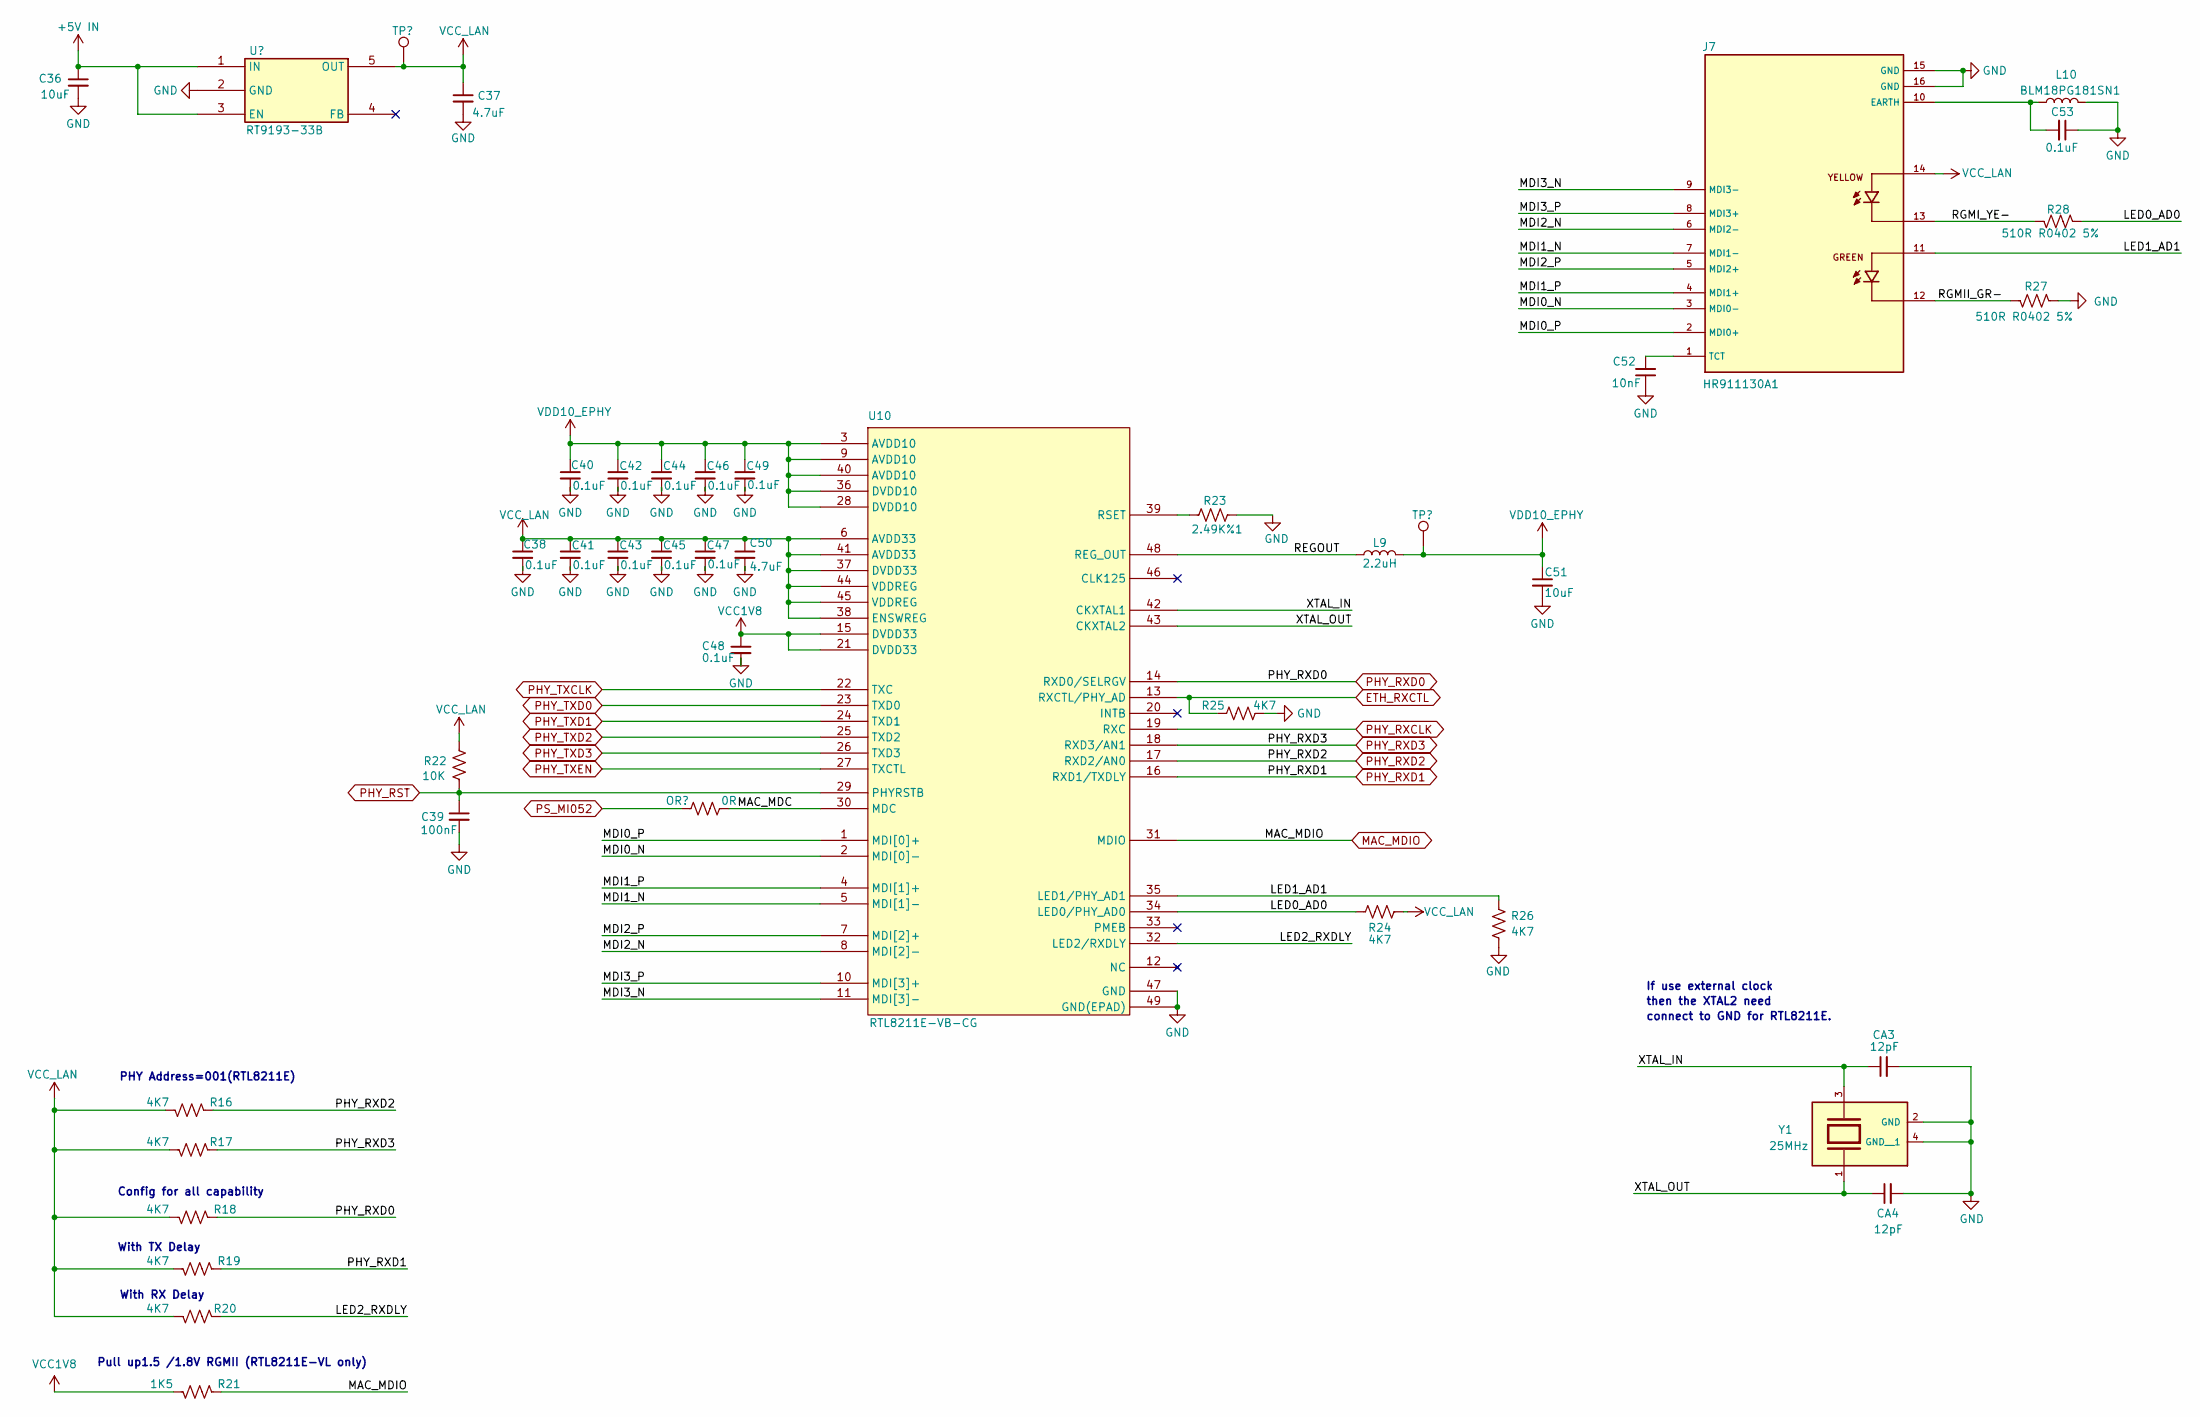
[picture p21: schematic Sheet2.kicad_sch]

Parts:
C36: 10uF; C_0603_1608Metric
C37, C50: 4.7uF; C_0603_1608Metric_Pad1.08x0.95mm_HandSolder
C38, C40, C41, C42, C43, C44, C45, C46, C47, C48, C49: 0.1uF; C_0402_1005Metric_Pad0.74x0.62mm_HandSolder
C39: 100nF; C_0402_1005Metric_Pad0.74x0.62mm_HandSolder
C51: 10uF; C_0805_2012Metric_Pad1.18x1.45mm_HandSolder
C52: 10nF; C_0402_1005Metric_Pad0.74x0.62mm_HandSolder
C53: 0.1uF; C_0805_2012Metric_Pad1.18x1.45mm_HandSolder
CA3, CA4: 12pF; C_0402_1005Metric_Pad0.74x0.62mm_HandSolder
J7: HR911130A1; HR911130A_HAN
L9: 2.2uH; L_0603_1608Metric_Pad1.05x0.95mm_HandSolder
L10: BLM18PG181SN1; L_0603_1608Metric_Pad1.05x0.95mm_HandSolder
R16, R17, R18, R19, R20, R24, R25, R26: 4K7; R_0402_1005Metric_Pad0.72x0.64mm_HandSolder
R21: 1K5; R_0402_1005Metric_Pad0.72x0.64mm_HandSolder
R22: 10K; R_0402_1005Metric_Pad0.72x0.64mm_HandSolder
R23: 2.49K%1; R_0402_1005Metric_Pad0.72x0.64mm_HandSolder
R27, R28: 510R R0402 5%; R_0402_1005Metric_Pad0.72x0.64mm_HandSolder
RA5: 0R; R_0603_1608Metric_Pad0.98x0.95mm_HandSolder
TP13, TP14: TestPoint; TestPoint_Pad_D1.0mm
U9: RT9193-33B
U10: RTL8211E-VB-CG
Y1: 25MHz; XTAL_TSX-3225_25.0000MF10P-C0; PARTREV N/A

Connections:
+1V8: C48.1, R21.1, U10.15 (DVDD33), U10.21 (DVDD33); also elsewhere on the board
+36V: C40.1, C42.1, C44.1, C46.1, C49.1, C51.1, L9.2, TP14.1, U10.3 (AVDD10), U10.9 (AVDD10), U10.28 (DVDD10), U10.36 (DVDD10), U10.40 (AVDD10)
/Sheet2/LED0_AD0: R24.2, R28.2, U10.34 (LED0/PHY_AD0)
/Sheet2/LED1_AD1: J7.11, R26.2, U10.35 (LED1/PHY_AD1)
/Sheet2/LED2_RXDLY: R20.2, U10.32 (LED2/RXDLY)
/Sheet2/MAC_MDC: RA5.1, U10.30 (MDC)
/Sheet2/MDI0_N: J7.3 (MDI0-), U10.2 (MDI[0]-)
/Sheet2/MDI0_P: J7.2 (MDI0+), U10.1 (MDI[0]+)
/Sheet2/MDI1_N: J7.7 (MDI1-), U10.5 (MDI[1]-)
/Sheet2/MDI1_P: J7.4 (MDI1+), U10.4 (MDI[1]+)
/Sheet2/MDI2_N: J7.6 (MDI2-), U10.8 (MDI[2]-)
/Sheet2/MDI2_P: J7.5 (MDI2+), U10.7 (MDI[2]+)
/Sheet2/MDI3_N: J7.9 (MDI3-), U10.11 (MDI[3]-)
/Sheet2/MDI3_P: J7.8 (MDI3+), U10.10 (MDI[3]+)
/Sheet2/REGOUT: L9.1, U10.48 (REG_OUT)
/Sheet2/RGMII_GR-: J7.12, R27.1
/Sheet2/RGMI_YE-: J7.13, R28.1
/Sheet2/XTAL_IN: CA3.1, U10.42 (CKXTAL1), Y1.3
/Sheet2/XTAL_OUT: CA4.1, U10.43 (CKXTAL2), Y1.1
ETH_RXCTL: R25.2, U10.13 (RXCTL/PHY_AD); also elsewhere on the board
GND: C36.2, C37.2, C38.2, C39.2, C40.2, C41.2, C42.2, C43.2, C44.2, C45.2, C46.2, C47.2, C48.2, C49.2, C50.2, C51.2, C52.1, C53.1, CA3.2, CA4.2, J7.15 (GND), J7.16 (GND), L10.1, R23.1, R25.1, R26.1, R27.2, U9.2 (GND), U10.47 (GND), U10.49 (GND(EPAD)), Y1.2 (GND), Y1.4 (GND__1); also elsewhere on the board
MAC_MDIO: R21.2, U10.31 (MDIO); also elsewhere on the board
unnamed: C53.2, J7.10 (EARTH), L10.2
unnamed: C52.2, J7.1 (TCT)
unnamed: R23.2, U10.39 (RSET)
PHY_RST: C39.1, R22.1, U10.29 (PHYRSTB)
PHY_RXCLK: U10.19 (RXC); also elsewhere on the board
PHY_RXD0: R18.2, U10.14 (RXD0/SELRGV); also elsewhere on the board
PHY_RXD1: R19.2, U10.16 (RXD1/TXDLY); also elsewhere on the board
PHY_RXD2: R16.2, U10.17 (RXD2/AN0); also elsewhere on the board
PHY_RXD3: R17.2, U10.18 (RXD3/AN1); also elsewhere on the board
PHY_TXCLK: U10.22 (TXC); also elsewhere on the board
PHY_TXD0: U10.23 (TXD0); also elsewhere on the board
PHY_TXD1: U10.24 (TXD1); also elsewhere on the board
PHY_TXD2: U10.25 (TXD2); also elsewhere on the board
PHY_TXD3: U10.26 (TXD3); also elsewhere on the board
PHY_TXEN: U10.27 (TXCTL); also elsewhere on the board
PS_MI052: RA5.2; also elsewhere on the board
VCC: C37.1, C38.1, C41.1, C43.1, C45.1, C47.1, C50.1, J7.14, R16.1, R17.1, R18.1, R19.1, R20.1, R22.2, R24.1, TP13.1, U9.5 (OUT), U10.6 (AVDD33), U10.37 (DVDD33), U10.38 (ENSWREG), U10.41 (AVDD33), U10.44 (VDDREG), U10.45 (VDDREG)

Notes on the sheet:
then the XTAL2 need
PHY Address=001(RTL8211E)
With RX Delay
Pull up1.5 /1.8V RGMII (RTL8211E-VL only)
connect to GND for RTL8211E.
If use external clock
Config for all capability
With TX Delay

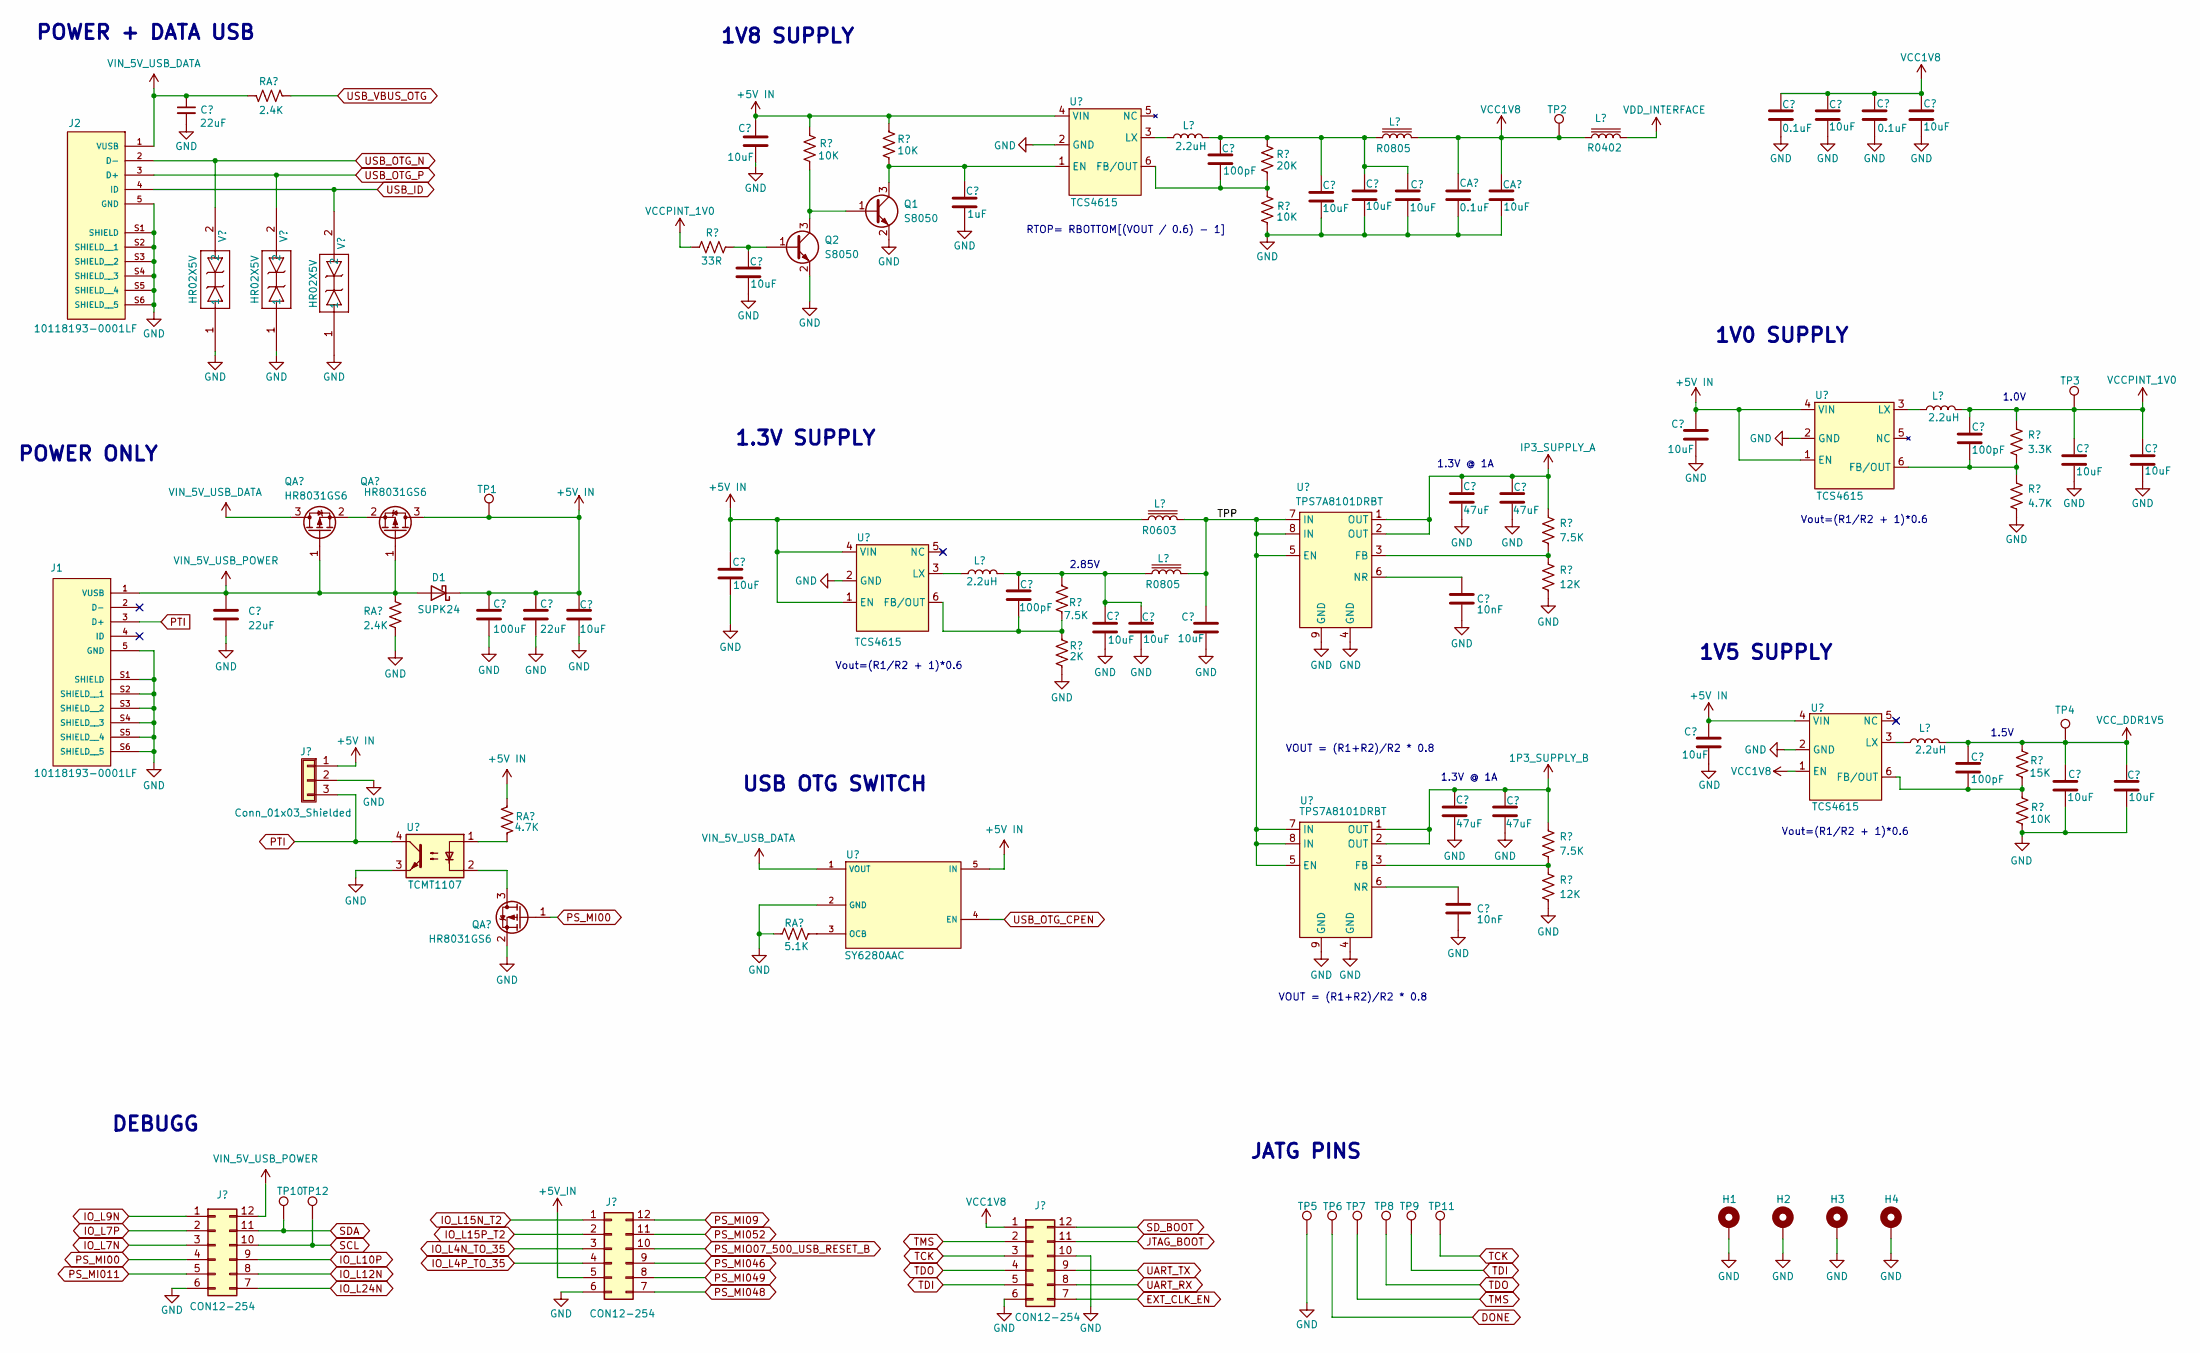
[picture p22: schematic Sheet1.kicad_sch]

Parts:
C1, C2: 22uF; C_1206_3216Metric_Pad1.33x1.80mm_HandSolder
C3: 100uF; C_0805_2012Metric_Pad1.18x1.45mm_HandSolder
C4: 22uF; C_0805_2012Metric_Pad1.18x1.45mm_HandSolder
C5: 10uF; C_0805_2012Metric_Pad1.18x1.45mm_HandSolder
C6, C11, C12, C13, C15, C16, C18, C19, C25, C28, C29, C32, C33, C34, C35: 10uF; C_0603_1608Metric_Pad1.08x0.95mm_HandSolder
C7, C8: 10uF; C_1206_3216Metric_Pad1.33x1.80mm_HandSolder
C9: 1uF; C_0805_2012Metric_Pad1.18x1.45mm_HandSolder
C10, C14, C30, C31: 100pF; C_0402_1005Metric_Pad0.74x0.62mm_HandSolder
C17, C20: 0.1uF; C_0402_1005Metric_Pad0.74x0.62mm_HandSolder
C21, C23, C26, C27: 47uF; C_1206_3216Metric_Pad1.33x1.80mm_HandSolder
C22, C24: 10nF; C_0402_1005Metric_Pad0.74x0.62mm_HandSolder
CA1: 0.1uF; C_0402_1005Metric_Pad0.74x0.62mm_HandSolder
CA2: 10uF; C_0603_1608Metric_Pad1.08x0.95mm_HandSolder
D1: SUPK24; D_SOD-123
H1, H2, H3, H4: MountingHole_Pad; MountingHole_2.5mm_Pad
J1, J2: 10118193-0001LF; AMPHENOL_10118193-0001LF; PARTREV E
J3: Conn_01x03_Shielded; PinHeader_1x03_P2.54mm_Vertical
J4, J5, J6: CON12-254; PinHeader_2x06_P2.54mm_Vertical
L1, L4, L7, L8: 2.2uH; L_0603_1608Metric_Pad1.05x0.95mm_HandSolder
L2: R0603; L_0603_1608Metric_Pad1.05x0.95mm_HandSolder
L3, L5: R0805; L_0805_2012Metric_Pad1.05x1.20mm_HandSolder
L6: R0402; L_0402_1005Metric_Pad0.77x0.64mm_HandSolder
Q1, Q2: S8050; SOT-23
QA1, QA2, QA3: HR8031GS6
R1: 33R; R_0402_1005Metric_Pad0.72x0.64mm_HandSolder
R2, R3, R7, R15: 10K; R_0402_1005Metric_Pad0.72x0.64mm_HandSolder
R4, R8, R10: 7.5K; R_0402_1005Metric_Pad0.72x0.64mm_HandSolder
R5: 2K; R_0402_1005Metric_Pad0.72x0.64mm_HandSolder
R6: 20K; R_0402_1005Metric_Pad0.72x0.64mm_HandSolder
R9, R11: 12K; R_0402_1005Metric_Pad0.72x0.64mm_HandSolder
R12: 3.3K; R_0402_1005Metric_Pad0.72x0.64mm_HandSolder
R13: 4.7K; R_0402_1005Metric_Pad0.72x0.64mm_HandSolder
R14: 15K; R_0402_1005Metric_Pad0.72x0.64mm_HandSolder
RA1, RA2: 2.4K; R_0402_1005Metric_Pad0.72x0.64mm_HandSolder
RA3: 4.7K; R_0603_1608Metric_Pad0.98x0.95mm_HandSolder
RA4: 5.1K; R_0603_1608Metric_Pad0.98x0.95mm_HandSolder
TP1, TP2, TP3, TP4, TP5, TP6, TP7, TP8, TP9, TP10, TP11, TP12: TestPoint; TestPoint_Pad_D1.0mm
U1: TCMT1107; SOP-4_4.4x2.6mm_P1.27mm
U2: SY6280AAC
U3, U4, U7, U8: TCS4615
U5, U6: TPS7A8101DRBT
V1, V2, V3: HR02X5V

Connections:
+1V0: C30.1, C32.1, C35.1, L8.2, R1.1, R12.1, TP3.1; also elsewhere on the board
+1V2: C21.1, C26.1, R10.1, U6.1 (OUT), U6.2 (OUT); also elsewhere on the board
+1V5: C31.1, C33.1, C34.1, L7.2, R14.1, TP4.1; also elsewhere on the board
+1V8: C17.1, C19.1, C20.1, C25.1, CA1.1, CA2.1, J5.1, L5.2, L6.1, TP2.1, U7.1 (EN); also elsewhere on the board
+5VD: C2.1, D1.2 (A), J1.1 (VUSB), J4.12, QA1.1 (G), QA2.1 (G), RA2.1
+5VP: C1.1, J2.1 (VUSB), QA1.3 (D), RA1.2, U2.1 (VOUT)
+12L: C23.1, C27.1, R8.1, U5.1 (OUT), U5.2 (OUT); also elsewhere on the board
+VSW: L6.2; also elsewhere on the board
/Sheet1/TPP: C13.1, L2.2, L3.2, U5.5 (EN), U5.7 (IN), U5.8 (IN), U6.5 (EN), U6.7 (IN), U6.8 (IN)
DONE: TP6.1; also elsewhere on the board
EXT_CLK_EN: J5.7; also elsewhere on the board
GND: C1.2, C2.2, C3.2, C4.2, C5.2, C6.2, C7.2, C8.2, C9.2, C11.2, C12.2, C13.2, C15.2, C16.2, C17.2, C18.2, C19.2, C20.2, C21.2, C22.2, C23.2, C24.2, C25.2, C26.2, C27.2, C28.2, C29.2, C32.2, C33.2, C34.2, C35.2, CA1.2, CA2.2, H1.1, H2.1, H3.1, H4.1, J1.5 (GND), J1.S1 (SHIELD), J1.S2 (SHIELD__1), J1.S3 (SHIELD__2), J1.S4 (SHIELD__3), J1.S5 (SHIELD__4), J1.S6 (SHIELD__5), J2.5 (GND), J2.S1 (SHIELD), J2.S2 (SHIELD__1), J2.S3 (SHIELD__2), J2.S4 (SHIELD__3), J2.S5 (SHIELD__4), J2.S6 (SHIELD__5), J3.2, J4.6, J5.6, J5.10, J6.6, Q1.2 (E), Q2.2 (E), QA3.2 (S), R5.2, R7.2, R9.2, R11.2, R13.2, R15.2, RA2.2, RA4.2, TP5.1, U1.3, U2.2 (GND), U3.2 (GND), U4.2 (GND), U5.4 (GND), U5.9 (GND), U6.4 (GND), U6.9 (GND), U7.2 (GND), U8.2 (GND), V1.1, V2.1, V3.1; also elsewhere on the board
IO_L4N_TO_35: J6.3; also elsewhere on the board
IO_L4P_TO_35: J6.4; also elsewhere on the board
IO_L7N: J4.3; also elsewhere on the board
IO_L7P: J4.2; also elsewhere on the board
IO_L9N: J4.1; also elsewhere on the board
IO_L10P: J4.9; also elsewhere on the board
IO_L12N: J4.8; also elsewhere on the board
IO_L15N_T2: J6.1
IO_L15P_T2: J6.2; also elsewhere on the board
IO_L24N: J4.7; also elsewhere on the board
JTAG_BOOT: J5.11; also elsewhere on the board
unnamed: C10.1, C11.1, C12.1, L1.2, L3.1, R4.1
unnamed: C14.1, C15.1, C16.1, C18.1, L4.2, L5.1, R6.1
unnamed: Q1.1 (B), Q2.3 (C), R2.2
unnamed: C9.1, Q1.3 (C), R3.2, U4.1 (EN)
unnamed: C7.1, Q2.1 (B), R1.2
unnamed: QA1.2 (S), QA2.2 (S)
unnamed: QA3.3 (D), U1.2
unnamed: RA3.2, U1.1
unnamed: RA4.1, U2.3 (OCB)
unnamed: C10.2, R4.2, R5.1, U3.6 (FB/OUT)
unnamed: L1.1, U3.3 (LX)
unnamed: C14.2, R6.2, R7.1, U4.6 (FB/OUT)
unnamed: L4.1, U4.3 (LX)
unnamed: R8.2, R9.1, U5.3 (FB)
unnamed: C24.1, U5.6 (NR)
unnamed: R10.2, R11.1, U6.3 (FB)
unnamed: C22.1, U6.6 (NR)
unnamed: C31.2, R14.2, R15.1, U7.6 (FB/OUT)
unnamed: L7.1, U7.3 (LX)
unnamed: C30.2, R12.2, R13.1, U8.6 (FB/OUT)
unnamed: L8.1, U8.3 (LX)
PS_MI00: J4.4, QA3.1 (G); also elsewhere on the board
PS_MI09: J6.12; also elsewhere on the board
PS_MI011: J4.5; also elsewhere on the board
PS_MI046: J6.9; also elsewhere on the board
PS_MI048: J6.7; also elsewhere on the board
PS_MI049: J6.8; also elsewhere on the board
PS_MI052: J6.11; also elsewhere on the board
PS_MIO07_500_USB_RESET_B: J6.10; also elsewhere on the board
PTI: J1.3 (D+), J3.3, U1.4
SCL: J4.10, TP12.1; also elsewhere on the board
SDA: J4.11, TP10.1; also elsewhere on the board
SD_BOOT: J5.12; also elsewhere on the board
TCK: J5.3, TP11.1; also elsewhere on the board
TDI: J5.5, TP9.1; also elsewhere on the board
TDO: J5.4, TP8.1; also elsewhere on the board
TMS: J5.2, TP7.1; also elsewhere on the board
UART_RX: J5.8; also elsewhere on the board
UART_TX: J5.9; also elsewhere on the board
USB_ID: J2.4 (ID), V3.2; also elsewhere on the board
USB_OTG_CPEN: U2.4 (EN); also elsewhere on the board
USB_OTG_N: J2.2 (D-), V1.2; also elsewhere on the board
USB_OTG_P: J2.3 (D+), V2.2; also elsewhere on the board
USB_VBUS_OTG: RA1.1; also elsewhere on the board

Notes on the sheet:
1.3V @ 1A
POWER + DATA USB
RTOP= RBOTTOM[(VOUT / 0.6) - 1]
POWER ONLY
1V0 SUPPLY
DEBUGG
1.0V
JATG PINS
Vout=(R1/R2 + 1)*0.6
2.85V
1V8 SUPPLY
1.3V SUPPLY
VOUT = (R1+R2)/R2 * 0.8
USB OTG SWITCH
1V5 SUPPLY
1.5V

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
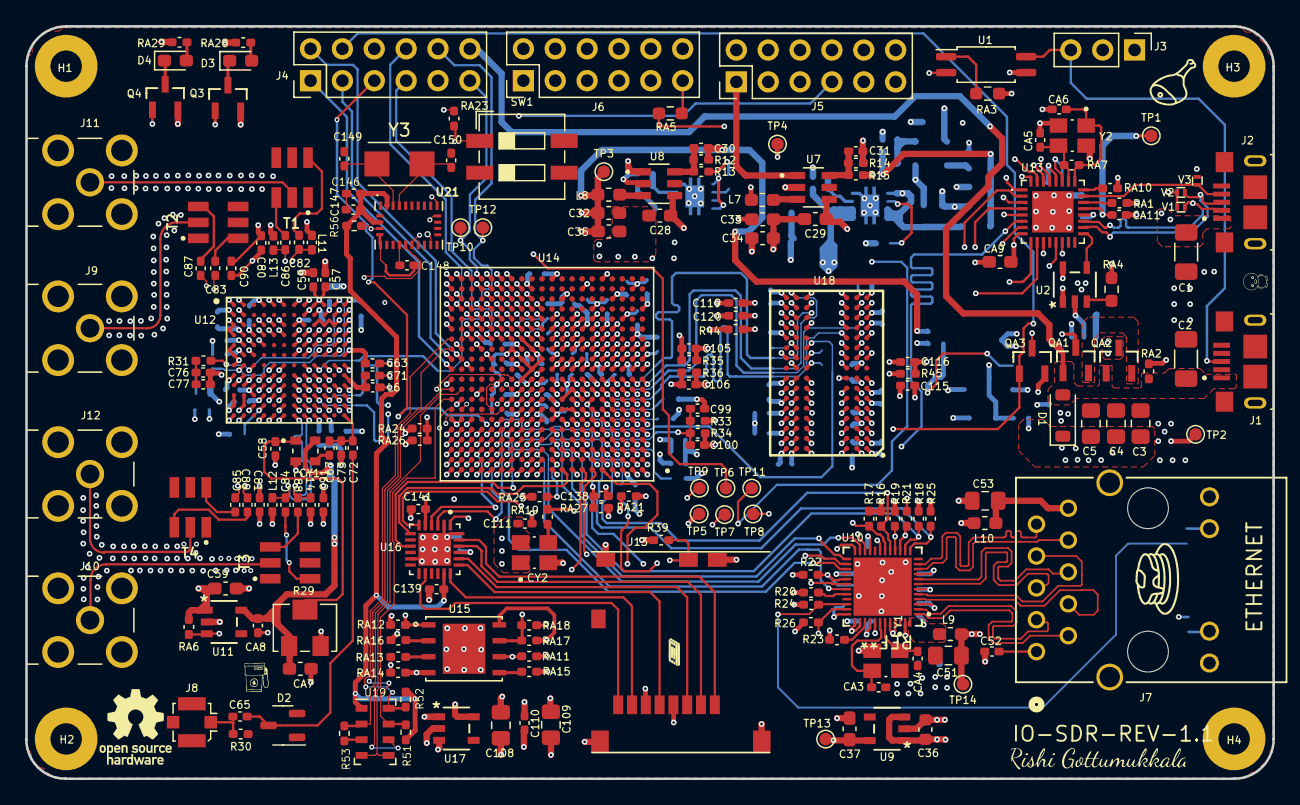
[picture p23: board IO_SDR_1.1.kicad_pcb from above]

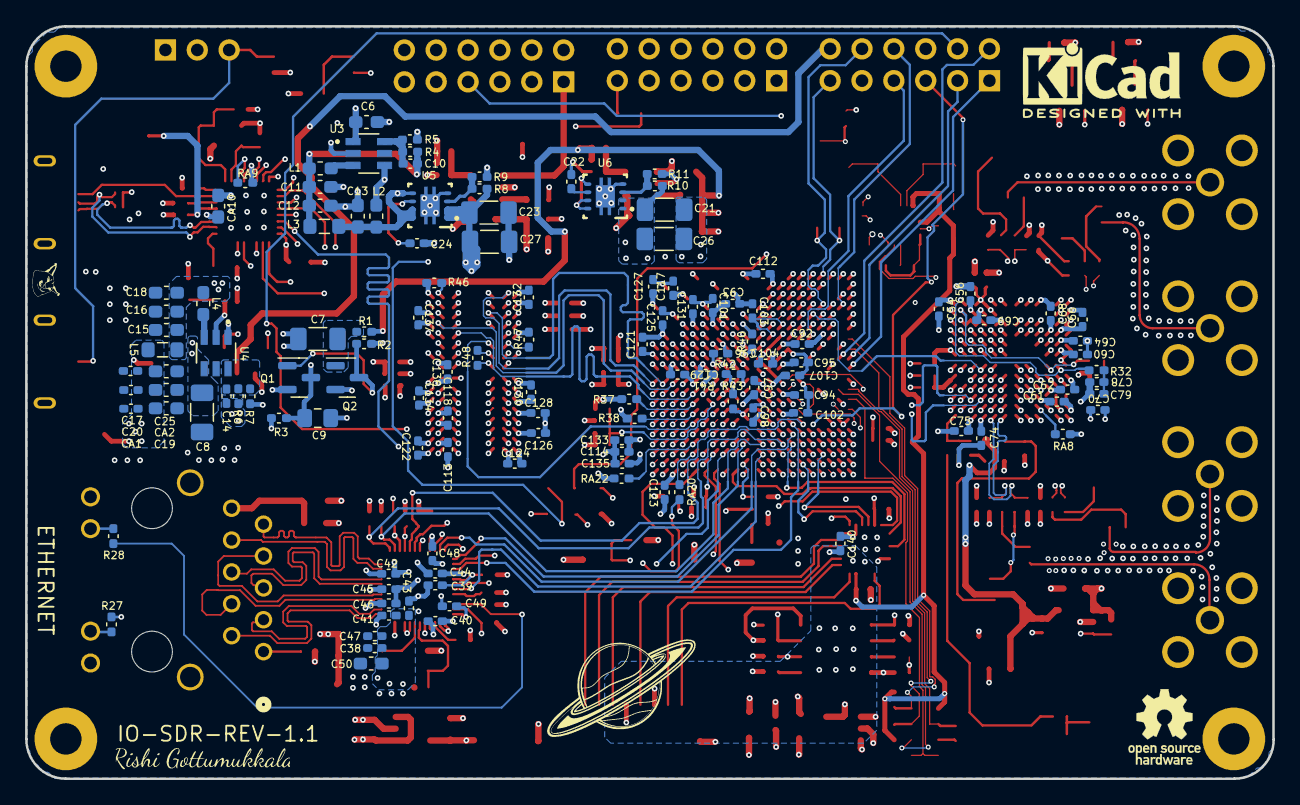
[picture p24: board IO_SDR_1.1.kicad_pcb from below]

Board: 8 copper layers, 99.4 x 60.0 mm, 327 parts (125 on the bottom side), 299 nets.

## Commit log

2023-12-16 Progress and Commit
    Progress and Commit
    [AD9361.kicad_sch, ETHERNET.kicad_sch, Help.xlsx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]
2023-12-17 Added
    Added
    [ETHERNET.kicad_sch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]
2023-12-18 Big Cleanup
    Big Cleanup
    [ETHERNET.kicad_sch, IO-SDR_Rev_1.0.kicad_sch, SENSORS.kicad_sch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]
2023-12-18 Added labels, need to do power last
    Added labels, need to do power last
    [POWER.kicad_sch, XC7Z010.kicad_sch]
2024-01-25 1.1 revision
    1.1 revision
    [AD9361.kicad_sch, ETHERNET.kicad_sch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]
2024-01-25 Added Balun 3D models + fixes
    Added Balun 3D models + fixes
    [IO_SDR_1.1.kicad_pcb, bom.csv, designators.csv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]
2024-02-07 Fixing prod files
    Fixing prod files
    [IO_SDR_1.1.kicad_sch, Sheet1.kicad_sch, Sheet2.kicad_sch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]
2024-02-08 Added ferrite bead cores
    Added ferrite bead cores
    [bom.csv]
